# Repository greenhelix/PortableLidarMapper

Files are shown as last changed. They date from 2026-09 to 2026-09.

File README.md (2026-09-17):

# Portable LiDAR Mapper

> RPLIDAR C1 + Orange Pi 4 Pro + IMU를 백팩 어깨끈에 마운트하고 다니며 실내 2D 지도(로봇청소기 수준)와 실외 GPS 경로를 기록하는 개인용 프로젝트. (초기엔 텀블러형 케이스 구상이었으나 2026-09-16 어깨끈 마운트 방식으로 방향 전환 — 하단 폼팩터 히스토리 참고)

**현재 단계: Phase 1 — PC + 고정 공간에서 SLAM 파라미터 품질 검증 중** (보드 미도착, `docker/` 환경으로 PC에서 선개발).
상세 아키텍처/로드맵은 [`README_ARCHITECTURE.md`](./README_ARCHITECTURE.md), 세션별 작업 기록은 [`devlog/`](./devlog)를 참고.

---

## 개발 단계 (Phase)

| | **Phase 1 (현재)** | **Phase 2 (보드 도착 후)** |
|---|---|---|
| 장소 | PC + **고정된 한 공간** | 실내외 휴대 이동 |
| 목적 | SLAM/오도메트리 파라미터 품질 검증 | 실제 지도 생성 |
| 주 시각화 도구 | RViz2 (정밀 디버깅, `docker/run_dev.sh --rviz`) | Foxglove (폰 원격 접속) |
| 보드 | 없음 (PC로 대체) | Orange Pi 4 Pro 4GB |
| 다음 하드웨어 할 일 | — | 구매 → `hardware/orange_pi_4_pro_bringup_risks.md` 절차대로 이식 |
| Flutter 앱 | 우선순위 낮음 (스캐폴딩만) | 본격 개발 시작 |
| IMU(관성 측정 장치) 추가 | 안 함 (모듈 선정만 완료 — 9축, DFRobot SEN0374 추천) | 실제 장착 + `robot_localization`(EKF) 센서퓨전 연동 |

전환 조건: Orange Pi 4 Pro 구매 + 도착. 상세 이식 절차는 [`hardware/orange_pi_4_pro_bringup_risks.md`](./hardware/orange_pi_4_pro_bringup_risks.md).

**Phase 2는 하드웨어 도착 순서에 맞춰 페이지 0~3으로 더 세분화했습니다** (앱 개발은 rosbridge 프로토콜이 PC/보드 동일해서 오렌지파이 도착을 안 기다리고 지금부터 시작): 페이지0(지금, PC로 앱 선개발) → 페이지1(오렌지파이 도착, 라이다 재부착) → 페이지2(IMU 도착, 센서퓨전+휴대성 테스트) → 페이지3(물리버튼+실사용 필드 테스트+백엔드 구현). 상세는 [`README_ARCHITECTURE.md`](./README_ARCHITECTURE.md) 5.5번.

## 소프트웨어 아키텍처

이 프로젝트는 4가지 설계 원칙 위에 서 있습니다.

1. **레이어드 구조** — 하드웨어 → 드라이버 → ROS2 미들웨어(오도메트리/SLAM) → 데이터
   저장 → 시각화, 5개 계층으로 나뉘고 **계층 간 통신은 오직 ROS2 토픽/메시지로만**
   이루어집니다. 직접 함수를 호출하는 계층 간 결합이 없습니다.
2. **노드 단위 분리(교체 가능성)** — 라이다 드라이버, 오도메트리, SLAM, DB 로깅,
   AI 요약이 각각 독립된 ROS2 노드(프로세스)입니다. 그래서 라이다를
   mock ↔ 실기로, AI 모델을 provider 하나만 바꿔서 교체해도 **다른 코드는 무수정**입니다.
3. **환경 독립성(Docker)** — ROS2/SLAM 전부 Docker 컨테이너 안에서 돌기 때문에,
   호스트가 PC(Ubuntu 20.04)든 나중에 Orange Pi 4 Pro든 **같은 이미지가 그대로
   이식**됩니다. 이게 보드를 라즈베리파이→오렌지파이로 바꿔도 코드 리스크가 적었던
   핵심 이유입니다.
4. **어댑터 패턴** — `ai/`의 `AIProvider` 인터페이스처럼, 하드웨어·모델 종류를
   구체 구현이 아니라 인터페이스로 감싸서 나중에 무엇으로 바뀌어도 갈아끼우기만
   하면 되게 설계합니다.

전체 계층 구조, 각 계층의 책임, ROS2 노드 그래프, 데이터 저장 형식까지의 상세
내용은 [`README_ARCHITECTURE.md`](./README_ARCHITECTURE.md)에 있습니다 — 이 README는
요약이고, 그 문서가 정본입니다.

## 데이터 흐름

```mermaid
flowchart TD
    LIDAR["📡 RPLIDAR C1<br/>USB · 460800bps"] --> SLLIDAR["sllidar_node<br/>(실기 드라이버)"]
    MOCK["mock_scan_publisher<br/>(개발용 가짜 데이터)"] -.-> SCAN
    SLLIDAR --> SCAN(("/scan"))

    SCAN --> RF2O["rf2o_laser_odometry<br/>(스캔 기반 오도메트리)"]
    RF2O -- "odom→base_footprint (동적)" --> SLAM["slam_toolbox<br/>(SLAM)"]
    SLAM -- "map→odom" --> SLAM
    SLAM --> MAP(("/map"))

    MAP --> BRIDGE["rosbridge + rosapi<br/>:9090"]
    BRIDGE --> FOX["📱 Foxglove<br/>(브라우저/앱)"]
    BRIDGE -.-> APP["lidar_mapper_app<br/>(Flutter, 미연결)"]

    CLI["ros2 topic pub<br/>(수동 트리거)"] -.-> LOGGER["session_logger_node"]
    LOGGER --> AI["ai/ provider<br/>(NullProvider, 교체 가능)"]
    AI --> DB[("🗄️ SQLite<br/>data/rooms.db")]
```

실선 = 지금 자동으로 동작 확인된 경로. 점선 = 코드는 있지만 수동 트리거이거나(우측 DB 경로) 아직 연결 전(Flutter 앱).

## 확장 설계 — Flutter 앱 + 데이터 동기화 (2026-09-15, 설계 확정·구현 예정)

Phase 2(보드 도착 후 실사용)를 대비해 앱/백엔드 확장 구조를 설계했습니다. **아직 코드는 없고 설계만 확정된 상태**이며, 상세 내용은 [`README_ARCHITECTURE.md`](./README_ARCHITECTURE.md) 3.5번을 참고하세요.

- **온디맨드 연결 모델**: Orange Pi는 폰 연결 여부와 무관하게 자율로 계속 수집하고, 폰은 배터리 절약을 위해 평소엔 연결을 끊어두다가 확인하고 싶을 때만 붙는 구조.
- **Store-and-Forward(저장 후 전송)**: 오프라인(산속/지하 등)에서도 로컬 SQLite에 항상 먼저 저장하고, 연결되면 자동으로 PC DB에 밀린 데이터를 전송. [다이어그램](https://claude.ai/code/artifact/0686cb80-b7e4-421b-a3e3-a1d0db071f2b)
- **관계형 DB 스키마**: `locations`(장소) + `building_details`/`mountain_details`(장소 종류별 세부정보) + `sessions`(방문 기록)로 실내/실외를 하나의 스키마로 관리. [다이어그램](https://claude.ai/code/artifact/187c3b2d-13b7-421d-bd72-93b475922707)
- **진화형 지도 축적**: 같은 장소를 여러 번 방문해도 slam_toolbox의 `serialize_map`/`deserialize_map`으로 이전 지도에 이어서 매핑 — 재방문 데이터를 중복이 아니라 완성도를 높이는 히스토리로 누적.
- **라이다 한계 극복 전략**: 텀블러+가방 옆주머니 장착 특성상 생기는 가림각·회전오차·도보속도 문제를 `laser_filters`(ROS2 표준 필터 체인) + `robot_localization`(EKF 센서퓨전)으로 대응. [EKF 원리 그림](https://claude.ai/code/artifact/56d51d00-6c3a-4580-b798-53d9f7a12807)

### Flutter 앱 개발 진행 중 (2026-09-17~)
`app/lidar_mapper_app`에서 Tier1 기능부터 구현 시작. 연결 화면(rosbridge)은 코드
작성 완료, 나머지는 진행 중.

- **스캔/노이즈필터/누적지도 화면 데모 컨셉**: [인터랙티브 프리뷰](https://claude.ai/code/artifact/596148a7-35da-4410-bd0f-bc0dce5fa559)
  (원본 백업: [`app/lidar_mapper_app/demo/scan_monitor_preview.html`](./app/lidar_mapper_app/demo/scan_monitor_preview.html),
  링크는 비공개 상태 — 공유하려면 아티팩트 페이지에서 직접 "공유" 켤 것) —
  실제 데이터 대신 가짜 데이터로 Flutter `CustomPainter` 구현 시 예상되는 동작을
  미리 시연(Hz 슬라이더로 스캔속도-해상도 트레이드오프 확인, 벽처럼 보이는
  반사 노이즈를 탭으로 제거, 등산로/실내 환경 전환, 기기 이동에 따른 사각지대
  해소까지 재현).
- **앱 네비게이션 구조(하단 탭 4개: 홈/트래킹/목록/설정)**: 상세는
  [`README_ARCHITECTURE.md`](./README_ARCHITECTURE.md) 3.5.9번.

## 빠른 시작 (Docker)

```bash
# 최초 1회: 이미지 빌드
./docker/run_dev.sh --build

# mock 데이터로 파이프라인만 검증 (라이다 없이도 가능)
./docker/run_dev.sh
ros2 launch lidar_mapper_bringup bringup.launch.py use_mock:=true

# 실제 RPLIDAR C1 연결 시
./docker/run_dev.sh --with-lidar
ros2 launch lidar_mapper_bringup bringup.launch.py use_mock:=false lidar_serial_port:=/dev/ttyUSB1

# 고정 공간 정밀 디버깅용 RViz2 (PC 전용, X11 필요)
./docker/run_dev.sh --with-lidar --rviz
```

시각화는 `ws://localhost:9090`으로 [Foxglove](https://studio.foxglove.dev)에 접속하거나, 위 `--rviz` 옵션으로 RViz2를 띄우면 됩니다. 자세한 사용법은 [`docker/README.md`](./docker/README.md).

## 하드웨어

| 부품 | 내용 |
|---|---|
| 센서 | RPLIDAR C1 |
| 보드 | Orange Pi 4 Pro 4GB (Allwinner A733) — **구매 완료(배송 중, 2026-09-11)**, 상세는 [`hardware/board_price_tracking.md`](./hardware/board_price_tracking.md) |
| 폼팩터 | **백팩 어깨끈 마운트**(GoPro 표준 커넥터 방식) — 라이다+IMU 판은 어깨끈에, Orange Pi+배터리는 가방 내부에. 2026-09-16 확정, 상세는 아래 폼팩터 히스토리 참고 |

**완성 예상 컨셉 (렌더링 목업)**:

<table>
<tr>
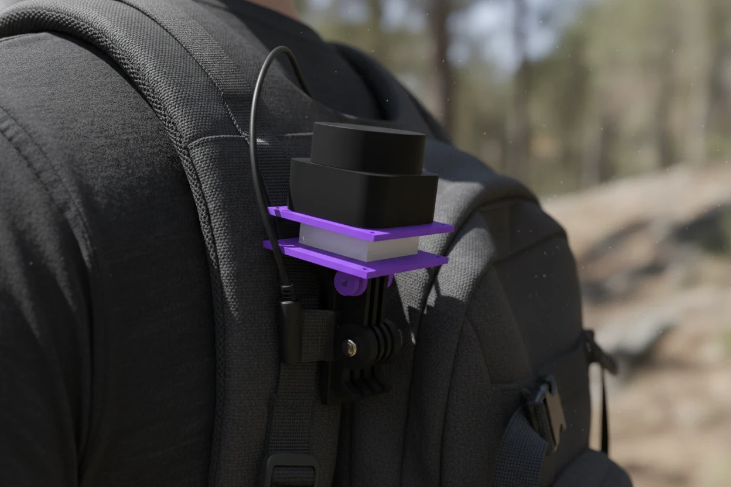
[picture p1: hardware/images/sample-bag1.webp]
어깨끈에 장착된 최종 목업 렌더링 — 근접
<td></td>
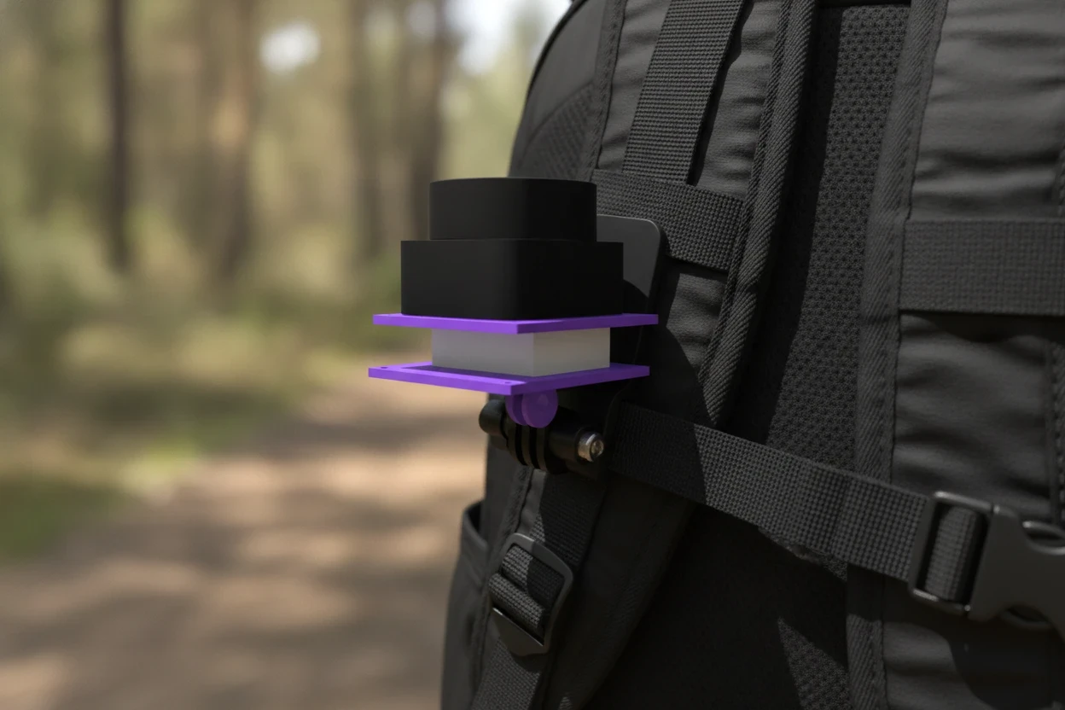
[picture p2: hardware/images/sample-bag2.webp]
어깨끈에 장착된 최종 목업 렌더링 — 전체
<td></td>
</tr>
</table>

### 폼팩터 검토 히스토리 (텀블러 → 어깨끈 마운트)

<details>
<summary><b>펼쳐서 전체 히스토리 보기</b> (스케치, 개념도, 검토 순서)</summary>

처음엔 **텀블러형 케이스**(라이다+보드+배터리를 원통 하나에 전부 내장, 백팩 옆주머니에 삽입)로 시작했으나, 몸/가방에 의한 가림각 문제와 특정 가방 치수 종속 문제 때문에 **어깨끈 마운트 분리형**(가벼운 센서 헤드만 어깨끈에, 무거운 보드+배터리는 가방 내부에)으로 방향을 바꿨습니다. 텀블러 개념 자체는 폐기하지 않고 계속 참고 자료로 남겨뒀습니다.

**1. 텀블러형 (초기 개념)**

텀블러형 케이스 개념도

라이다(위)-Orange Pi-배터리(아래) 순으로 원통 하나에 쌓는 구조. [상세 CAD](./hardware/cad/tumbler_shell_v2.scad)

사용자 스케치:
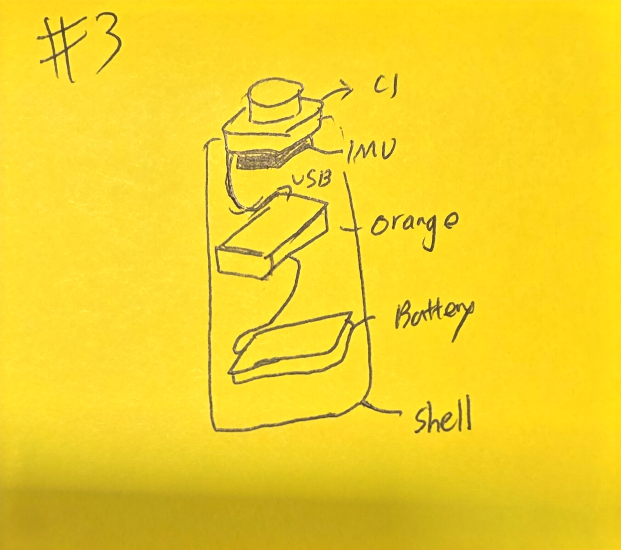
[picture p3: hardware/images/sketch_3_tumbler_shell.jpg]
사용자 스케치 3
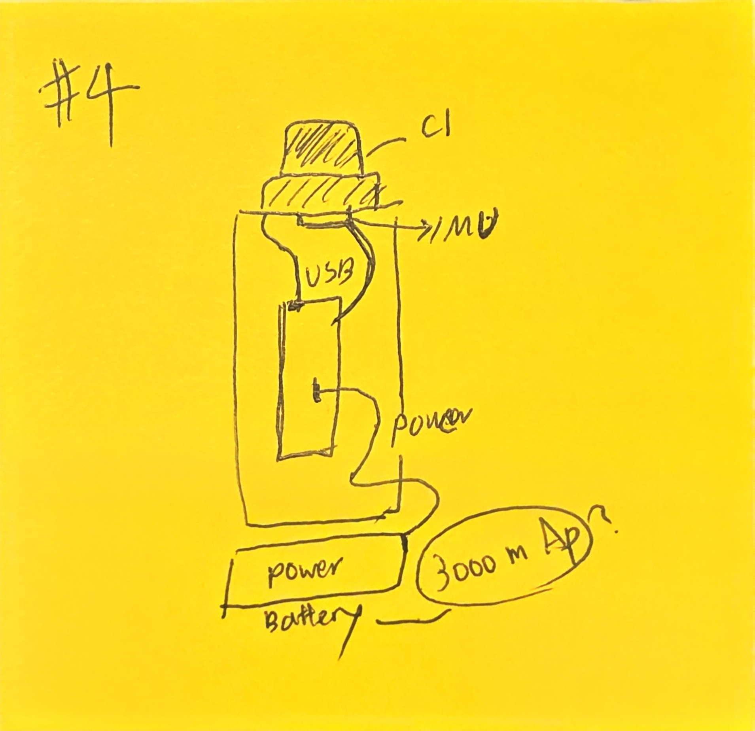
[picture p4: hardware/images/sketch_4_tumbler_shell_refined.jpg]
사용자 스케치 4(정리본)
 

**2. 중간 검토 — 어깨끈 분리형 여러 방식 비교**

어깨끈 마운트 개념도

가방 손잡이 관통형, 벨크로 클램프형, 목뒤 끈 수렴점형 등을 비교 검토. [전체 비교 아티팩트](https://claude.ai/code/artifact/8a0e3fea-5cf3-4b3d-bbbd-aff2ba56d551)

사용자 스케치:
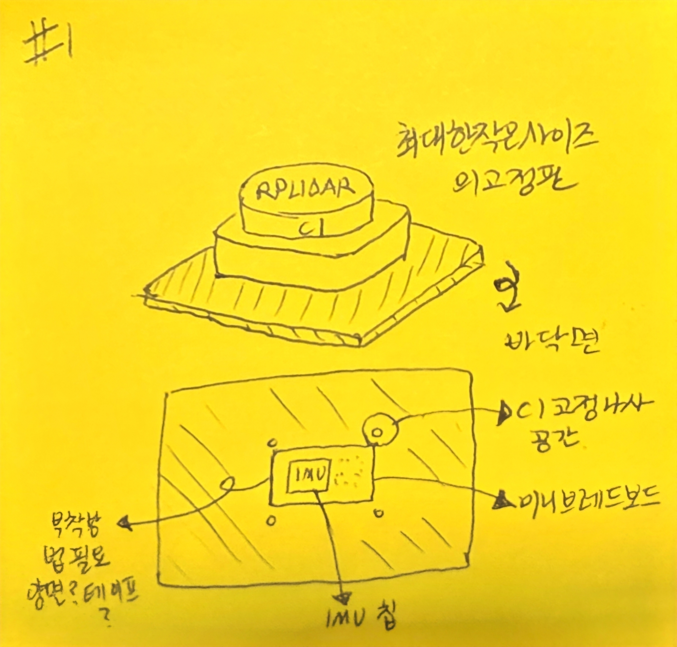
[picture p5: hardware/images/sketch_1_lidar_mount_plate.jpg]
사용자 스케치 1(마운트판)
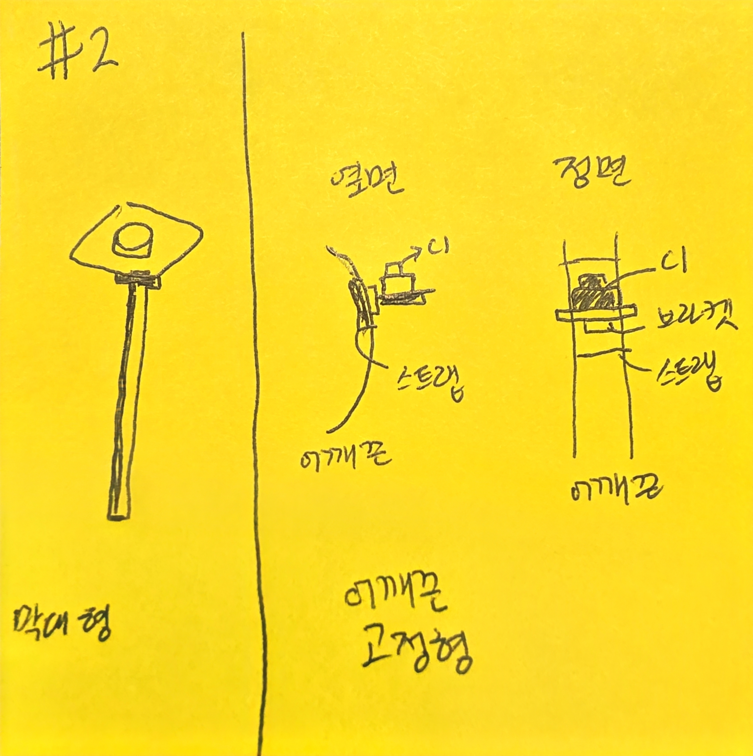
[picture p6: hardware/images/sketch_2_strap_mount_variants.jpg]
사용자 스케치 2(어깨끈 변형들)
 

**3. 최종 — GoPro 표준 커넥터 방식 (2026-09-16 확정)**

시중 GoPro 호환 어깨끈 마운트(볼조인트 없는 평버클+관통볼트 방식)를 구매해서 사용, 우리는 그 규격에 맞는 라이다+IMU 판만 제작. [상세 CAD](./hardware/cad/mount_plate_and_case_v1.scad)

구매한 실제 상용 마운트(360° 호환 표기 제품, 실제로는 평버클+관통볼트 방식):

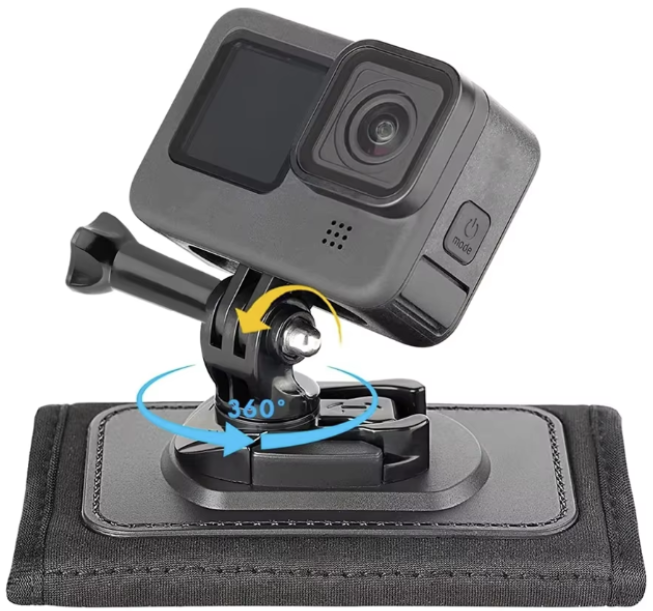
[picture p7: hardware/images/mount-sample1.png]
구매한 GoPro 호환 어깨끈 마운트 제품 사진


Shapr3D로 직접 설계한 라이다+IMU 판 (판 2장 사이 샌드위치 구조 + GoPro 커넥터):

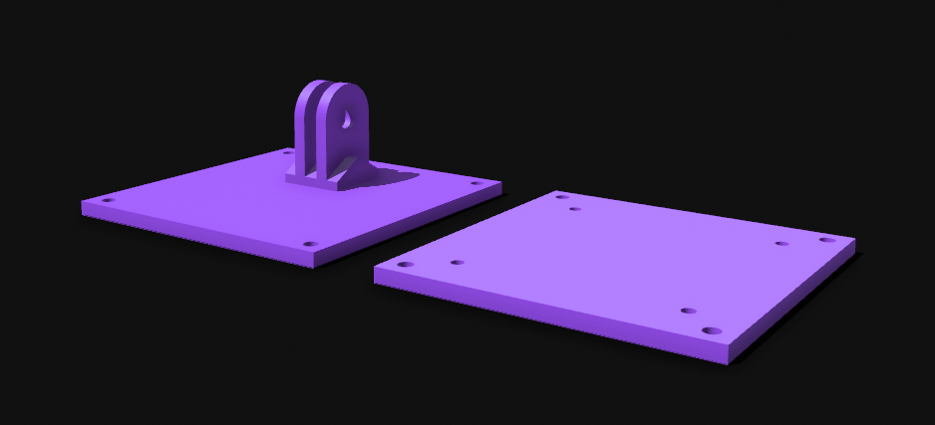
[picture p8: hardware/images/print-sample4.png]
Shapr3D로 설계한 최종 마운트 판 렌더링


가방 장착 목업은 위 "완성 예상 컨셉" 참고.

> 더 많은 각도/중간 검토 단계 사진(`mount-sample2,3`, `print-sample1~5` 등)은 `hardware/images/` 폴더에 전부 보관되어 있습니다.

</details>

## 저장소 구조

| 경로 | 내용 |
|---|---|
| `src/` | ROS2 워크스페이스 — `lidar_mapper_bringup`(launch 통합), `lidar_mapper_mock`(가짜 /scan), `lidar_mapper_db`(세션 로깅) |
| `ai/` | AI provider 어댑터 (`AIProvider` 인터페이스 + `NullProvider`, provider 이름만 바꾸면 모델 교체) |
| `app/lidar_mapper_app/` | Flutter 모바일 뷰어 (스캐폴딩, 아직 rosbridge 미연결) |
| `docker/` | 개발 환경 (Dockerfile, `run_dev.sh`, RViz2/Foxglove 가이드) |
| `config/` | slam_toolbox 파라미터, RViz2 기본 레이아웃 |
| `hardware/` | 텀블러 마운트 설계, 보드 가격/스펙 비교·리스크 조사 |
| `devlog/` | 세션별 개발 로그 (매 세션 시작 시 최신 로그부터 읽을 것) |
| `data/` `maps/` `bags/` | 런타임 산출물 (SQLite, 지도 파일, rosbag) |

## 문서 갱신 원칙

이 README와 `README_ARCHITECTURE.md`는 프로젝트의 첫 화면이자 최신 상태를 보여주는 문서입니다.
**구조가 바뀌거나(새 패키지/폴더), 하드웨어 결정이 바뀌거나, 개발 단계(Phase)가 넘어갈 때마다 반드시 갱신**합니다.
다이어그램은 Mermaid로 관리해서(이미지 파일 대신) 코드처럼 diff로 리뷰하고 계속 최신 상태를 유지합니다.

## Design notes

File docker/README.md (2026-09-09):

# 개발 환경 (Docker) 사용 가이드

PC(Ubuntu 20.04)와 Pi5(예정: Ubuntu 22.04 계열)의 배포판이 달라서,
호스트 OS에 ROS2를 직접 설치하지 않고 **Docker 컨테이너 안에서 ROS2 Humble
(Ubuntu 22.04 기반)로 통일**해서 개발한다. 이렇게 하면:

- 호스트 OS(20.04)를 건드리지 않는다.
- Pi5가 22.04 계열을 쓴다면 이 이미지를 그대로 옮겨서 이식 가능.
- WSL/Mac에서도 같은 이미지로 동일한 개발 경험을 유지할 수 있다.

## 공통 사용법

```bash
# 최초 1회 (또는 Dockerfile 수정 후) 이미지 빌드
./docker/run_dev.sh --build

# 이후에는 mock 전용 실행
./docker/run_dev.sh

# 컨테이너 진입 후 (최초 1회)
cd /lidar_ws
colcon build --symlink-install
source install/setup.bash

# mock 파이프라인 실행 예시
ros2 launch lidar_mapper_bringup bringup.launch.py use_mock:=true
```

Foxglove는 컨테이너의 `9090` 포트(rosbridge websocket)를 호스트에 그대로
publish 하므로, 호스트 브라우저/앱에서 `ws://localhost:9090`으로 접속하면 된다.

## 환경별 차이

### PC (Ubuntu 20.04, 라이다 물리 연결) — 메인 개발 환경
```bash
./docker/run_dev.sh --with-lidar
# 컨테이너 안에서:
ros2 launch lidar_mapper_bringup bringup.launch.py use_mock:=false lidar_serial_port:=/dev/ttyUSB1
```
`/dev/ttyUSB0`, `/dev/ttyUSB1`, `/dev/ttyACM0` 중 존재하는 장치를 자동으로
컨테이너에 패스스루하고, `dialout` 그룹 권한도 같이 넘겨서(`--group-add`) 실제
시리얼 포트를 열 수 있게 한다. 실제 RPLIDAR C1 테스트는 여기서만 진행한다.

**라이다가 응답 없어지면**: `sllidar_node`가 비정상 종료된 직후 장치가 응답
불가 상태로 걸릴 수 있다(실제로 한 번 겪음). 이럴 땐 소프트웨어로 재시도해도
안 풀리고, **USB 케이블을 뽑았다 다시 꽂으면** 정상 복구된다.

### RViz2 — 고정 공간 정밀 디버깅 전용 (Pi5 도착 전 Phase 1)
Pi5가 없어서 지금은 라이다를 한 자리에 고정해두고 SLAM/오도메트리 파라미터
품질을 다듬는 단계다. 이 단계에선 Foxglove보다 **RViz2가 더 정확하다** — 색상이
임의로 커스텀되지 않고 기본이 흑백(점유=검정/빈공간=흰색/미지=회색)이라
"이게 벽인지 빈 공간인지" 헷갈릴 일이 없다. 다만 RViz2는 웹앱이 아니라 로컬 GUI라
휴대 단계(Phase 2)에서 폰으로 보는 용도로는 못 쓴다 — 그건 계속 Foxglove가 담당.

```bash
xhost +local:docker   # 호스트에서 최초 1회 (컨테이너가 화면에 그릴 수 있게 허용)
./docker/run_dev.sh --with-lidar --rviz
# 컨테이너 안에서 (별도 터미널로 docker exec 하거나 & 로 백그라운드 실행):
rviz2 -d /lidar_ws/config/rviz_default.rviz
```
`config/rviz_default.rviz`에 Map/LaserScan/TF/Grid 디스플레이가 미리 설정되어
있어서 매번 수동으로 추가할 필요 없다.

**컨테이너를 오래 켜둔 채로 방치하지 말 것.** 며칠씩 방치하면 그 사이 쌓인
오래된 로그/누적 맵을 "방금 테스트한 결과"로 착각해서 잘못된 진단을 하게 된다
(2026-09-04~07 세션에서 실제로 겪음). 테스트 전엔 항상 컨테이너를 재시작해서
깨끗한 상태로 시작할 것.

### WSL2 — 코드 검증용, 실기 테스트는 선택사항
Docker 자체는 WSL2에서도 동일하게 동작하지만, USB 장치는 기본적으로
Windows가 점유하고 있어서 WSL 컨테이너에 바로 안 보인다.

- **mock 전용으로만 쓸 경우**: 추가 설정 없이 `./docker/run_dev.sh` 그대로 사용.
- **실제 라이다까지 WSL에서 테스트하고 싶을 경우**: Windows에
  [`usbipd-win`](https://github.com/dorssel/usbipd-win)을 설치하고,
  ```powershell
  usbipd list
  usbipd bind --busid <라이다 버스ID>
  usbipd attach --wsl --busid <라이다 버스ID>
  ```
  로 WSL에 장치를 붙인 다음 `./docker/run_dev.sh --with-lidar`를 실행한다.
  다만 안정성이 PC 네이티브보다 떨어지므로 필수 워크플로는 아니다.

### Mac (Apple Silicon/Intel) — mock 개발 + Foxglove 원격 시각화 전용
Docker Desktop for Mac은 컨테이너가 Linux VM 안에서 돌기 때문에 **물리 USB
패스스루를 지원하지 않는다.** 따라서 Mac에서는:

1. `./docker/run_dev.sh` (옵션 없이, mock만)로 파이프라인 로직/코드 작업.
2. 실기 검증은 PC에서 진행 중인 컨테이너에 원격으로 붙어서 확인:
   - PC의 rosbridge(9090)에 같은 네트워크에서 `ws://<PC IP>:9090`으로
     Foxglove 접속 → 실시간 지도 확인.
   - 코드 자체는 Claude Code 원격 세션/SSH로 PC에 붙어서 편집·실행.

## 참고
- `scripts/setup_env.sh`는 호스트에 직접 ROS2를 설치하는 옛 방식(참고/백업용)이며,
  현재 권장 경로는 이 Docker 방식이다.
- 이미지 안 배포판은 `ros:humble-ros-base` (Ubuntu 22.04) 기준.

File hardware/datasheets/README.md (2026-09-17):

# 부품 데이터시트 모음

이 프로젝트에서 실제 사용하는 부품들의 공식 데이터시트/매뉴얼을 모아둔 폴더.
링크가 죽거나 회사가 문서를 내려도 로컬에 원본이 남아있도록 보관.

| 파일 | 부품 | 출처 | 비고 |
|---|---|---|---|
| `rplidar_c1_datasheet.pdf` | RPLIDAR C1 (라이다 센서) | SLAMTEC 공식, 2024-03-12 rev.1.1 | 마운트 나사 규격(M2.5, 43x43mm, 삽입깊이 4mm 이하) 여기서 확인 |
| `bno055_datasheet.pdf` | BNO055 칩 (IMU, CJMCU-055 모듈에 탑재) | Bosch Sensortec 공식 | I2C 주소, 센서 스펙, 레지스터 맵 등 |
| `orange_pi_4_pro_user_manual_v1.4.pdf` | Orange Pi 4 Pro (메인보드) | Shenzhen Xunlong(orangepi.net) 공식 | **40핀 GPIO 핀맵(3.15절)**, ROS2 Humble 설치법(3.26.1절), Docker 설치법(3.22절), 발열 모니터링 명령(3.14절) 등 실전 절차 다수 포함 |

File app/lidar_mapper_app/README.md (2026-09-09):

# lidar_mapper_app

A new Flutter project.

## Getting Started

This project is a starting point for a Flutter application.

A few resources to get you started if this is your first Flutter project:

- [Learn Flutter](https://docs.flutter.dev/get-started/learn-flutter)
- [Write your first Flutter app](https://docs.flutter.dev/get-started/codelab)
- [Flutter learning resources](https://docs.flutter.dev/reference/learning-resources)

For help getting started with Flutter development, view the
[online documentation](https://docs.flutter.dev/), which offers tutorials,
samples, guidance on mobile development, and a full API reference.

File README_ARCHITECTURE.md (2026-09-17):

# 휴대용 라이다 지도 생성기 — 아키텍처 문서

> 텀블러형 케이스에 RPLIDAR C1 + Orange Pi 4 Pro를 장착하고 들고 다니며
> 실내 2D 지도(로봇청소기 수준) + 실외 GPS 경로를 기록하는 개인용 프로젝트

이 문서는 지금까지 확정된 내용을 기반으로 **하드웨어 → 소프트웨어 → 데이터 → 개발 프로세스** 전체를 구조화한다.
장비(보드)가 아직 없는 상태이므로, PC Ubuntu에서 먼저 100% 동일한 구조로 개발하고
보드가 도착하면 코드 변경 없이 이식하는 것을 목표로 설계한다.

---

## 0. 확정 사항 요약

| 항목 | 내용 |
|---|---|
| 센서 | RPLIDAR C1 (구매 완료) |
| 보드 | **Orange Pi 4 Pro 4GB** (Allwinner A733, 2x A76+6x A55) — 2026-09-08 결정, **2026-09-11 구매 완료(배송 중)**. Raspberry Pi 5에서 변경 (아래 사유 참고) |
| 폼팩터 | 텀블러형 케이스, 백팩 측면 포켓 휴대 |
| 목적 | 실내 2D SLAM 지도 + 실외 GPS 경로 기록 |
| SW 스택 | ROS2 Humble + slam_toolbox + rosbridge + Foxglove |
| 개발 순서 | PC Ubuntu 선개발 → 보드 도착 시 이식 |
| 개발 환경 | Docker (`docker/`) — PC 호스트 OS(20.04)와 무관하게 컨테이너 안에서 Ubuntu22.04+Humble로 통일. 상세: `docker/README.md` |

---

## 1. 레이어드 시스템 아키텍처

시스템은 5개 계층으로 나눈다. 각 계층은 독립적으로 테스트 가능해야 하며,
상위 계층은 하위 계층의 인터페이스(ROS2 토픽)에만 의존한다. 이렇게 하면
라이다가 없어도 3~5계층을 mock 데이터로 그대로 개발할 수 있다.

```
5. 시각화/앱     Foxglove(스마트폰) / RViz2(PC)
                        ▲  WebSocket
4. 저장/데이터    SQLite(방/가구) / 맵 파일(pgm,yaml) / devlog
                        ▲
3. ROS2 미들웨어  /scan → slam_toolbox → map_saver
                        ▲  LaserScan msg
2. 드라이버/통신  sllidar_ros2 (USB) / GPS 브릿지(MQTT)
                        ▲
1. 하드웨어       RPLIDAR C1 / Orange Pi 4 Pro / 전원부·GPS모듈
```

**핵심 설계 원칙**
- 계층 간 통신은 오직 **ROS2 토픽/메시지**로만 이루어진다 (직접 함수 호출 금지) → 나중에 라이다를 mock에서 실제 센서로 바꿔도 상위 계층 코드는 무수정.
- 3계층(SLAM)까지는 순수 소프트웨어이므로 **하드웨어 없이 100% 개발 가능**.
- 1~2계층만 하드웨어 의존적이며, 도착 즉시 교체(mock → real)한다.

---

## 2. 하드웨어 설계도

### 2.1 텀블러 마운트 단면 구조 (개념도)

```
        ┌────────────────┐  ← 상단 캡 (평탄화 디스크, 3D프린팅)
        │  ⊙ RPLIDAR C1   │     라이다 스캔 평면이 지면과 평행 유지
        │   (지름 ~75mm)  │     360도 스캔, 케이블 하단으로 관통
        ├────────────────┤
        │                │
        │   텀블러 몸체    │  ← 기존 텀블러/보온병 재활용 or 원통 케이스
        │  (단열재 제거)   │
        │                │
        ├────────────────┤
        │ Orange Pi 4 Pro │  ← 무게 중심을 낮추기 위해 하단 배치
        │  + 보조배터리    │
        └────────────────┘
              │
        백팩 측면 포켓에 수직으로 삽입
```

### 2.2 부품 리스트 & 배치 원칙

| 부품 | 배치 위치 | 이유 |
|---|---|---|
| RPLIDAR C1 | 최상단 | 360도 스캔 시야 확보, 몸/배낭에 가려지지 않게 |
| 평탄화 디스크 | 라이다 바로 아래 | 원통 뚜껑 곡면 위에서도 스캔 평면 수평 유지 |
| Orange Pi 4 Pro | 중~하단 | 발열 방출 공간 확보, 무게중심 하향 (발열이 큰 편이라 액티브 쿨링 필수 — `hardware/orange_pi_4_pro_bringup_risks.md` 참고) |
| 보조배터리 | 최하단 | 가장 무거운 부품 → 무게중심 안정화 |
| USB 케이블(라이다-보드) | 내부 관통홀 | 외부 노출 시 걸림/단선 위험 |
| GPS | 별도 (스마트폰 앱) | 자체 GPS 모듈 대신 스마트폰 GPS를 Wi-Fi/MQTT로 수신 (실내 GPS 무의미) |

### 2.3 검증해야 할 물리 제약
- **수평 유지가 핵심**: 라이다 스캔 평면이 기울면 SLAM 정확도 급락 → 텀블러가 기울어져도 라이다 마운트 자체는 수평 고정되는 짐벌/평탄화 구조 필요
- **진동은 허용, 기울기는 비허용**: 걷는 진동(좌우 흔들림)은 SLAM이 누적 보정 가능하지만 지속적 틸트는 누적 오차 유발
- **발열**: 보드(Orange Pi 4 Pro) + SLAM 연산 시 발열 있음(실제 리뷰로 확인된 리스크,
  `hardware/orange_pi_4_pro_bringup_risks.md` 참고) → 방열판/액티브 쿨러 필수, 밀폐 케이스 지양

> 상세 치수(C1 지름 75mm 기준 마운트 설계)는 실측 후 `hardware/tumbler_mount_design.md`에 업데이트 예정.

---

## 3. 소프트웨어 아키텍처 (ROS2 노드 그래프)

```
┌─────────────────┐    /scan (sensor_msgs/LaserScan)
│  sllidar_node    │ ────────────────────────────┐
│ (실제 C1 or Mock) │                              ▼
└─────────────────┘                    ┌────────────────────┐    /map (nav_msgs/OccupancyGrid)
                                        │  slam_toolbox        │ ──────────────┐
┌─────────────────┐   /gps/fix          │  (online_async)      │               ▼
│  gps_bridge_node │ ──────────────────▶│                       │    ┌─────────────────┐
│ (MQTT 구독)       │                    └────────────────────┘    │  map_saver_cli   │
└─────────────────┘                                                │  → .pgm / .yaml  │
                                                                    └─────────────────┘
                        rosbridge_server (WebSocket :9090)
                                        ▲
                                        │
                          Foxglove (스마트폰 브라우저 접속)
```

**패키지 분리 전략 (ROS2 워크스페이스)**
```
src/
├── lidar_mapper_bringup/   # launch 파일 모음 (실제 하드웨어 + SLAM + rosbridge 통합 실행)
├── lidar_mapper_mock/      # 하드웨어 없이 개발용 가짜 /scan 퍼블리셔
├── lidar_mapper_db/        # /session_event, /session_end 구독 → AI 요약 → SQLite 저장 (2026-09-01 구현)
├── (외부) sllidar_ros2      # RPLIDAR 공식 드라이버 (git clone)
└── (외부) slam_toolbox      # apt 설치
```

이렇게 나누는 이유: `bringup`은 "무엇을 실행할지"만 담당하고,
`mock`은 라이다 없이도 `/scan`을 흉내내는 **개발 전용 패키지**로 완전히 분리한다.
보드+실제 센서가 오면 launch 인자 하나(`use_mock:=false`)로 전환한다.

**저장소 최상위 구성 (2026-09-01 확정)**
```
app/    # Flutter 모바일 뷰어 앱 (app/lidar_mapper_app) — 언어: Dart
ai/     # AI 에이전트 provider 어댑터 자리. AIProvider 인터페이스 + NullProvider 기본값.
        # provider 이름만 바꾸면 Anthropic/OpenAI/중국계(Qwen 등) 어떤 모델로도 교체 가능.
docker/ # 개발 환경 (README_ARCHITECTURE 0번 항목 및 docker/README.md 참고)
```
언어 선택: 엣지·백엔드는 Python(ROS2 기존 스택과 통일), 모바일 앱은 Flutter(Dart, 크로스플랫폼).
마켓플레이스/랭킹/게임화(다중 사용자 데이터 공유)는 사용자가 여러 명이 되는 시점에나 의미가
생기는 확장 아이디어로, 지금 구조에는 반영하지 않고 기록만 해둔다.

---

## 3.5 확장 아키텍처: 온디맨드 연결 · Store-and-Forward · 라이다 한계 극복 · 진화형 지도 (2026-09-15 설계 확정)

Phase 2(보드 도착 후 실사용)를 대비해 Flutter 앱 + 백엔드 확장 구조를 설계했다.
**이 절은 전부 설계만 확정된 상태이고 아직 코드 구현 전**이다 — 5.4번 로드맵에서
진행 상황을 추적한다.

### 3.5.1 용어 정리
- **ROS2 노드**: 독립적으로 실행되는 하나의 프로세스(예: 라이다 드라이버, SLAM).
  노드끼리는 직접 호출하지 않고 **토픽(주제)** 을 통해 메시지를 주고받는다.
- **rosbridge**: ROS2 토픽/서비스를 WebSocket + JSON으로 바꿔서 브라우저/폰
  앱처럼 ROS2를 모르는 외부 클라이언트도 통신할 수 있게 해주는 게이트웨이
  (`:9090` 포트, 로컬망에서만 동작, 인터넷 불필요).
- **SLAM(동시적 위치추정 및 지도작성)**: "내가 어디 있는지"와 "주변 지도가
  어떻게 생겼는지"를 동시에 풀어내는 문제. 이 프로젝트에선 `slam_toolbox`가 담당.
- **오도메트리**: 절대 위치가 아니라 "직전 대비 얼마나 움직였는지"를 추정하는
  것. 바퀴 인코더가 없는 휴대 기기라 `rf2o_laser_odometry`(연속된 라이다 스캔
  비교)로 추정한다.

### 3.5.2 온디맨드 연결 모델 (배터리 절약)
- **Orange Pi = 자율 데이터 수집 엔진**. 폰(또는 물리 버튼)이 명시적으로 "수집
  시작"을 눌러야만 시작하고(부팅만으로 자동 시작 안 함 — 수평/장착 확인 전
  쓰레기 데이터 방지), 시작된 뒤로는 폰 연결 여부와 무관하게 계속 수집한다.
- **폰 = 온디맨드 모니터 + 중개자**. 평소엔 연결을 끊어(핫스팟 OFF) 배터리를
  아끼고, 확인하고 싶을 때만 핫스팟을 켜서 **mDNS(Avahi)** 로 `lidarmapper.local`
  같은 호스트이름을 찾아 접속한다(IP가 매번 바뀌어도 문제없음). 이미 아는
  SSID는 리눅스 NetworkManager가 알아서 재접속하므로 커스텀 코드가 필요 없다.

### 3.5.3 Store-and-Forward (저장 후 전송)
Orange Pi는 네트워크 유무와 무관하게 항상 로컬 SQLite에 먼저 저장(**STORE**)하고,
연결이 생기면 PC의 DB로 미전송분만 밀어올린다(**FORWARD**). 오프라인(산속/지하
등)에서도 100% 수집되고, 연결되면 자동으로 밀린 데이터가 업로드된다.

[다이어그램: data_sync_diagram](https://claude.ai/code/artifact/0686cb80-b7e4-421b-a3e3-a1d0db071f2b)

| 경로 | 용도 | 프로토콜 |
|---|---|---|
| 폰 ↔ Orange Pi | 실시간 확인/제어 | 기존 rosbridge WebSocket(:9090) 재사용 |
| Orange Pi → PC | 세션 종료 후 배치 전송(백업) | HTTP REST(POST), PC에 작은 FastAPI 엔드포인트 1개 |

MQTT 브로커/실시간 스트리밍 전용/클라우드 우선 업로드도 검토했으나, 오프라인
내구성이나 "최소구조" 원칙과 안 맞아 기각했다(대안 비교는 실제 구현 계획서 참고).

### 3.5.4 자동 데이터 최적화 (저장공간 관리)
지도(.pgm/.yaml)와 DB 메타데이터만 저장하는 지금 설계는 세션 1,000회 누적해도
~100MB 수준으로 사실상 안전하다. 위험한 건 원본 스캔 로그(rosbag, 세션당
~30~40MB)인데 **기본으로 꺼져 있음**. PC로 동기화 완료(`synced_at` 채워짐)된
세션은 일정 기간(예: 7일) 뒤 로컬 원본을 자동 삭제하는 정책을 예정하며,
동기화 안 된 데이터는 절대 자동 삭제하지 않는다.

### 3.5.5 관계형 DB 스키마 (실내/실외/산길 공통)
장소(`locations`)를 독립 개체로 두고, 장소 종류별 세부정보를 1:1 확장
테이블(`building_details`, `mountain_details`)로, 방문 기록을 `sessions`로
분리한 관계형 구조. 같은 장소를 여러 번 방문해도 장소는 한 번만 등록되고
세션만 늘어난다.

```sql
CREATE TABLE locations (
    id INTEGER PRIMARY KEY AUTOINCREMENT,
    location_type TEXT NOT NULL,          -- 'building' | 'mountain' | ...
    name TEXT NOT NULL,
    gps_lat REAL,
    gps_lon REAL,
    current_map_serialized_path TEXT,     -- 진화형 지도용, 3.5.6 참고
    map_version INTEGER DEFAULT 0
);

CREATE TABLE building_details (
    location_id INTEGER PRIMARY KEY REFERENCES locations(id),
    floor INTEGER, building_type TEXT
);

CREATE TABLE mountain_details (
    location_id INTEGER PRIMARY KEY REFERENCES locations(id),
    trail_name TEXT, trail_difficulty TEXT
);

CREATE TABLE sessions (
    id INTEGER PRIMARY KEY AUTOINCREMENT,
    location_id INTEGER REFERENCES locations(id),
    started_at TEXT NOT NULL, ended_at TEXT NOT NULL,
    map_pgm_path TEXT, map_yaml_path TEXT,
    summary TEXT, metadata_json TEXT,     -- 전용 테이블 없는 새 장소 종류용 escape hatch
    synced_at TEXT                        -- NULL = 미동기화
);
```

[다이어그램: db_schema_diagram](https://claude.ai/code/artifact/187c3b2d-13b7-421d-bd72-93b475922707)

### 3.5.6 진화형 지도 축적 (같은 장소 반복 방문 시 히스토리로 보완)
처음 방문에서 만드는 지도는 완성도가 낮을 수밖에 없다(30~50% 예상). slam_toolbox의
`serialize_map`/`deserialize_map` 서비스를 이용해 재방문 시 이전 지도를 불러와
**이어서** 매핑하면, 겹치는 구간은 스캔 매칭(loop closure)이 자동으로 정렬하고
빈 구석만 새로 채워진다 — 재방문 데이터가 중복이 아니라 보완으로 흡수된다.
`map_versions` 테이블(location_id, session_id, version, serialized_path 등)로
버전 히스토리를 덮어쓰지 않고 계속 쌓는다.

### 3.5.7 라이다 한계 극복 전략
텀블러+가방 옆주머니 장착 특성상 ①몸/가방에 시야 일부가 항상 가려짐,
②방향 전환/회전이 잦음, ③도보 속도로 스캔 간 겹침 부족, ④사람 등 동적
장애물, ⑤나무 많은 숲길처럼 2D 라이다가 놓치기 쉬운 환경 — 이 5가지를 새
알고리즘 없이 ROS2 표준 패키지로 대응한다.

- **가림각 대응**: `laser_filters` 패키지(ROS2 표준) — `LaserScanAngularBoundsFilter`
  (고정 각도 구간 무시), `LaserScanFootprintFilter`(자기 몸체 반사 제거),
  `LaserScanRangeFilter`/`LaserScanIntensityFilter`(근접/약한 반사 제거),
  `LaserScanSpeckleFilter`(고립 노이즈 제거), `ScanShadowsFilter`(물체 가장자리
  유령점 제거 — 나뭇가지 많은 환경에 유용).
- **회전 오차 보정**: `robot_localization`(EKF, 확장 칼만 필터)로 IMU와 rf2o
  라이다 오도메트리를 융합 — 회전 중엔 IMU를, 직선 이동 중엔 라이다를 더
  신뢰하도록 자동 가중. slam_toolbox에는 이 융합된 오도메트리를 입력한다.
  [다이어그램: ekf_diagram](https://claude.ai/code/artifact/56d51d00-6c3a-4580-b798-53d9f7a12807)
- **환경 프리셋**: SLAM 파라미터 + 라이다 필터 체인을 "실내"/"산길" 프리셋으로
  묶어서 세션 시작 전 선택 — Flutter 앱에서 프리셋 선택, 수동 파라미터 조절,
  필터 전/후 실시간 미리보기(테스트 모드)를 제공할 예정(Tier1-7).
- **3D 라이다는 채택 안 함**: 스피닝형(Livox Mid-360 ~$734, Unitree L1 단종)과
  solid-state ToF형(CygLiDAR D2, $181.95이나 시야각 120°/65°로 360° 회전
  스캔 전제와 안 맞음, 3D 사거리 2m로 짧음) 모두 검토했으나 비용 또는 구조
  전제 문제로 기각 — 알려진 한계로 문서화하고 위 대응으로 최대한 보완한다.

### 3.5.8 Flutter 앱 기능 확장 (Tier 1~3)
`app/lidar_mapper_app`에 MVVM(View→ViewModel(Riverpod)→Repository→
`ros_bridge_client`) 구조로 다음을 순차 구현 예정:

- **Tier 1(지금)**: DB 통신(get_sessions/log_event), 연결 설정, 수집 시작/정지
  버튼, 기기 점검(라이다/IMU/Orange Pi 상태/배터리 추정/네트워크), 기기 제어
  명령(리셋/DB 즉시전송), 실시간 지도/스캔 뷰어, 환경 프리셋+필터 조절 패널.
- **Tier 2(보드 도착 후)**: 세션 관리, 세션 상태/리셋 패널, 지도 히스토리 뷰
  (`flutter_map`/OpenStreetMap 기반, 실외 세션 GPS 핀 표시).
- **Tier 3(나중)**: 수동 지도 보정(터치 삭제), AI 기반 자동 하드웨어 제어,
  카메라/사물 인식 연동.

### 3.5.9 앱 네비게이션 구조 — 하단 탭 4개 (2026-09-17 확정)
IoT 동반 앱의 일반적인 패턴(iRobot Home: Home/Clean/History/Settings 등)을
참고해 확정. 연결 화면(rosbridge 주소 입력)은 탭이 아니라 **연결 전 게이트
화면**이고, 연결 성공 시 아래 4탭 메인 화면으로 전환된다(`go_router` 사용).

| 탭 | 내용 | 대응 Tier 항목 |
|---|---|---|
| **홈(진단)** | 라이다/IMU/Orange Pi/배터리 상태 체크 | Tier1-4 |
| **트래킹** | 실시간 스캔 레이더+누적지도(데모: [artifact](https://claude.ai/code/artifact/596148a7-35da-4410-bd0f-bc0dce5fa559)) + 시작/정지 버튼 + 저장 | Tier1-6 + Tier1-3 |
| **목록** | 저장된 세션 목록 — 세션명, 완성도%(2.6번 `completeness_note`), 좌표 입력란, 상단에 저장공간 여유 표시 | Tier2-7,8 + 2.5/2.6번 스키마 |
| **설정** | 연결 주소 변경, 환경 프리셋+필터 세부조절, **가이드(용어/옵션 설명집)** | Tier1-2,7 + 신규 |

**좌표 입력 — GPS 자동 획득으로 확정**: 사용자가 직접 좌표를 타이핑하지 않고,
"목록" 화면에서 📍 버튼을 누르면 `geolocator` 패키지로 위치 권한 요청 후
현재 위치를 자동으로 채운다. 좌표만으론 사람이 알아보기 어려우니 **OSM
Nominatim(무료 역지오코딩)**으로 대략적인 지명을 자동 제안하고 사용자가
수정 가능하게 한다(`flutter_map`과 같은 OSM 생태계라 궁합 좋음). 실내라 GPS
신호가 없으면 좌표 없이 이름만 입력하는 것으로 자연 폴백.

**설정 > 가이드 메뉴(신규)**: 라이다/센서 옵션값의 의미와 조정 방법을 앱 안에
용어집처럼 담아둔다 — 예: Hz(스캔 주파수) 높이면 회전은 빨라지지만 샘플레이트를
같이 안 올리면 각분해능이 떨어짐, 노이즈 필터 임계값의 의미, IMU/EKF 센서퓨전
개념 등. 매번 문서를 찾아보지 않고 앱 안에서 바로 확인 가능하게.

---

## 4. 데이터 아키텍처

| 데이터 | 형식 | 용량(추정) | 저장 위치 |
|---|---|---|---|
| 최종 2D 지도 | .pgm + .yaml | ~100KB (30평 기준) | `maps/` |
| 원본 스캔 로그 | rosbag2 (.db3) | ~30~40MB | `bags/` (필요시만 기록) |
| 방/가구 메타데이터 | SQLite | 수십 KB | `data/rooms.db` |
| GPS 경로(실외) | GeoJSON or SQLite | 경로 길이 비례 | `data/routes.db` |
| 개발 로그 | Markdown | - | `devlog/` |

**저장 원칙**: SLAM 실시간 처리에는 rosbag이 필요 없음(메모리 상에서 map으로 수렴).
디버깅/재현이 필요할 때만 선택적으로 rosbag 기록 → 저장공간 절약.

---

## 5. 개발 프로세스 & 개발 로그 규칙

### 5.1 개발 로그 원칙
- 위치: `devlog/YYYY-MM-DD_주제.md`
- 매 개발 세션 시작 시 **직전 로그를 먼저 읽고** 시작 (컨텍스트 복원)
- 로그 템플릿은 `devlog/TEMPLATE.md` 참고 — 목표/진행/막힌점/다음단계 4블록 고정
- 막힌 문제와 해결 방법은 반드시 기록 (동일 삽질 반복 방지)

### 5.2 장비 도착 전 진행 가능한 개발 순서 (PC Ubuntu 기준)

1. **환경 세팅**: `docker/run_dev.sh --build` (Docker 컨테이너 안에 ROS2 Humble +
   slam_toolbox + rosbridge 설치됨. 호스트가 20.04라 Humble 네이티브 설치가
   불가능해서 컨테이너로 통일 — 2026-08-31 결정, `devlog/2026-08-31_docker_kickoff.md`
   참고. 호스트 직접 설치용 `scripts/setup_env.sh`는 참고/백업 용도로 유지.)
2. **Mock 노드로 파이프라인 검증**: `lidar_mapper_mock` → `/scan` 가짜 데이터 → slam_toolbox가 뭔가 그리는지 확인 (지도 품질은 무의미, **파이프라인 연결 자체**를 검증하는 목적)
3. **DB 스키마 설계 & 저장 로직 작성**: 방/가구 좌표 저장 (`lidar_mapper_db`, 아직 미착수)
4. **Foxglove 연동 검증**: mock 데이터로 스마트폰에서 실시간으로 보이는지 확인
5. (C1 USB 연결 시) **1~4를 실제 센서로 교체**하고 그대로 동작하는지만 확인
6. (보드 도착 시) 워크스페이스 통째로 이식, 보드 전용 설정 도구(Orange Pi는
   `orangepi-config`/Armbian 설정)와 GPIO 관련 항목만 추가 설정

### 5.3 개발 단계 (Phase) — 2026-09-08 정의
보드(Orange Pi 4 Pro)가 없는 지금과, 보드로 실제 휴대 이동하는 이후는 목적 자체가 달라서 단계를 나눈다.

| | **Phase 1 (현재)** | **Phase 2 (보드 도착 후)** |
|---|---|---|
| 장소 | PC + **고정된 한 공간** | 실내외 휴대 이동 |
| 목적 | SLAM/오도메트리 파라미터 품질 검증 | 실제 지도 생성 |
| 주 시각화 도구 | **RViz2** (정밀 디버깅, 색상 왜곡 없음) | **Foxglove** (폰 원격 접속) |
| Foxglove 역할 | 원격 접속 연습/유지만 (병행) | 메인 |
| Flutter 앱(`app/lidar_mapper_app`) | 우선순위 낮음 | 의미 생김 — 본격 개발 |

RViz2는 로컬 GUI라 폰 원격 접속이 안 되기 때문에 Phase 2에서 Foxglove를 대체하지
않는다 — 지금 단계의 디버깅 전용 도구. 사용법은 `docker/README.md` 참고.

### 5.4 다음 단계 로드맵
- [x] Docker 개발 환경 구축 (`docker/run_dev.sh`) → ROS2 Humble 컨테이너 빌드 완료 (2026-08-31)
- [x] RPLIDAR C1 USB 연결 확인 (프로토콜 GET_INFO 응답 확인, 컨테이너 패스스루도 확인) (2026-08-31)
- [x] `lidar_mapper_db` 패키지 구현 + 세션 이벤트→AI 요약→SQLite 저장 흐름 검증 (2026-09-01)
- [x] Flutter 앱(`app/lidar_mapper_app`) 스캐폴딩 (2026-09-01)
- [x] `lidar_mapper_mock` 노드 + slam_toolbox + Foxglove로 mock 지도 시각화 확인 (2026-09-01)
- [x] 실제 RPLIDAR C1로 sllidar_ros2 붙여서 `/scan`·`/map` 실데이터 확인 (2026-09-01)
- [x] 오도메트리 부재로 지도가 안 넓혀지던 문제 해결: rf2o_laser_odometry(스캔 기반
      2D 레이저 오도메트리) 도입, `map→odom`은 slam_toolbox가 발행하도록 정리 (2026-09-01)
- [x] RViz2 디버깅 환경 추가 (`config/rviz_default.rviz`, Phase 1 정밀 진단용,
      X11 필요 — `docker/run_dev.sh --rviz`) (2026-09-08)
- [ ] **Phase 1 진행 중**: 고정 공간에서 SLAM/오도메트리 파라미터 품질 검증 (RViz2로 판단)
- [ ] (Phase 2로 넘어간 뒤) 실제로 걸어다니며 지도가 안 깨지는지 현장 검증
- [ ] (Phase 2) Flutter 앱에서 rosbridge(9090) 연결 최소 화면
- [ ] (Phase 2, 설계 확정 2026-09-08) **앱 기능: 수동 지도 보정(터치 삭제)**.
      배경: slam_toolbox는 사람 몸이 라이다를 잠깐 가려도 그 지점을 "벽"으로 영구
      기록하는 경향이 있고(자기 그림자 문제), 재매핑으로 시간이 지나면 자동
      갱신되긴 하지만(로보락과 동일 원리) 즉시 고치고 싶을 때를 위한 수동 삭제
      기능이 필요. 설계: 스캔 진행 중 폰 앱에서 지도 확대 → 검은 점 터치 →
      이어진 영역 flood-fill로 자동 선택 → 팝업(삭제/취소) → 삭제 시 해당 좌표를
      "강제 빈 공간" 보정 레이어에 기록(SQLite, `lidar_mapper_db` 확장) → 최종
      지도 = slam_toolbox 원본 위에 보정 레이어를 항상 마지막에 덮어써서 생성.
      slam_toolbox가 지도를 매번 처음부터 재계산하기 때문에 원본을 직접 수정하는
      대신 이 보정 레이어 방식이 필요.
- [ ] (Phase 2, 2026-09-10 기록) **앱 기능: 세션 상태 확인/리셋 패널**. 지도는
      디스크가 아니라 RAM에만 있어서 저장공간 문제는 없지만, 현재 지도 크기
      (`/map_metadata`의 width/height)와 리셋 버튼(내부적으로 파이프라인 재시작
      트리거)을 보여주면 사용자가 안심하고 확인/정리할 수 있음.
      `/slam_toolbox/clear_changes` 서비스 존재는 확인했으나 정확한 동작(전체
      초기화 vs 수동 보정 취소만)은 미검증 — 도착 후 실측 필요.
- [ ] 텀블러 실측 후 `hardware/tumbler_mount_design.md` 치수 확정 + 3D프린팅 도면
- [x] 보드 결정: Raspberry Pi 5 → **Orange Pi 4 Pro 4GB**로 변경 (2026-09-08,
      사유는 리스크 섹션 참고)
- [x] Orange Pi 4 Pro 구매 (2026-09-11, 배송 중)
- [ ] 도착 후 `hardware/orange_pi_4_pro_bringup_risks.md` 절차대로 이식 (Phase 2 시작 조건)

### 5.5 Phase 2 세부 페이지 (2026-09-15 확정)
Orange Pi/IMU 도착 시점이 서로 달라서, Phase 2를 하드웨어 도착 순서에 맞춰
3단계로 더 쪼갠다. **앱 개발은 rosbridge 프로토콜이 PC/보드 동일하다는 환경
독립성 원칙(1번) 덕분에, 오렌지파이 도착을 기다리지 않고 지금 PC 컨테이너
기준으로 먼저 시작한다** (Tier1 대부분이 하드웨어 무관 — 3.5.8번 참고).

| 페이지 | 트리거 | 하드웨어 작업 | 앱/백엔드 작업 |
|---|---|---|---|
| **0 (지금, 대기 중 병행)** | 없음 | 액티브 쿨링/microSD 등 부품 준비 (아래 체크리스트) | Tier1 대부분을 PC rosbridge로 개발/검증 (연결화면, 수집 시작/정지, 지도뷰어, 필터 프리셋 등) |
| **1. Orange Pi 도착** | 보드 수령 | 라이다 재부착 + `orange_pi_4_pro_bringup_risks.md` 절차대로 실기 기능 테스트 | 페이지0 앱 기능을 오렌지파이 주소로 재검증 |
| **2. IMU 도착** (미구매) | IMU 모듈 수령 | IMU 부착 + 기능 테스트 + `robot_localization`(EKF) 연동 + 휴대성(장착) 테스트 | 앱 개발 계속 — 기기 점검 화면에 IMU 상태 반영 |
| **3. 실사용 필드 테스트 단계** | 위 2단계 완료 후 | GPIO 물리 버튼 부착(0.7번) + 실내/산길 실제 도보 테스트로 라이다 필터·EKF 튜닝값 확정(0.8번) + 진화형 지도 재방문 실측(2.6번) | 백엔드 구현(DB 스키마 확장, `sync_node`) → Tier1 나머지(기기제어) + Tier2(세션관리, 지도 히스토리) 착수 |

**오렌지파이 도착 전 부품 체크리스트** (`orange_pi_4_pro_bringup_risks.md` 0번에 이미
있는 보조배터리 항목 외 추가):
- [ ] **액티브 쿨링(팬+방열판)** — 90°C 스로틀링이 실측 확인된 리스크라 가장
      급함, 보드 도착 직후 부하 테스트(체크리스트 6번)에 바로 필요
- [ ] microSD 카드(32GB+, 또는 eMMC) + 카드 리더기 — OS 이미지 굽는 용도
- [ ] (선택) 랜선 — Wi-Fi 미검증 리스크(2번)의 1순위 폴백
- [ ] (선택) HDMI 케이블+모니터 — 헤드리스(SSH) 설정 실패 시 폴백
- [ ] IMU 모듈(DFRobot SEN0374 추천, 페이지2용) — 아직 미구매
- [ ] GPIO 물리 버튼 + 점퍼케이블(페이지3용) — 수천원대, 저렴

---

## 6. 리스크 & 열린 질문
- **보드를 Raspberry Pi 5 → Orange Pi 4 Pro 4GB로 변경 (2026-09-08)**: Pi5가
  LPDDR4 메모리 품귀로 실구매가가 정가 대비 크게 뛴 상태라 대안을 비교함
  (Orange Pi Zero 3 - CPU 너무 약함, Orange Pi 5/5 Max(RK3588S/RK3588) - 정상
  스펙이지만 매물 가격이 애매하거나 상위 모델과 혼동됨). 최종적으로 Orange Pi 4 Pro
  (Allwinner A733, 2x Cortex-A76 + 6x Cortex-A55, 4GB LPDDR5, ₩74,800, 판매
  600+/평점 4.6 검증)로 결정. RK3588S(Orange Pi 5)보다 빅코어가 2개 적어 이론상
  약간 아래지만, Pi4B보다는 확실히 강하고 GPIO에 I2C/SPI가 있어 향후 IMU 확장에도
  유리. Docker 기반 아키텍처라 보드가 바뀌어도 이미지는 그대로 이식 가능(핵심 전제
  유지됨). 아직 실물 구매/테스트 전이라 실제 ROS2/Docker 구동 시 예상 못 한 이슈
  가능성은 남아있음. 스펙 비교표/가격 추이 기록은 `hardware/board_price_tracking.md` 참고.
- 텀블러 기울임 시 라이다 수평 유지 메커니즘은 아직 물리 설계 미검증 (프로토타입 필요)
- GPS-실내지도 좌표계 통합(실외↔실내 전환 시점 판단 로직)은 미설계 — 추후 별도 아키텍처 논의 필요
- **2D 라이다 단독으로는 빠른 손 회전/기울기에 근본적으로 취약** (2026-09-04 확인,
  방사형 노이즈 패턴). slam_toolbox 파라미터 튜닝으로 어느 정도 완화했지만, 완전히
  강건하게 하려면 IMU 추가 + `robot_localization`(EKF) 융합이 표준 해법 — 아직 미구매/미착수
- **테스트용 컨테이너를 장시간(며칠) 방치하면 안 됨**: 2026-09-04~07 세션에서
  실제로 컨테이너를 끄지 않고 3일 넘게 방치했다가, 그 사이 쌓인 오래된 로그/누적된
  지도를 "방금 튜닝한 결과"로 착각해서 엉뚱한 원인 분석을 한 적이 있음. 테스트
  시작 전엔 항상 `docker rm -f lidar_mapper_dev`로 재시작해서 깨끗한 상태로 시작할 것

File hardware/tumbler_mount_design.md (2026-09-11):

# 텀블러 마운트 설계도 (초안)

> RPLIDAR C1 실측 후 치수를 채워넣는 작업 문서. 지금은 뼈대만 잡아둔다.

## 0. 장비 장착 현황 (2026-09-10 기준)

| 부품 | 상태 |
|---|---|
| RPLIDAR C1 | ✅ 보유 (PC로 실측/실사용 검증 완료) |
| Orange Pi 4 Pro 4GB | ✅ 구매 완료(배송 중, 2026-09-11) (`hardware/board_price_tracking.md` 참고) |
| 텀블러/보온병 케이스 | ❌ 미확정 (후보 실측 전) |
| 보조배터리 | ❌ 미확정 (5V/3A 이상 출력 필요, 아래 1번 참고) |
| 평탄화 디스크/브라켓(3D프린팅) | ❌ 설계 전 |
| IMU(관성 측정 장치) | ❌ 미구매, Phase 2 향후 항목 (1.5번 참고) |

즉 지금은 **소프트웨어(Docker 이미지)만 준비된 상태**이고, 물리적 조립은 전부
착수 전이다. 아래 내용은 구매/제작 전에 미리 정리해두는 사양·리스크 문서다.

## 1. 전원/파워 규격

- **Orange Pi 4 Pro**: USB-C, **5V/3A(15W)** 입력. 일반 고속충전 보조배터리로
  충분할 가능성이 높음 (Raspberry Pi 5의 5V/5A 요구보다 낮음). 상세 비교는
  `hardware/board_price_tracking.md` 참고.
- **RPLIDAR C1**: 별도 전원 없이 **USB 버스 파워**로 동작 (모터+레이저 포함).
  보드의 USB 포트에서 직접 공급됨 — 즉 보드에 안정적으로 전원이 들어오면
  라이다는 자동으로 같이 해결됨. 다만 보드의 USB 포트 자체가 라이다 기동
  순간(모터 스핀업) 전류 스파이크를 감당할 수 있는지는 **실측 전 미지수**
  (`hardware/orange_pi_4_pro_bringup_risks.md` 3번 항목).
- **배선 우선순위**: 보조배터리 → (USB-C) → Orange Pi 4 Pro → (USB-A, 내부 케이블) → RPLIDAR C1.
  즉 배터리는 보드 하나에만 연결하고, 라이다는 보드를 거쳐 전원을 받는 구조 —
  배터리를 라이다에 직접 연결할 필요 없음(라이다는 표준 USB 전원 규격 5V를 씀).
- **필요한 배터리 용량(추정)**: Orange Pi 4 Pro(15W) + RPLIDAR C1(공식 스펙상 약 2~3W)을
  합쳐도 20W 미만. 10,000mAh(약 37Wh)급 보조배터리면 이론상 1.5~2시간 이상
  구동 가능할 것으로 추정(발열로 인한 스로틀링/변환 손실 감안 시 실측 필요).
- **확인할 것(구매 전 체크리스트)**:
  - [ ] 보조배터리 출력이 5V/3A(15W) 이상 명시돼 있는가
  - [ ] USB-C 케이블이 3A 이상 대응인가 (저가 케이블은 못 버티는 경우 있음)
  - [ ] 보조배터리의 "자동 절전(저전류 자동 꺼짐)" 기능이 있는지 — 있다면 SBC의
    안정적인 지속 전류 소모와 충돌해서 꺼질 위험은 낮지만, 혹시 모르니 구매
    후 장시간(30분+) 구동 테스트 필요

## 1.5 IMU(관성 측정 장치) 확장 계획 (2026-09-10, 향후 Phase 2)
IMU(Inertial Measurement Unit, 관성 측정 장치 — 자이로스코프+가속도계가 들어있는
저가 센서 모듈, 회사 이름 아님)를 나중에 추가하면 회전/기울기 추정 정확도가
올라간다 (devlog 참고). 아직 구매 전이지만 마운트 설계에 미리 자리를 반영해둔다.

- **원칙: IMU는 라이다와 같은 강체(rigid)에, 최대한 가까이 고정한다.** IMU가
  측정하는 건 "IMU 자신의" 기울기라서, 구조물이 조금이라도 휘면 라이다의 실제
  기울기와 오차가 생긴다.
- **위치**: 상단 평탄화 디스크(라이다 바로 아래)에 같이 부착 — 별도 브라켓 불필요,
  디스크 설계에 IMU 고정 홈만 추가.
- **배선**: I2C 통신(선 4개: 전원/접지/데이터 2선)이라 부피가 작음. 기존 라이다
  USB 케이블이 내려가는 관통홀을 같이 씀 — 별도 홀 안 뚫어도 됨.
- **가격/부착 가능 여부**: 저가형(MPU6050급) 기준 3,000~7,000원, Orange Pi 4 Pro의
  GPIO I2C로 연결 가능 (정확한 핀 번호는 보드 실물 핀아웃 문서로 확정 예정).
- **소프트웨어**: `base_footprint→imu_link` 고정 좌표(TF) 등록 + `robot_localization`
  (EKF)으로 rf2o와 융합. 지금 당장은 안 함 — Phase 2, 몸통 가림 등 더 급한
  물리적 문제 해결 이후로 순서를 미뤄둠.

## 1.7 부품 치수 기반 부착 가능성 검토 (2026-09-10)

라이다(⌀75mm×H40mm)/Orange Pi 4 Pro(89×56mm, 웹 검색으로 실치수 확인)/IMU(21×16mm)
크기를 실제로 겹쳐서 스케일 다이어그램으로 검토함.

- **결론: 완전 커스텀 하드케이스는 불필요.** 지름 제약의 진짜 병목은 라이다
  (⌀75mm)지 보드나 IMU가 아님 — 보드를 세로로 세우면(89mm를 높이 방향, 56mm를
  지름 방향으로) ⌀70~90mm대 텀블러에 여유 있게 들어감.
- **다만 "그냥 부착"도 아님** — 사각형 보드가 원통 안에서 저절로 안 서 있으니,
  세로로 고정해줄 작은 내부 브라켓("슬레드")은 필요. 이미 4번 파츠 목록에 있던
  "보드 고정 브라켓"과 동일 항목 — 새 작업 추가가 아니라 필요성이 치수로 재확인됨.
- **남은 진짜 불확실성**: 텀블러 후보 3종을 아직 실측 안 함. 실제 안지름(내경)이
  56mm보다 좁은 극단적 모델이면 이 결론이 바뀔 수 있음 — 그래서 7번 TODO의
  "텀블러 실측"이 지금 제일 중요한 다음 행동.

## 2. 기준 치수 (RPLIDAR C1 공식 스펙 기준, 실측 전)
- 라이다 본체 지름: 약 75mm
- 라이다 높이: 약 40mm (하단 케이블 커넥터 제외)
- 스캔 평면: 라이다 상단면 기준 수평, 360도

## 3. 조립 순서 (개념)
1. 텀블러/보온병 뚜껑을 제거하고 평탄화 디스크로 대체
2. 평탄화 디스크 중앙에 C1 장착 구멍(지름 75mm) 가공 또는 3D프린팅
3. 디스크 하단에서 USB 케이블을 텀블러 내부로 관통
4. 텀블러 내부 중~하단에 보드(Orange Pi 4 Pro) 고정 브라켓 배치
5. 최하단에 보조배터리 배치 (무게중심 하향)

## 4. 3D프린팅 파츠 목록 (예정)
| 파츠명 | 역할 | 상태 |
|---|---|---|
| 상단 평탄화 디스크 | 라이다 수평 고정 + IMU 동반 고정(1.5번 참고) | 설계 전 |
| 보드(Orange Pi 4 Pro) 고정 브라켓 | 보드 진동 방지 고정 + 통풍 확보 | 설계 전 |
| 케이블 정리 클립 | USB 케이블 단선 방지 | 설계 전 |
| (검토) 액티브 쿨링팬 마운트 | 발열 대응 (아래 5번 참고) | 설계 전 |

## 5. 검증 체크리스트 (프로토타입 완성 후)
- [ ] 텀블러를 기울여도 라이다 스캔 평면이 수평을 유지하는가
- [ ] 걷는 진동에서 SLAM 지도가 심하게 왜곡되지 않는가
- [ ] 보드 발열이 케이스 내부에 갇히지 않는가 — Orange Pi 4 Pro는 부하 시 90°C까지
  금방 올라간다는 실제 리뷰가 있어(`hardware/orange_pi_4_pro_bringup_risks.md`),
  패시브 방열판만으론 부족할 가능성 높음. **통풍 구멍 + 액티브 쿨링팬을 기본
  전제로 설계**
- [ ] 배낭 측면 포켓에 들어가는 전체 높이/지름인가

## 6. 백팩 측면 포켓 장착 시 예상 문제 & 데이터 수집 전략 (2026-09-10)

실제 착용 형태(백팩 옆 물병 주머니에 텀블러를 꽂고 다니는 방식)를 미리 따져보면,
지금까지 PC 테스트에서는 없던 문제가 새로 생긴다.

### 문제 1: 몸통에 의한 만성적 반쪽 가림 (자기 그림자)
라이다가 몸 옆(측면 포켓)에 있으면, **몸통을 향한 방향은 항상 몸/가방 본체에
가려진다.** PC에서 손에 들고 테스트할 때 겪었던 "몸이 순간적으로 가리는" 문제
(devlog 2026-09 기록)와 달리, 이건 **일시적이 아니라 상시 발생하는 가림**이라
훨씬 심각하다. 360도 중 실질적으로 유효한 시야는 몸 바깥쪽 절반 정도로 예상.

- **대응 방향 (구현은 나중, 지금은 설계 메모)**:
  - 몸쪽으로 향하는 특정 각도 범위는 처음부터 "믿을 수 없는 데이터"로 간주하고
    필터링(각도 마스킹)하는 게, 그 잘못된 근접 반사를 지도에 벽으로 잘못 새기는
    것보다 낫다 — sllidar 드라이버 또는 그 이후 전처리 노드에서 특정
    `angle_min`~`angle_max` 구간을 무시하는 옵션 검토.
  - 한쪽이 항상 안 보이는 게 원천적 한계이므로, **제자리에서 도는 게 아니라
    실제로 몸 방향을 바꿔가며(또는 건물을 한 바퀴 도는 경로로) 이동해야
    사각지대가 채워진다** — 이전에 "회전만으론 안 되고 이동해야 한다"고
    정리했던 결론이 여기서는 "이동뿐 아니라 몸의 방향 자체도 바꿔야 한다"로
    한 단계 더 강해짐.

### 문제 2: 걸음걸이로 인한 주기적 다리 가림
측면 포켓 높이는 대략 골반~허벅지 높이. 이 높이는 **걸을 때 자기 다리가 스캔
평면을 주기적으로 스쳐 지나가는 높이**다. 문제 1(상시 가림)과 별개로, 걸음
주기마다 반복적으로 짧은 거리(다리)가 잡혔다 빠졌다 하면서 노이즈를 만들 수 있다.

- **대응 방향**: 최소 감지 거리(`range_min`) 조정이나, 아주 가까운(수십cm 이내)
  반사는 신뢰도를 낮게 주는 후처리를 고려. 근본적으로는 마운트 높이를 허벅지보다
  높게(허리~가슴 높이) 가져가는 게 이상적이지만, 그러면 무게중심이 올라가서
  안정성과 트레이드오프 — 실측 프로토타입에서 직접 비교 필요.

### 문제 3: 흔들림/기울기 안정성
포켓은 물병 정도 굵기를 헐겁게 잡아주는 구조라, 걸을 때 완전히 고정되지 않고
흔들리거나 살짝 기운다. 2D 라이다는 기울기에 취약하다는 게 이미 확인된 근본
한계(devlog 2026-09-04) — 여기에 포켓의 헐거운 고정력까지 더해지면 실제로는
PC 손잡이 테스트보다 더 불안정할 수 있다.
- **대응 방향**: 텀블러 하단부를 포켓 폭에 맞춰 약간 타이트하게(또는 포켓 안에
  고정 스트랩 추가) 만드는 물리적 보완이 소프트웨어 튜닝보다 우선.

### 문제 4: 상단 돌출부 충돌/노출
라이다가 케이스 상단에 있어야(가려지지 않게) 하니, 가방 위로 튀어나오는 구조가
된다 — 문틀, 나뭇가지, 사람 어깨 등에 부딪힐 위험. 실사용 전 라이다 상단에
간단한 충격 보호 캡(스캔은 방해 안 하는 낮은 테두리 정도) 검토.

### 데이터 수집 전략 요약
1. 몸쪽 사각지대는 소프트웨어로 마스킹하거나 무시 (완전히 없앨 수 없는 한계로 인정)
2. 같은 자리에서 뱅뱅 돌기보다 **실제로 공간을 걸어서 순회**하는 방식으로 수집
   (여러 지점에서 "바깥쪽 절반"이 겹치면서 전체 커버리지 확보)
3. 마운트 높이는 허리~가슴 사이에서 실측 프로토타입으로 절충점 탐색
4. 정지 테스트(Phase 1, PC)에서 이미 튜닝한 노이즈 필터링(occupancy 확정 기준)이
   이런 실사용 노이즈에도 여전히 도움이 되지만, 완전한 해법은 아님 — 최종적으로는
   실제 착용 후 현장 검증(Phase 2)에서 재조정 필요

## 7. 확장 아이디어: 소형 카메라 (Phase 1·2 완료 후 검토, 2026-09-10)
저화질 소형 카메라를 추가해서 사물 인식(방/가구 라벨링)에 쓰는 아이디어를 검토함.

- **정확도/속도 향상용으로는 부적합**: 몸통 가림 문제를 못 풀어주고(카메라도 같은
  방향에서 같이 가려짐), 빠른 회전 시 저가 카메라는 모션 블러로 오히려 라이다보다
  약함. 이 두 문제의 정답은 카메라가 아니라 IMU(1.5번).
- **가치가 있는 지점은 "의미 부여"**: "이 방은 침대가 있으니 침실" 같은 라벨링은
  `ai/` provider + `lidar_mapper_db`(방/가구 메타데이터) 구조와 맞음 — 지도의
  정확도가 아니라 풍부함을 더하는 별도 기능.
- **주의**: Orange Pi 4 Pro가 이미 발열로 스로틀링되는 걸로 확인된 상태(위험 문서
  참고)라, 카메라+인식 모델 연산을 더 얹으면 오히려 전체 성능이 나빠질 수 있음.
- **순서**: Phase 1(지도 품질)과 Phase 2 초반(몸통 가림 등 물리적 문제) 해결
  이후에나 검토할 항목. 지금 할 일 아님 — 아이디어만 기록.

## 8. TODO
- [ ] 실제 C1 실측 (지름/높이/무게)
- [ ] 후보 텀블러 3종 이상 실측 비교 (**1.7번 결론에 따라 지금 가장 중요한 항목**)
- [ ] 평탄화 디스크 CAD 초안 (Fusion360 또는 Tinkercad)
- [ ] 위 6번 문제들을 검증할 프로토타입 착용 테스트 계획 수립 (Phase 2 초입)

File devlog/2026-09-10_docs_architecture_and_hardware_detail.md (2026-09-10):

# 2026-09-10 개발 로그 — README 잔재 정리, 아키텍처 설명 보강, 하드웨어 상세화

## 오늘의 목표
- 어제 커밋에서 놓친 "Raspberry Pi 5" 잔재 정리
- 최상위 README에 소프트웨어 아키텍처 설명 추가 (지금까지 다이어그램만 있었음)
- 하드웨어 문서를 실제 작업 착수 수준으로 상세화 (전원, 장착 현황, Orange Pi 설정)
- 백팩 측면 포켓 장착 시 예상되는 문제와 데이터 수집 전략 정리

## 진행 내용
- **README 잔재 정리**: `README_ARCHITECTURE.md` 안의 ASCII 다이어그램, 부품
  리스트, 로드맵, Phase 정의 섹션에 남아있던 "Raspberry Pi 5"/"Pi5" 표현을
  전부 "Orange Pi 4 Pro"/"보드"로 정정. 사용자가 지적("REAME Architechture
  업데이트가 안된거 같은데?")해서 발견함 — 어제 요약 표만 고치고 본문은
  놓쳤던 실수.
- **README.md에 아키텍처 설명 추가**: 다이어그램만 있고 말로 된 설명이 없다는
  지적에 따라, "소프트웨어 아키텍처" 섹션 신설 — 레이어드 구조/노드 단위
  분리/Docker 환경 독립성/어댑터 패턴 4가지 설계 원칙을 프로즈로 정리.
- **`hardware/tumbler_mount_design.md` 대폭 확장**:
  - 0번: 장비 장착 현황 표 (뭘 갖고 있고 뭘 안 갖고 있는지 한눈에)
  - 1번: 전원/파워 규격 — Orange Pi(5V/3A) + RPLIDAR C1(USB 버스파워)
    배선 우선순위, 배터리 용량 추정(10,000mAh급으로 1.5~2시간 추정), 구매 전
    체크리스트
  - 6번(신설): **백팩 측면 포켓 장착 예상 문제 4가지** — (1) 몸통에 의한 상시
    반쪽 가림(자기 그림자가 일시적이 아니라 영구적이 됨), (2) 걸음걸이로 인한
    주기적 다리 가림(마운트 높이가 하필 다리 스쳐가는 높이), (3) 포켓의 헐거운
    고정력으로 인한 흔들림/기울기, (4) 상단 돌출부의 물리적 충돌 위험. 각각에
    대한 대응 방향(각도 마스킹, 이동+몸 방향 전환으로 커버리지 확보, 마운트
    높이 절충, 충격 보호 캡)까지 기록.
- **`hardware/orange_pi_4_pro_bringup_risks.md`에 상세 설정 절차(5번) 신설**:
  OS 이미지 설치 → 네트워크/SSH → Docker 설치 → 프로젝트 이식(git clone +
  run_dev.sh) → GPIO/I2C 활성화(향후 IMU용, 정확한 핀은 실물 문서 필요) → 발열
  모니터링 명령어까지 Armbian 관례 기준으로 예상 절차 작성. 도착 후 실측
  명령어로 덮어쓸 것이라고 명시.

## 막힌 문제 & 해결
| 증상 | 원인 | 해결 방법 |
|---|---|---|
| 어제 보드 결정 반영이 불완전했음 | 요약 표만 고치고 문서 전체를 grep하지 않음 | 파일 전체 재검색 후 일괄 수정, 메모리에도 "전체 grep 필수" 교훈 추가 |

## 다음 단계
- Orange Pi 4 Pro 실제 구매
- 텀블러 케이스 후보 실측 (`hardware/tumbler_mount_design.md` TODO)
- 도착 후 `hardware/orange_pi_4_pro_bringup_risks.md`의 예상 절차를 실측으로 교체
- 몸통 가림 각도 마스킹은 실측 프로토타입 확보 후 구현 착수

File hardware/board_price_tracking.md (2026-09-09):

# 보드 가격/스펙 추적 (Raspberry Pi vs Orange Pi)

> 이 문서는 시간이 지나며 가격이 바뀔 때마다 아래 "가격 관찰 기록" 표에
> 새 행을 추가하는 방식으로 계속 갱신한다. 최종 구매 결정 사유는
> `devlog/2026-09-08_board_decision_orange_pi_4_pro.md` 참고.

## 1. 스펙 비교표

| 모델 | SoC | CPU 구성 | RAM | GPIO/확장 | 비고 |
|---|---|---|---|---|---|
| Raspberry Pi 5 4GB | Broadcom BCM2712 | **4x Cortex-A76 @ 2.4GHz** (전부 빅코어) | 4GB LPDDR4X | 40핀, PCIe | 원래 후보. 정가는 저렴하나 실구매가 폭등 |
| Raspberry Pi 4B | Broadcom BCM2711 | 4x Cortex-A72 @ 1.5GHz (구세대) | 2/4/8GB | 40핀 | CPU가 확실히 약함 |
| Raspberry Pi Zero 2 W | Broadcom BCM2710A1 | 4x Cortex-A53 @ 1.0GHz | 512MB | 제한적 | RAM 부족, SLAM 불가·송신 전용 |
| Orange Pi Zero 3 (4GB) | Allwinner H618 | 4x Cortex-A53 (빅코어 없음) | 4GB LPDDR4 | 제한적 | CPU 너무 약함, 가격도 안 저렴 |
| **Orange Pi 4 Pro 4GB (선택)** | Allwinner A733 | **2x Cortex-A76 @ 2.0GHz + 6x Cortex-A55** | 4GB LPDDR5 | 40핀(I2C/SPI/UART), M.2 NVMe, USB-C 5V/3A | 가격 대비 밸런스 최선 |
| Orange Pi 5 4GB | Rockchip RK3588S | 4x Cortex-A76 @ 2.4GHz + 4x A55 @ 1.8GHz | 4GB | 40핀, M.2 | 스펙은 가장 강하나 신뢰할 매물을 못 찾음 |
| Orange Pi 5 Max 8GB | Rockchip RK3588 (풀칩) | 8-core @ 2.4GHz | 8GB LPDDR5 (4GB 옵션 없음) | 2.5G LAN, PCIe | 상위 등급, 8GB부터 시작이라 더 비쌈 |

**핵심 요약**: Orange Pi 4 Pro는 Raspberry Pi 4B보다는 확실히 강하고(A76 코어 2개 보유),
Orange Pi 5(RK3588S)보다는 빅코어가 2개 적어(2 vs 4) 이론상 한 단계 아래다.

## 2. 가격 관찰 기록

| 날짜 | 모델 | 가격 | 출처 | 비고 |
|---|---|---|---|---|
| 2026-09-08(이전, 사용자 시장 조사) | Orange Pi Zero 3 (1~2GB) | 약 2.5만~3.5만원 | 사용자 리서치 | 저용량 모델 기준 |
| 2026-09-08(이전, 사용자 시장 조사) | Orange Pi 5 4GB | 약 7만~8만원대 | 사용자 리서치 | 정상 시세로 추정했던 값 |
| 2026-09-08(이전, 사용자 시장 조사) | Raspberry Pi Zero 2 W | 약 2.5만~3만원 | 사용자 리서치 | - |
| 2026-09-08(이전, 사용자 시장 조사) | Raspberry Pi 4B 2GB (중고) | 약 4만~5만원 | 사용자 리서치 | 중고 시세 |
| 2026-09-08 | Orange Pi Zero 3 4GB | ₩91,800 (30% 할인, 원가 131,143) | AliExpress (Orange pi 공식 스토어) | 판매 이력 확인 안 됨 |
| 2026-09-08 | Orange Pi 4 Pro 4GB | ₩74,800 | AliExpress, 65개 판매 | 첫 리스팅 |
| 2026-09-08 | Orange Pi 4 Pro 4GB | ₩74,800 | AliExpress, **600+개 판매 / 4.6점** | 같은 보드, 신뢰도 더 높은 리스팅 → **최종 선택** |
| 2026-09-08 | Orange Pi 5 4GB (RK3588S) | ₩204,600 (60% 할인, 원가 511,500 표기) | AliExpress "AvaCore Store", 1개 판매 | 가짜 할인 패턴 의심, 비공식 리셀러 → 기각 |
| 2026-09-08 | Orange Pi 5 Max 8GB (RK3588 풀칩) | ₩261,000 | AliExpress (Orange pi 공식 스토어), 42개 판매/5.0점 | 상위 모델(4GB 옵션 없음), 정상 가격이나 등급이 다름 |
| 2026-09-08 | Raspberry Pi 5 4GB | **₩198,000** (국내) | 웹 검색(다나와 등 국내 쇼핑몰) | 이 프로젝트가 Orange Pi를 검토하게 된 원인. 사용자가 "20~30만원대 아니냐"고
지적해서 재검색 후 확인함 (이전에 "확인 안 함"으로 적어둔 게 부정확했음) |
| (해외 참고) 2025-11 → 2026-04 | Raspberry Pi 5 16GB | $120 → $205 (약 2배) | Tom's Hardware, Raspberry Pi 공식 블로그 | 5개월간 3차례 가격 인상. 고용량일수록 타격 큼 |
| (해외 참고) 2025년 초 → 2026-02 | Orange Pi 5B 16GB | $160 → $312 (약 2배) | 웹 검색 | **오렌지파이도 동일한 위기에 노출됨** — "기성 칩이라 안전하다"는 이전 설명은 틀림 (아래 5번 정정 참고) |
| 2026-09-08 | Raspberry Pi 5 2GB | ₩109,000 | icbanq (국내, 라즈베리파이 브랜드존) | - |
| 2026-09-08 | Raspberry Pi 5 4GB | **가격 미표시** | icbanq | 품절/재입고 불확실 가능성 — 용량별 중 유일하게 가격 표시 안 됨 |
| 2026-09-08 | Raspberry Pi 5 8GB | ₩293,000 | icbanq | - |
| 2026-09-08 | Raspberry Pi 5 16GB | ₩513,000 | icbanq | 2GB 대비 약 4.7배 — 용량 올라갈수록 폭등 폭이 커지는 게 국내에서도 확인됨 |

*다음에 가격을 다시 확인하면 이 표에 새 행을 추가할 것 (기존 행은 지우지 말고 이력으로 남길 것).*

## 3. 오렌지파이(Orange Pi)란? 왜 이렇게 싼가

Orange Pi는 중국 Shenzhen Xunlong Software가 만드는 싱글보드컴퓨터(SBC) 라인업으로,
Raspberry Pi의 저가 대항마로 나온 제품군이다. 같은 "SBC"지만 회사 구조와 비즈니스
모델이 근본적으로 다르다:

| | Raspberry Pi | Orange Pi |
|---|---|---|
| 칩 | 재단이 브로드컴과 **전용으로 설계**한 SoC | Rockchip/Allwinner 등이 **이미 대량 양산 중인 기성 칩**을 가져다 씀 |
| 소프트웨어 지원 | 공식 OS(Raspberry Pi OS), 장기 커널 지원을 재단이 직접 투자 | 커뮤니티(Armbian 등) 위주, 공식 지원은 상대적으로 얇음 |
| 브랜드/유통 | 재단 + 공인 리셀러, 품질 보증 체계 확립 | 주로 알리익스프레스 등 오픈마켓, 판매자별 신뢰도 편차 큼 (이번에 직접 겪음: 가짜 할인, 판매 1개짜리 리스팅 등) |
| 가격 결정 요인 (⚠️ 아래 정정 참고) | 원래 저렴하게 유지하는 게 재단 미션이었으나, 이번처럼 특정 부품(LPDDR4) 품귀가 터지면 실구매가가 크게 왜곡됨 | ~~여러 제조사가 경쟁하고, 기성 칩이라 공급량이 많아 특정 부품 품귀에 상대적으로 덜 흔들림~~ (2026-09-08: 틀린 설명, 아래 참고) |

**⚠️ 2026-09-08 정정**: 위 "오렌지파이는 품귀에 덜 흔들린다"는 설명은 **틀렸다.**
웹 검색해보니 Orange Pi 5B 16GB도 2025년 초 $160 → 2026년 2월 $312로 라즈베리파이
못지않게(오히려 더 심하게) 폭등했다. 이건 라즈베리파이만의 문제가 아니라 **AI 붐으로
인한 전 세계 D램 공급난**(TrendForce 전망: 2026년 1분기 메모리 계약가 최대 95%
인상) 때문이며, 오렌지파이 제조사도 같은 D램 물량을 AI 기업들과 경쟁해서 사와야
하는 처지라 똑같이 노출되어 있다. 지금 Orange Pi 4 Pro가 저렴한 진짜 이유는
"오렌지파이라서"가 아니라 **RAM이 4GB로 적어서 D램 원가 비중이 작기 때문** —
고용량(16GB 등) 모델일수록 이번 위기의 타격이 크고, 저용량 모델은 상대적으로
덜 흔들린다. 브랜드와 무관한 현상이다. (사용자가 "가격 최근 추세를 전혀 모르는 것
같다, 검색 못 하냐"고 지적해서 실제 웹 검색 후 이 정정을 반영함.)

출처: [Tom's Hardware](https://www.tomshardware.com/raspberry-pi/raspberry-pi-5-price-increases-drastically-as-ai-shortage-bites-16gb-version-now-usd205-second-price-increase-in-three-mont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),
[Raspberry Pi 공식 블로그](https://www.raspberrypi.com/news/more-memory-driven-price-rises/),
[The Register](https://www.theregister.com/2025/11/19/commodity_memory_price_rise/)

즉 오렌지파이가 싼 건 "싸구려라서"가 아니라, **전용 칩 개발비·공식 지원 비용을
안 쓰고 이미 다른 곳(태블릿, TV박스 등)에서 대량 생산되는 칩을 재사용하기
때문**이다. 대신 그 대가로 공식 문서/장기 지원·커뮤니티 크기에서는 라즈베리파이에
못 미친다 — 이번에 우리가 직접 겪은 것처럼 같은 보드도 리스팅마다 신뢰도가
들쭉날쭉하고, 모델 등급(Zero/4/5/5 Max)이 헷갈리기 쉬운 것도 이런 구조 때문이다.

## 4. "그냥 오렌지파이가 완전 위(TOP)인가?" — 판단

**지금 이 프로젝트 한정으로는 그렇다.** 이유:
- Docker 기반 아키텍처라 보드 종류에 종속되지 않음(핵심 설계 원칙) — 어차피
  Ubuntu/Debian + Docker만 되면 어떤 보드든 옮겨갈 수 있어서, 브랜드 종속 리스크가 적다.
- 지금 Pi5는 **일시적 공급 이슈**로 가격이 왜곡된 상태라 정상 비교가 아니다.
- Orange Pi 4 Pro는 이미 검증(판매량/평점, 상세 스펙 확인)됐고 확장성도 충분하다.

**하지만 "앞으로 무조건 오렌지파이"라고 일반화하진 말 것**:
- Pi5 메모리 품귀가 풀려서 가격이 정상화되면, 라즈베리파이의 압도적인
  문서/커뮤니티/장기지원 이점이 다시 가격 차이를 상쇄할 수 있다.
- 카메라 모듈, 공식 HAT 같은 라즈베리파이 전용 액세서리 생태계가 필요해지면
  오렌지파이는 선택지가 좁아진다.
- 오렌지파이는 모델 등급(Zero/4 Pro/5/5 Plus/5 Max)이 헷갈리기 쉬워서, 매번
  스펙표를 직접 대조하는 수고가 필요하다 (이번 세션에서 실제로 여러 번 헷갈렸음).

**결론**: 지금 시점, 이 프로젝트에는 Orange Pi 4 Pro가 맞는 선택. 다만 "오렌지파이가
항상 우월하다"가 아니라 "지금은 가격 왜곡 때문에 오렌지파이가 유리하다"로
이해하고, Pi5 가격이 정상화되면 다시 비교해볼 가치가 있다.

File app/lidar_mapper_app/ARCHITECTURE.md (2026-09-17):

# Flutter 앱 구조 문서

> 코딩은 Claude가 진행하고, 이 문서는 매 단계마다 갱신됩니다. 코드를 직접
> 안 치셔도 이 문서만 보면 전체 구조/흐름을 파악할 수 있게 유지합니다.
>
> 시각화 버전(Artifact): https://claude.ai/code/artifact/432e945f-9964-4c5c-a6dd-c3f4a149b147

## 전체 흐름 (게이트 → 4탭 메인 셸)

```mermaid
flowchart TD
    START([앱 시작]) --> GATE[연결 화면\nConnectionScreen]
    GATE -- rosbridge 연결 성공 --> SHELL[메인 셸\nBottomNavigationBar]
    SHELL --> HOME[홈(진단)\n라이다/IMU/OP/배터리 상태]
    SHELL --> TRACK[트래킹\n스캔 레이더+지도, 시작/정지]
    SHELL --> LIST[목록\n저장된 세션, 완성도%, 좌표]
    SHELL --> SETTINGS[설정\n연결변경, 필터프리셋, 가이드]
```

## 레이어 구조 (기능마다 반복되는 4단 패턴)

```mermaid
flowchart LR
    V[View\n위젯] --> VM[ViewModel\nRiverpod StateNotifier]
    VM --> R[Repository\n도메인 API]
    R --> S["core/ros_bridge_client\n(rosbridge 통신 창구, 공용)"]
```

- **View**: 화면(위젯), 상태를 표시하고 사용자 입력을 ViewModel에 전달만 함
- **ViewModel**: 상태 보관 + 비즈니스 로직, View는 이걸 통해서만 화면을 그림
- **Repository**: "세션 목록 가져오기" 같은 도메인 용어로 서비스 호출을 감쌈
- **core/ros_bridge_client**: 실제 WebSocket 통신 — 앱 전체에서 이거 하나만 씀

## 파일 트리 (진행 상황 표시: ✅완료 / 🚧진행중 / ⬜예정)

```
lib/
├── main.dart                              ✅ 앱 진입점, ProviderScope+GoRouter 연결
├── core/
│   ├── ros_bridge_client.dart             ✅ rosbridge WebSocket 통신 (connect/send/disconnect)
│   ├── router.dart                        ✅ 게이트→4탭 셸 라우팅 정의(go_router)
│   └── app_shell.dart                     ✅ 하단 탭 4개 네비게이션 셸(NavigationBar)
├── features/
│   ├── connection/                        ✅ 게이트 화면(Tier1-2), 연결 성공 시 /home 이동
│   │   ├── connection_screen.dart
│   │   └── connection_viewmodel.dart
│   ├── diagnostics/                       🚧 홈(진단) 탭 — Tier1-4 (지금은 빈 뼈대)
│   │   └── diagnostics_screen.dart
│   ├── tracking/                          🚧 트래킹 탭 — Tier1-3,6 (지금은 빈 뼈대)
│   │   └── tracking_screen.dart           (다음: 레이더+지도 CustomPainter)
│   ├── sessions/                          🚧 목록 탭 — Tier2-7,8 (지금은 빈 뼈대)
│   │   └── session_list_screen.dart
│   └── settings/                          🚧 설정 탭 — Tier1-2,7 + 가이드 (지금은 빈 뼈대)
│       └── settings_screen.dart
└── demo/                                   (참고용 HTML 데모, 코드 아님)
```

## 변경 로그
- 2026-09-17: 문서 최초 작성, 연결 화면까지 완료 상태 반영
- 2026-09-17: 게이트→4탭 셸 네비게이션 뼈대 완성(`router.dart`, `app_shell.dart`,
  4개 탭 placeholder 화면). `flutter analyze`/`flutter test` 통과 확인.
  다음 단계: 각 탭 placeholder를 실제 기능으로 하나씩 교체(홈/진단부터).
- 2026-09-17: 구조 문서를 Claude Artifact로도 게시(위 링크). 이후 이 문서를
  수정할 때마다 Artifact도 같이 갱신.

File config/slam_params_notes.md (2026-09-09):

# slam_toolbox 파라미터 튜닝 메모 (예정)

기본 설정 파일은 `/opt/ros/humble/share/slam_toolbox/config/mapper_params_online_async.yaml` 사용.
휴대용(사람이 들고 걷는) 환경에서 조정이 필요할 것으로 예상되는 항목:

| 파라미터 | 기본값 | 조정 방향(가설) | 이유 |
|---|---|---|---|
| `minimum_travel_distance` | 0.5 | 낮출 가능성 | 도보 이동 속도가 로봇보다 빠름 |
| `minimum_travel_heading` | 0.5 | 낮출 가능성 | 사람 움직임은 회전이 더 급격함 |
| `scan_buffer_size` | 10 | 실측 후 조정 | 진동 노이즈 영향 확인 필요 |

> 실제 하드웨어로 실내 걷기 테스트를 해봐야 의미 있는 값을 확정할 수 있음.
> 지금은 mock 데이터 기준으로 기본값 그대로 사용하고, 실측 후 이 파일 업데이트.

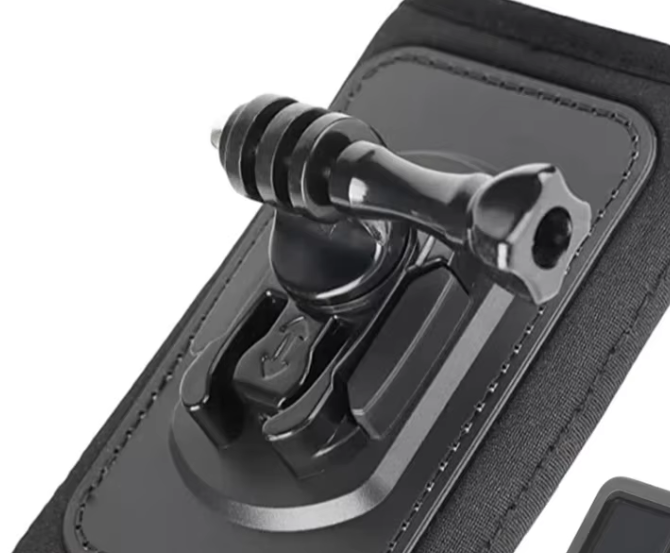
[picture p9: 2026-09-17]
hardware/images/mount-sample3.png

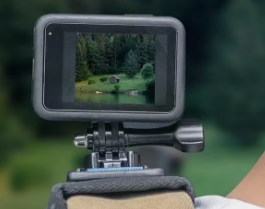
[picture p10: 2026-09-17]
hardware/images/mount-sample2.png

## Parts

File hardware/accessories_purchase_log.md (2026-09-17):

# 부속품/소모품 구매 기록

> 이 문서는 시간이 지나며 구매가 확정될 때마다 아래 표에 새 행을 추가하는
> 방식으로 계속 갱신한다(기존 행 삭제 안 함). 보드 자체 가격 추적은
> `hardware/board_price_tracking.md` 참고, IMU 모듈 선정 근거는
> `/home/kani/.claude/plans/purring-honking-twilight.md` 0번 섹션 참고.

## 구매 확정 목록 (2026-09-15~16)

| 항목 | 모델/스펙 | 가격 | 출처 | 용도/비고 |
|---|---|---|---|---|
| 전기 납땜 인두 세트 | USB Type-C 무선, 디지털 디스플레이 | ₩13,900 | 쿠팡, HZOMFEQBF Store | IMU 핀헤더/GPIO 버튼 배선용 — **세트에 땜납(솔더 와이어) 포함 여부 확인 필요** |
| 브레드보드 | SYB-170, 170포인트 무납땜 | ₩2,820 | 쿠팡, Quality supplier Store | IMU(I2C 4선)+버튼(2선) 프로토타이핑용, 소형이면 충분 |
| Orange Pi 4 Pro 메탈 케이스 | 쿨링팬+방열판+안테나 **전부 포함 확인됨** (Option 3) | ₩14,280 | 쿠팡, Elec-Zone Store | 품절임박이라 선구매. 보드 전용 나사구멍 매칭 확인됨(2026-09-15 검토), 안테나 포함으로 Wi-Fi 감쇠 우려 해소(2026-09-16 확인) |
| 점퍼케이블 세트 | 40/120pcs, M-M/F-F/M-F, 20cm | ₩3,100 | 쿠팡, Quality supplier Store | GPIO/IMU 배선용 |
| microSD 카드 | **SanDisk Ultra 32GB** (정품) | ₩16,940 | 쿠팡 | Orange Pi OS 부팅용. 레노버 초저가 가짜 용량 카드 회피 확인됨(2026-09-15) |
| PETG 필라멘트 | CaiLab PETG 1.75mm 1kg, 퍼플, 뱀부랩 호환 | ₩15,700 | 쿠팡 | 3D 프린팅 인클로저용 — PLA 대비 내열/내UV 개선 (2026-09-15 결정) |
| IMU 모듈 | **CJMCU-055** (Bosch BNO055 칩, 저가 클론) | ₩13,040 | 쿠팡, Advanced Tech | DFRobot SEN0374(₩34,570) 대비 저비용 대안으로 선택 — 칩은 동일, 문서화도 준수한 편이라 EM-SAG-031(정체불명)과는 다른 케이스 |
| 백팩 어깨끈 GoPro 스트랩 마운트 | 360° 호환, Strap With Mount | ₩4,580 | EXSKOF Store | 어깨끈형 브라켓 최종 채택 — female 버클 규격 확인 후 우리 male 탭 치수 맞출 것 |
| 노트북 나사 교체 키트 | 360개, M2/M2.5/M3, 접시머리(플랫헤드) | ₩3,940 | AGE Good Tool Store | 라이다 마운트(M2.5, 카운터싱크) 및 판 조립용 |

**현재까지 합계**: 13,900 + 2,820 + 14,280 + 3,100 + 16,940 + 15,700 + 13,040 + 4,580 + 3,940 = **₩88,300**

## 아직 미구매/확인 필요 항목
- ~~멀티미터~~ — **이미 보유 중 (2026-09-16 확인)**
- ~~Orange Pi 케이스 안테나 포함 여부~~ — **쿨러+방열판+안테나 전부 포함 확인됨 (2026-09-16)**
- 납땜 인두 세트의 **솔더 와이어 포함 여부**
- GPIO 물리 버튼 모듈(0.7번, 페이지3 단계 — 지금 급하지 않음)
- 배낭 어깨끈/캐리핸들 실측(브라켓 설계용, `hardware/cad/mount_plate_and_case_v1.scad`의 추정치 갱신 필요)

## 전체 하드웨어 구매 내역 요약 (프로젝트 시작부터 지금까지)

> 이 프로젝트 전체에 걸친 실제 지출 총정리. 각 항목의 출처 문서를 함께 표시.

| 항목 | 가격 | 날짜 | 기록 출처 |
|---|---|---|---|
| RPLIDAR C1 (라이다 센서) | ₩100,800 (배송지연 보상 쿠폰 ₩1,300 별도 적용) | 2026-09-16 확인 (실제 구매 시점은 그 이전) | Fidu Robot Store — 2026-09-16 사용자 제공 주문내역으로 확정 |
| Orange Pi 4 Pro 4GB (보드 본체) | ₩74,800 | 2026-09-11 구매 | `hardware/board_price_tracking.md`, `devlog/2026-09-11_orange_pi_purchased.md` |
| Orange Pi 4 Pro 메탈 케이스(쿨러+방열판+안테나 포함) | ₩14,280 | 2026-09-16 | 위 표 |
| 전기 납땜 인두 세트 | ₩13,900 | 2026-09-16 | 위 표 |
| 브레드보드(SYB-170) | ₩2,820 | 2026-09-16 | 위 표 |
| 점퍼케이블 세트 | ₩3,100 | 2026-09-16 | 위 표 |
| microSD 카드(SanDisk 32GB) | ₩16,940 | 2026-09-16 | 위 표 |
| PETG 필라멘트(퍼플) | ₩15,700 | 2026-09-16 | 위 표 |
| IMU 모듈(CJMCU-055) | ₩13,040 | 2026-09-16 | 위 표 |
| 백팩 GoPro 스트랩 마운트 | ₩4,580 | 2026-09-16 | 위 표 |
| 나사 교체 키트(M2/M2.5/M3) | ₩3,940 | 2026-09-16 | 위 표 |
| **총 합계 (라이다 포함)** | **₩263,900** | | |

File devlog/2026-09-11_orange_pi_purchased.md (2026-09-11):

# 2026-09-11 개발 로그 — Orange Pi 4 Pro 구매 완료

## 오늘의 목표
- Orange Pi 4 Pro 구매 완료 반영
- 텀블러 후보 실측 대기 (사용자가 곧 후보 사진 공유 예정)

## 진행 내용
- **Orange Pi 4 Pro 4GB 구매 완료**, 배송 중. 가격은 사전 조사 때 확인한 대로
  약 74,800원대(`hardware/board_price_tracking.md` 2026-09-08 기록과 일치).
- 관련 문서 상태 갱신: `README.md`, `README_ARCHITECTURE.md`(0번 표, 5.4 로드맵),
  `hardware/tumbler_mount_design.md`(0번 장착 현황)에서 "미구매" → "구매
  완료(배송 중)"로 반영.
- 텀블러 후보는 사용자가 사진을 곧 공유할 예정 — 도착하면 1.7번(부품 치수 기반
  적합성 검토) 결론과 대조해서 실제로 맞는지 확인할 것.

## 다음 단계
- Orange Pi 4 Pro 도착 시: `hardware/orange_pi_4_pro_bringup_risks.md` 절차대로
  이식 시작 (Phase 2 진입)
- 텀블러 후보 사진 수신 시: 실측 치수를 1.7번 스케일 검토와 대조

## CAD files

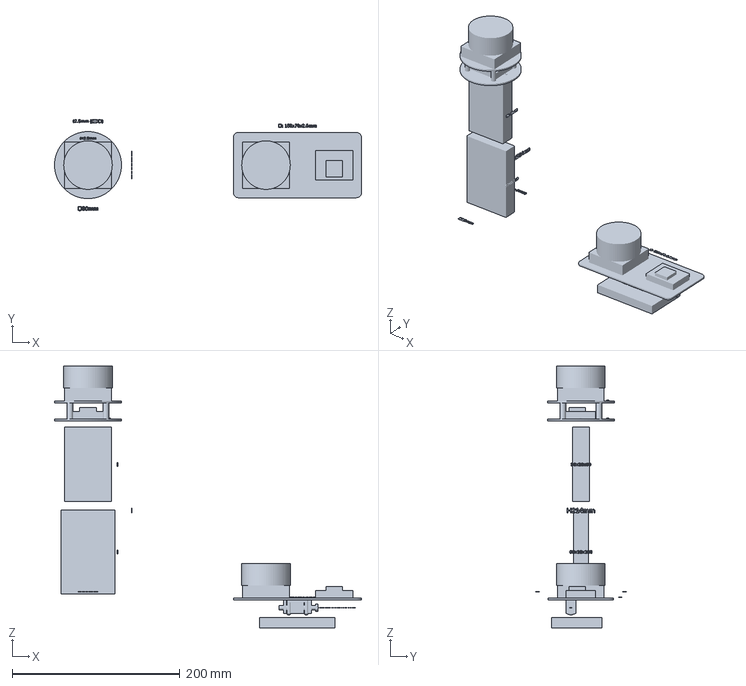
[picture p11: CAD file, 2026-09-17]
hardware/cad/tumbler_shell_v2.3mf
366.5 x 109.0 x 312.3 mm

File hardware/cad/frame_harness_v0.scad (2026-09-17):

// ============================================================
// ⚠️ 이 파일은 폐기됨 (2026-09-15) — 가방을 감싸는 프레임 구조는
// 방향이 잘못됨(특정 가방 형태를 전제로 함). 대체 파일:
// mount_plate_and_case_v1.scad (상단 평판 + 별도 케이스 분리형)
// ============================================================
// Portable LiDAR Mapper — 프레임 하네스(스쿠버탱크형) v0.1 [DEPRECATED]
// 사용법: OpenSCAD(무료, openscad.org)에서 이 파일을 열고
//   F5 = 미리보기, F6 = 렌더링, File > Export > Export as STL
//   로 STL을 뽑아서 슬라이서(Bambu Studio 등)에 넣으면 됩니다.
// 아래 변수만 실측값으로 바꾸면 전체 형상이 자동으로 재계산됩니다.
// ============================================================

// ---------- 실측 확정값 ----------
lidar_diameter   = 75;   // RPLIDAR C1 지름 (hardware/tumbler_mount_design.md 실측값)
lidar_height     = 40;   // 추정치 — 실물 도착 후 캘리퍼스로 재측정 후 수정할 것

// ---------- 추정치 (반드시 실측 후 갱신) ----------
body_diameter    = 80;   // 본체(오렌지파이+배터리) 원통 지름
body_height      = 220;  // 본체 높이
rail_width       = 14;   // 프레임 레일 폭
rail_thickness   = 5;    // 프레임 레일 두께
rail_gap         = 5;    // 본체-레일 사이 간격(스트랩 통과 공간)
strap_width      = 12;   // 스트랩 루프 폭
strap_thickness  = 4;    // 스트랩 루프 두께
plate_size       = 90;   // 상단 마운트 플레이트 한 변
plate_thickness  = 4;    // 상단 마운트 플레이트 두께
mount_hole_dia   = 3.2;  // M3 나사용 구멍 지름
mount_hole_spacing = 40; // 마운트 나사 구멍 간격

// 레일이 본체를 감싸는 반경(간격 포함)
rail_radius = body_diameter/2 + rail_gap + rail_width/2;

$fn = 64; // 원형 부드럽게

// ---------- 본체(참고용, 실제 인쇄 대상 아님 — 피팅 확인용) ----------
module body_reference() {
    color("lightgray", 0.25)
    translate([0, 0, body_height/2])
        cylinder(h=body_height, d=body_diameter, center=true);
}

// ---------- 프레임 레일 (좌/우 세로 기둥, 곡선은 단순화된 초안) ----------
module frame_rail(x_offset) {
    color("dimgray")
    translate([x_offset, 0, 0])
    hull() {
        translate([0, 0, rail_width/2])
            rotate([90,0,0]) cylinder(h=1, d=rail_width, center=true);
        translate([0, 0, body_height - rail_width/2])
            rotate([90,0,0]) cylinder(h=1, d=rail_width, center=true);
    }
}

module frame_rails() {
    frame_rail(rail_radius);
    frame_rail(-rail_radius);
}

// ---------- 상단 육각 손잡이 루프 (경량화 + 손잡이 겸용) ----------
module top_handle_loop() {
    color("dimgray")
    translate([0, 0, body_height + 30])
    rotate([90, 0, 0])
    difference() {
        hull() {
            for (a = [0:60:300])
                rotate([0,0,a]) translate([body_diameter/2, 0, 0]) cylinder(h=rail_thickness, d=rail_width, center=true);
        }
        hull() {
            for (a = [0:60:300])
                rotate([0,0,a]) translate([body_diameter/2 - rail_width - 6, 0, 0]) cylinder(h=rail_thickness+2, d=rail_width, center=true);
        }
    }
}

// ---------- 스트랩 루프 (본체를 프레임에 고정) ----------
module strap_loop(z_pos) {
    color("black")
    translate([0, 0, z_pos])
    rotate_extrude(angle=200, $fn=64)
        translate([rail_radius - rail_width/2, 0, 0])
            square([strap_width, strap_thickness], center=true);
}

module strap_loops() {
    strap_loop(body_height * 0.25);
    strap_loop(body_height * 0.75);
}

// ---------- 상단 마운트 플레이트 (라이다 장착부) ----------
module mount_plate() {
    color("purple")
    translate([0, 0, body_height + 5])
    difference() {
        // 플레이트 본체
        translate([-plate_size/2, -plate_size/2, 0])
            cube([plate_size, plate_size, plate_thickness]);
        // 마운트 나사 구멍 4개
        for (x = [-1, 1], y = [-1, 1])
            translate([x*mount_hole_spacing/2, y*mount_hole_spacing/2, -1])
                cylinder(h=plate_thickness+2, d=mount_hole_dia);
    }
    // 라이다 풋프린트(참고용 반투명 실린더, 실제 인쇄 대상 아님)
    color("orange", 0.3)
    translate([0, 0, body_height + 5 + plate_thickness])
        cylinder(h=lidar_height, d=lidar_diameter);
}

// ---------- 조립 전체 ----------
module assembly() {
    body_reference();
    frame_rails();
    top_handle_loop();
    strap_loops();
    mount_plate();
}

assembly();

// ============================================================
// 인쇄용으로 개별 부품만 뽑고 싶으면 위 assembly() 호출을 주석 처리하고
// 아래 중 필요한 모듈만 개별 호출하세요. body_reference()는 실제 부품이
// 아니라 피팅 확인용 참고 형상이라 인쇄 대상에서 제외할 것.
//
// frame_rails();
// top_handle_loop();
// strap_loops();
// mount_plate();
// ============================================================

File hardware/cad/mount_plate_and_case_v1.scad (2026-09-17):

// ============================================================
// Portable LiDAR Mapper — 상단 평판 + 오렌지파이/배터리 케이스 v1
// 가방을 뚫거나 개조하지 않음. 백팩 한정, 특정 가방 형태에 안 묶임.
//
// 구성:
//   1) mount_plate()  — 가방 상단 바깥면에 벨크로로 고정, 라이다+IMU 탑재
//   2) device_case()  — 오렌지파이+배터리, 가방 상단부 근처 주머니에 넣음
//      (별도 부품, 케이블로 mount_plate와 연결)
//
// 사용법: OpenSCAD(openscad.org)에서 열기 → F5 미리보기 → F6 렌더링 →
//   File > Export > Export as STL. 아래 변수만 실측값으로 바꾸면 됨.
//   두 부품은 따로 인쇄해야 하므로, 맨 아래 호출부에서 필요한 것만 주석 해제.
// ============================================================

$fn = 64;

// ================= 상단 평판 (mount_plate) =================

// ---------- 실측 확정값 (SLAMTEC 공식 datasheet, 2026-09-16 확인) ----------
lidar_diameter     = 75;   // RPLIDAR C1 지름
lidar_hole_spacing = 43;   // 라이다 마운트 나사 간격 43x43mm 정사각형 배치 (공식 datasheet)
lidar_screw_spec   = "M2.5"; // 나사 규격 — M3 아님, 주의
lidar_max_screw_depth = 4;   // ⚠️ 라이다 바닥으로 나사가 4mm 넘게 들어가면 내부 파손(공식 경고)
lidar_hole_dia     = 2.9;    // M2.5 나사용 여유구멍(클리어런스 홀)

// ---------- 추정치 (실측 필요) ----------
imu_length         = 25; // IMU 모듈 크기 — 아직 미구매, 임시값
imu_width          = 20;
imu_hole_spacing_x = 18;
imu_hole_spacing_y = 13;

mount_hole_dia    = lidar_hole_dia; // 하위 호환용 별칭 — 실제로는 M2.5 클리어런스
imu_hole_dia      = 2.2; // M2

// 2026-09-15 수정: IMU를 라이다와 나란히 두지 않고 라이다 풋프린트
// 중심(회전축) 바로 아래에 겹쳐서 배치 — EKF 센서퓨전 시 IMU-라이다 간
// 거리(모멘트암)가 짧을수록 오차가 줄어듦. 단, 라이다 실물 밑면에 이
// 크기의 IMU가 실제로 들어갈 공간이 있는지는 미확인 — 실물 도착 후
// 안 맞으면 imu_offset_x를 0이 아닌 값으로 바꿔서 옆으로 빼면 됨.
imu_offset_x      = 0;   // 0 = 라이다 중심과 동축, 안 맞으면 옆으로 이동

plate_length      = max(lidar_diameter, imu_length) + 40; // 평판 전체 길이
plate_width       = max(lidar_diameter, imu_width) + 30;  // 평판 전체 폭
plate_thickness   = 4;

velcro_strap_width = 20; // 사용할 벨크로 스트랩 폭 — 실측 필요
velcro_slot_w     = velcro_strap_width + 2;
velcro_slot_h     = 6;
velcro_slot_inset = 12;  // 평판 가장자리에서 슬롯까지 거리

module mount_plate() {
    color("purple")
    difference() {
        // 평판 본체 (모서리 둥글게)
        linear_extrude(height=plate_thickness)
            offset(r=6) offset(delta=-6)
                square([plate_length, plate_width], center=true);

        // 벨크로 스트랩 관통 슬롯 4개 (앞쪽 2개, 뒤쪽 2개 — 가방을 뚫지 않고
        // 스트랩을 평판 아래로 통과시켜 가방 상단을 감싸 고정하는 방식)
        for (x = [-1, 1])
            translate([x*(plate_length/2 - velcro_slot_inset), plate_width/2 - velcro_slot_h*1.5, -1])
                cube([velcro_slot_w, velcro_slot_h, plate_thickness+2], center=true);
        for (x = [-1, 1])
            translate([x*(plate_length/2 - velcro_slot_inset), -(plate_width/2 - velcro_slot_h*1.5), -1])
                cube([velcro_slot_w, velcro_slot_h, plate_thickness+2], center=true);

        // 라이다 마운트 나사구멍 4개 (평판 중심)
        for (x = [-1, 1], y = [-1, 1])
            translate([x*lidar_hole_spacing/2, y*lidar_hole_spacing/2, -1])
                cylinder(h=plate_thickness+2, d=mount_hole_dia);

        // IMU 마운트 나사구멍 4개 — 라이다와 동축(중심 겹침, imu_offset_x=0일 때)
        translate([imu_offset_x, 0, 0])
            for (x = [-1, 1], y = [-1, 1])
                translate([x*imu_hole_spacing_x/2, y*imu_hole_spacing_y/2, -1])
                    cylinder(h=plate_thickness+2, d=imu_hole_dia);

        // 케이블 인출 구멍 (평판 가장자리, 케이스로 내려가는 케이블용)
        translate([plate_length/2 - 8, 0, -1])
            cylinder(h=plate_thickness+2, d=8);
    }

    // 참고용 표시(인쇄 대상 아님): 라이다/IMU 풋프린트 — 겹쳐서 동축 배치 확인용
    color("orange", 0.25)
    translate([0, 0, plate_thickness])
        cylinder(h=1, d=lidar_diameter);
    color("cyan", 0.4)
    translate([imu_offset_x - imu_length/2, -imu_width/2, plate_thickness])
        cube([imu_length, imu_width, 1]);
}

// ================= 오렌지파이+배터리 케이스 (device_case) =================

// ---------- 실측 확정값 ----------
board_length = 89;  // Orange Pi 4 Pro (실측, hardware 문서 기준)
board_width  = 56;

// ---------- 추정치 (배터리 실물 치수 필요) ----------
board_thickness   = 20; // 보드+커넥터 돌출부 포함 추정
battery_length    = 95; // 보조배터리 추정치 — 반드시 실측 후 수정
battery_width     = 55;
battery_thickness = 25;

wall = 2.5;       // 케이스 벽 두께
clearance = 3;    // 부품-내벽 사이 여유 공간
lid_lip = 1.5;     // 뚜껑 결합부 높이

case_int_l = max(board_length, battery_length) + clearance*2;
case_int_w = max(board_width, battery_width) + clearance*2;
case_int_h = board_thickness + battery_thickness + clearance*3; // 보드 위에 배터리 스택

module device_case_body() {
    color("lightgray")
    difference() {
        // 외곽
        cube([case_int_l + wall*2, case_int_w + wall*2, case_int_h + wall], center=false);
        // 내부 공동
        translate([wall, wall, wall])
            cube([case_int_l, case_int_w, case_int_h + 1]);
        // 케이블 인출 구멍 (윗면, mount_plate로 올라가는 케이블용)
        translate([wall + case_int_l/2, wall + case_int_w/2, case_int_h + wall - 5])
            cylinder(h=10, d=8);
    }
}

module device_case_lid() {
    color("darkgray")
    translate([0, case_int_w + wall*2 + 10, 0])
    difference() {
        cube([case_int_l + wall*2, case_int_w + wall*2, wall*2], center=false);
        translate([wall + lid_lip, wall + lid_lip, -1])
            cube([case_int_l - lid_lip*2, case_int_w - lid_lip*2, wall+1]);
    }
}

// ================= 더미 가방 (참고용, 인쇄 대상 아님) =================
// 사용자 제공 사진(플랩탑 백팩, 상단 손잡이+양쪽 버클스트랩) 기준 대략적
// 형상. 실측 아님 — 사진 비례로 눈대중 추정. 실제 가방 스케치 받으면 갱신.

bag_width  = 300; // 가방 전체 폭
bag_depth  = 140; // 가방 두께
bag_height = 400; // 가방 높이(플랩 포함)
flap_height = 90; // 상단 플랩 높이
handle_gap = 30;  // 손잡이 폭

module dummy_backpack() {
    color("SaddleBrown", 0.35) {
        // 본체
        translate([-bag_width/2, -bag_depth/2, 0])
            cube([bag_width, bag_depth, bag_height - flap_height]);
        // 상단 플랩(앞쪽으로 살짝 기울어진 덮개)
        translate([-bag_width/2, -bag_depth/2, bag_height - flap_height])
            cube([bag_width, bag_depth, flap_height]);
        // 상단 손잡이(관통형 브라켓/벨크로가 걸리는 대상)
        translate([-handle_gap/2, 0, bag_height])
            rotate([90,0,0])
                cylinder(h=handle_gap, d=14);
    }
}

// ================= 집게형(스프링클립) 브라켓 =================
// 벨크로 대신/같이 쓸 수 있는 방식. 플랩 상단처럼 "판 모양 모서리"를
// 위아래로 물어서 고정 — PETG 자체 탄성으로 벌어졌다 오므라들어
// 별도 스프링 부품 없이 클립처럼 작동(3D 프린팅 스프링 클립의 표준 기법).

clamp_edge_thickness = 12; // 물릴 모서리(플랩 상단) 두께 — 실측 필요
clamp_jaw_depth      = 35; // 클립이 모서리를 물고 들어가는 깊이
clamp_width          = 60; // 클립 폭(평판 부착면 폭)
clamp_wall           = 3;  // 클립 벽 두께(탄성 확보 위해 얇게)
clamp_gap_margin     = -1.5; // 음수: 살짝 좁게 만들어서 끼울 때 압착되며 고정(억지끼움)

module flex_clamp_bracket() {
    color("purple")
    difference() {
        union() {
            // 위쪽 조(jaw)
            translate([-clamp_width/2, 0, clamp_edge_thickness + clamp_gap_margin])
                cube([clamp_width, clamp_jaw_depth, clamp_wall]);
            // 아래쪽 조(jaw)
            translate([-clamp_width/2, 0, -clamp_wall])
                cube([clamp_width, clamp_jaw_depth, clamp_wall]);
            // 안쪽(플랩 쪽) 연결부 — 여기 얇은 부분이 탄성 힌지 역할
            translate([-clamp_width/2, 0, -clamp_wall])
                cube([clamp_width, clamp_wall, clamp_edge_thickness + clamp_wall*2 + clamp_gap_margin]);
            // 바깥쪽 상단 마운트면(mount_plate를 이 위에 나사로 고정)
            translate([-clamp_width/2, clamp_jaw_depth - 4, clamp_edge_thickness + clamp_gap_margin])
                cube([clamp_width, 20, clamp_wall + 3]);
        }
        // 마운트 나사구멍 2개(위쪽 마운트면에)
        for (x = [-1, 1])
            translate([x*clamp_width/3, clamp_jaw_depth + 8, -1])
                cylinder(h=clamp_edge_thickness + 20, d=mount_hole_dia);
    }
}

// ================= 어깨끈형 브라켓 (GoPro 표준 마운트 규격 기반) =================
// 근거(웹 검색, 2026-09-15): GoPro 3프롱(남) 마운트 표준 —
//   탭 폭 ~25.4mm, 높이 ~18mm, 나사구멍 지름 ~5.5mm(GoPro 전용 썸스크류용),
//   양옆 프롱 두께 ~4.5mm, 가운데 슬롯(암 버클 삽입부) ~7mm.
// Sources: storytellertech.com/gopro-screw-size, printables.com GoPro mount 모델들
//
// ⚠️ 실전 팁: 이 프롱 형상은 정밀 끼워맞춤이 필요해서 직접 프린트하면
// 헐거움/뻑뻑함 조정에 시행착오가 필요합니다. **더 확실한 방법은 시중
// GoPro 호환 마운트 어댑터(개당 1천~2천원, 쿠팡/알리 등)를 사서 아래
// gopro_flat_boss() 평면에 나사/글루로 고정하는 것** — 그게 훨씬 안정적.
// 그래도 직접 프린트하고 싶으면 gopro_male_tab() 사용.

gopro_tab_width     = 25.4;
gopro_tab_height    = 18;
gopro_prong_thick   = 4.5;
gopro_slot_width    = 7;
gopro_hole_dia      = 5.5;

module gopro_male_tab() {
    color("purple")
    difference() {
        union() {
            // 좌우 프롱 2개
            translate([-gopro_tab_width/2, 0, 0])
                cube([gopro_prong_thick, 12, gopro_tab_height]);
            translate([gopro_tab_width/2 - gopro_prong_thick, 0, 0])
                cube([gopro_prong_thick, 12, gopro_tab_height]);
            // 베이스(끈 클램프에 붙는 바닥판)
            translate([-gopro_tab_width/2, 0, 0])
                cube([gopro_tab_width, 12, 3]);
        }
        // 썸스크류 관통구멍 (중앙, 높이 중간)
        translate([0, 6, gopro_tab_height/2])
            rotate([90,0,0])
                cylinder(h=14, d=gopro_hole_dia, center=true);
    }
}

// 대안: GoPro 어댑터를 사서 붙일 평평한 면 (프롱 프린트 리스크 회피용)
module gopro_flat_boss() {
    color("purple")
    difference() {
        cylinder(h=4, d=30);
        translate([0,0,-1]) cylinder(h=6, d=mount_hole_dia); // 어댑터 고정 나사구멍
    }
}
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

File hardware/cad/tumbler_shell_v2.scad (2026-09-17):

// ============================================================
// Portable LiDAR Mapper — 텀블러형 쉘 v2 + 어깨끈 마운트 비교 (2026-09-16)
// 색상 규칙: 검정 = 실제 기기(라이다/IMU/브레드보드), 보라 = 3D프린팅부(PETG),
//           초록 = Orange Pi/배터리
// 변경점(v1 대비):
//   - 라이다 마운트 구멍을 카운터싱크(접시머리 나사 대응)로 변경
//   - RPLIDAR C1 실측 형상(사각 베이스+원형 상부) 추가, 검정
//   - 미니브레드보드(45x35x9, SYB-170 실측)+IMU(20x20, CJMCU-055 실측) 스택 추가
//   - 상단을 "평탄화 판 2장 사이에 기기 샌드위치" 구조로 변경
//   - 배터리를 표준 파워뱅크(3000~10000mAh) 크기로 파라미터화, 초록색
//   - 어깨끈형(GoPro 스트랩 마운트) 버전을 옆에 나란히 배치
// ============================================================

$fn = 64;

// ================= 치수 라벨 헬퍼 (설계도처럼 표시용, 인쇄 대상 아님) =================
module dim_label(txt, size=4) {
    color("red")
    linear_extrude(height = 0.5)
        text(txt, size = size, halign = "center", valign = "center", font = "Liberation Sans:style=Bold");
}

// ---------- 실측 확정값 / 정정 (2026-09-16) ----------
// ⚠️ 기존 75mm는 공식 datasheet 근거가 아니었음(도면엔 사각 베이스+높이만
// 명시, 원형부 지름은 숫자로 없음) — 사각 베이스(55.6mm)와 비례가 맞는
// 58mm로 임시 수정. 실물 도착 후 캘리퍼스로 재측정 필수.
lidar_diameter     = 58;
lidar_base_square  = 55.6;   // RPLIDAR C1 사각 베이스 한 변 (공식 datasheet)
lidar_total_height = 41.3;   // 공식 datasheet 총 높이
lidar_base_height  = 15;     // 사각 베이스부 높이(도면 비례 추정, 실측 재확인 권장)
lidar_hole_spacing = 43;
lidar_hole_dia     = 2.9;    // M2.5 클리어런스
lidar_countersink_dia = 5.5; // 접시머리 나사 헤드 지름(M2.5 플랫헤드 일반 규격 추정)
lidar_max_screw_depth = 4;

imu_size           = 20;     // CJMCU-055 실측 20x20mm
imu_pcb_thickness  = 1.6;
imu_component_h    = 3;      // 칩/부품 높이 여유

breadboard_length  = 45;     // SYB-170 실측
breadboard_width   = 35;
breadboard_height  = 9;

pin_header_gap     = 8;      // IMU가 브레드보드에 핀헤더로 꽂힐 때 뜨는 높이

board_length = 89;   // Orange Pi 4 Pro
board_width  = 56;
board_thickness = 20;

// ---------- 배터리: 표준 파워뱅크 범위(3000~10000mAh) 대표값 ----------
// 3000mAh 슬림형 ~ 10000mAh 일반형까지 폭이 넓어, 중간~10000mAh 기준 실사용
// 제품에 흔한 크기로 대표값 설정(추정 — 실물 구매 후 갱신)
battery_length     = 100;
battery_width      = 65;
battery_thickness  = 18;

wall = 2.5;

// ================= 카운터싱크 나사구멍 모듈 (재사용) =================
module countersunk_hole(depth) {
    cylinder(h = depth+2, d = lidar_hole_dia);
    translate([0, 0, depth - 1.5])
        cylinder(h = 2, d1 = lidar_hole_dia, d2 = lidar_countersink_dia);
}

// ================= RPLIDAR C1 실제 형상 (검정, 참고용 — 인쇄 대상 아님) =================
module rplidar_c1() {
    color("black") {
        // 사각 베이스
        translate([-lidar_base_square/2, -lidar_base_square/2, 0])
            cube([lidar_base_square, lidar_base_square, lidar_base_height]);
        // 원형 상부(광학부)
        translate([0, 0, lidar_base_height])
            cylinder(h = lidar_total_height - lidar_base_height, d = lidar_diameter);
    }
}

// ================= 브레드보드 + IMU 스택 (검정) =================
module breadboard_imu_stack() {
    color("black") {
        // 미니 브레드보드
        translate([-breadboard_length/2, -breadboard_width/2, 0])
            cube([breadboard_length, breadboard_width, breadboard_height]);
        // IMU — 브레드보드 위에 바로 밀착(2026-09-16: 붙어있게 수정, 핀헤더 뜬 간격 제거)
        translate([-imu_size/2, -breadboard_width/2 + 3, breadboard_height])
            cube([imu_size, imu_size, imu_pcb_thickness + imu_component_h]);
    }
}

// ================= 평탄화 판 2장 (보라, PETG) — 기기를 사이에 샌드위치 =================
plate_gap = lidar_base_height + 4; // 두 판 사이 간격(라이다 베이스+여유)

module flatten_plate(d) {
    color("purple")
    difference() {
        cylinder(h = wall, d = d);
        for (x = [-1, 1], y = [-1, 1])
            translate([x*lidar_hole_spacing/2, y*lidar_hole_spacing/2, -1])
                countersunk_hole(wall);
    }
    // 치수 라벨: 판 두께, 나사구멍 간격
    translate([0, d/2 - 8, wall + 0.5]) dim_label(str("t=", wall, "mm"), 3.5);
    translate([lidar_hole_spacing/2, 0, wall + 0.5]) dim_label(str(lidar_hole_spacing, "x", lidar_hole_spacing), 3);
}

module top_assembly(shell_d) {
    // 하단 평탄화 판(브레드보드+IMU가 이 위에 얹힘)
    flatten_plate(shell_d);
    translate([0, 0, wall]) breadboard_imu_stack();

    // 스탠드오프 4개 (보라)
    color("purple")
    for (x = [-1, 1], y = [-1, 1])
        translate([x*lidar_hole_spacing/2, y*lidar_hole_spacing/2, wall])
            cylinder(h = plate_gap, d = lidar_hole_dia + 4);

    // 상단 평탄화 판(라이다가 이 위에 얹힘)
    translate([0, 0, wall + plate_gap]) {
        flatten_plate(shell_d);
        translate([0, 0, wall]) rplidar_c1();
    }
}

// ================= 옵션 1: 텀블러 쉘 =================
shell_diameter = 80;
// 배터리(100)+간격(10)+Orange Pi(89)+여유(15) 세로 스택 기준 재계산
shell_body_height = battery_length + 10 + board_length + 15;

module tumbler_variant() {
    // 쉘 본체 — 2026-09-16 재수정: color() 알파값이 뷰어에 따라 무시되는
    // 문제가 있어, OpenSCAD 표준 "배경(참고용) 투명" 표기인 % modifier로 변경.
    // 이러면 뷰어/렌더 방식과 무관하게 항상 회색 반투명으로 표시됨.
    %difference() {
        cylinder(h = shell_body_height, d = shell_diameter);
        translate([0, 0, wall])
            cylinder(h = shell_body_height, d = shell_diameter - wall*2);
    }
    // 치수 라벨: 쉘 지름/높이/벽두께
    translate([shell_diameter/2 + 12, 0, shell_body_height/2])
        rotate([90,0,90]) dim_label(str("H", shell_body_height, "mm"), 6);
    translate([0, shell_diameter/2 + 12, 10])
        dim_label(str("t", wall, "mm (벽두께)"), 4);
    translate([0, -(shell_diameter/2 + 12), 10])
        dim_label(str("⌀", shell_diameter, "mm"), 5);

    // 배터리 (초록, 최하단, 완전 불투명 — 쉘 투명화로 내부 부품이 잘 보이게)
    // 2026-09-16 버그 수정: 눕혀서 배치하면 대각선 116mm로 쉘 내경(~75mm)을
    // 뚫고 나옴 → Orange Pi처럼 세로로 세워서 배치(65x18 대각선 ~67mm로 내경
    // 안에 들어감). 단, 세로로 세우면 배터리 길이(100mm)만큼 전체 높이가
    // 늘어남 — 큰 배터리(10000mAh)를 쓰려면 쉘 지름을 키워야 함.
    color("green", 0.6)
    translate([-battery_width/2, -battery_thickness/2, wall + 5])
        cube([battery_width, battery_thickness, battery_length]);
    translate([shell_diameter/2 - 5, 0, wall + 5 + battery_length/2])
        rotate([90,0,90]) dim_label(str(battery_width,"x",battery_thickness,"x",battery_length), 4);

    // Orange Pi (초록, 배터리 위 세로 배치 — 색상/투명도 원복, 쉘만 투명화)
    color("green", 0.6)
    translate([-board_width/2, -board_thickness/2, wall + 5 + battery_length + 10])
        cube([board_width, board_thickness, board_length]);
    translate([shell_diameter/2 - 5, 0, wall + 5 + battery_length + 10 + board_length/2])
        rotate([90,0,90]) dim_label(str(board_width,"x",board_thickness,"x",board_length), 4);

    // 상단 평탄화 판 2장 + 라이다/IMU/브레드보드
    translate([0, 0, shell_body_height]) top_assembly(shell_diameter);
}

// ================= 옵션 2: 어깨끈형(GoPro 스트랩 마운트) =================
gopro_tab_width   = 25.4;
gopro_tab_height  = 18;
gopro_prong_thick = 4.5;
gopro_hole_dia    = 5.5;

// 2026-09-16 재수정: (1) 구멍이 프롱 사이 빈 공간을 뚫던 버그 → 두 프롱을
// 실제로 가로지르는 X방향으로 수정. (2) 프롱 위쪽에 사진처럼 둥근 돔 형태
// 추가. (3) female(암컷) 쪽도 "홈 2곳"으로 다시 모델링 — 이전에 넣었던
// 볼조인트/엉뚱한 위치의 나사는 전부 제거하고, 우리 프롱이 정확히 끼워지는
// 슬롯 2개 + 그 자리를 그대로 관통하는 나사 1개로 재구성.
module gopro_prong_rounded(w, d, h) {
    // 몸통(각기둥) + 위쪽 돔(구형 캡)을 hull로 이어붙여 둥근 형태로
    hull() {
        linear_extrude(height = h - w/2)
            translate([0, d/2])
                offset(r = w/3) offset(delta = -w/3)
                    square([w, d], center = true);
        translate([0, d/2, h - w/2])
            sphere(d = w, $fn = 24);
    }
}

module gopro_male_tab() {
    color("purple")
    difference() {
        union() {
            translate([-gopro_tab_width/2 + gopro_prong_thick/2, 0, 0])
                gopro_prong_rounded(gopro_prong_thick, 12, gopro_tab_height);
            translate([gopro_tab_width/2 - gopro_prong_thick/2, 0, 0])
                gopro_prong_rounded(gopro_prong_thick, 12, gopro_tab_height);
            // 베이스(발판) — 둥근 모서리
            translate([0, 6, 1.5])
                linear_extrude(height = 3, center = true)
                    offset(r=3) offset(delta=-3)
                        square([gopro_tab_width, 12], center = true);
        }
        // 관통 구멍 — 양쪽 프롱을 실제로 가로지름 (X축 방향), 나사 위치는
        // 여기 한 곳뿐 — female 슬롯에 끼운 뒤 이 구멍을 그대로 관통시킴
        translate([0, 6, gopro_tab_height/2])
            rotate([0, 90, 0])
                cylinder(h = gopro_tab_width + 4, d = gopro_hole_dia, center = true);
    }
}

// female(암컷) 리시버 — 우리 프롱 2개가 정확히 들어갈 홈 2곳을 판 것.
// 프롱과 같은 로컬 좌표계(y:0~12, z:0~tab_height)에 그대로 겹쳐서
// "완전히 끼워진 상태"를 표현 — 상용 구매품이라 인쇄 대상 아님, 참고용.
module female_receiver() {
    color("gray", 0.55)
    difference() {
        translate([-(gopro_tab_width/2 + 4), 0, -2])
            cube([gopro_tab_width + 8, 12, gopro_tab_height]);
        // 홈(슬롯) 2곳 — 우리 프롱이 끼워지는 자리, 여유 0.4mm
        translate([-gopro_tab_width/2 + gopro_prong_thick/2, 0, -3])
            gopro_prong_rounded(gopro_prong_thick + 0.4, 13, gopro_tab_height + 4);
        translate([gopro_tab_width/2 - gopro_prong_thick/2, 0, -3])
            gopro_prong_rounded(gopro_prong_thick + 0.4, 13, gopro_tab_height + 4);
        // 관통 구멍 — 남자 탭 구멍과 정확히 같은 축(x방향, y=6, z=tab_height/2)
        translate([0, 6, gopro_tab_height/2])
            rotate([0, 90, 0])
                cylinder(h = gopro_tab_width + 20, d = gopro_hole_dia + 0.3, center = true);
    }
}
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

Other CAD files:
hardware/cad/tumbler_shell_v1.scad

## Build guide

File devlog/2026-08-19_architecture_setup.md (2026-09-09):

# 2026-08-19 개발 로그 — 아키텍처 구조화

## 오늘의 목표
- 프로젝트 전체 아키텍처를 5개 레이어로 구조화
- 장비(Pi5) 도착 전에도 진행 가능한 개발 순서 확정
- ROS2 워크스페이스 스켈레톤 생성

## 진행 내용
- 레이어드 아키텍처 확정: 하드웨어 → 드라이버 → ROS2 미들웨어 → 저장 → 시각화
- 텀블러 마운트 하드웨어 설계도 초안 작성 (`hardware/tumbler_mount_design.md`)
- ROS2 워크스페이스 구조 확정: `lidar_mapper_bringup`(실행), `lidar_mapper_mock`(하드웨어 없이 개발용)
- 환경 세팅 스크립트(`scripts/setup_env.sh`) 초안 작성

## 막힌 문제 & 해결
| 증상 | 원인 | 해결 방법 |
|---|---|---|
| Pi5 아직 없음 | 가격 급등으로 구매 보류 중 | mock 노드로 3~5계층 먼저 PC에서 개발 |

## 다음 단계
- `setup_env.sh` 실제 PC에서 실행해서 ROS2 Humble 설치 검증
- `lidar_mapper_mock` 노드로 `/scan` 퍼블리시 → RViz2에서 점 구름 확인
- slam_toolbox 연결 테스트 (mock 데이터 기준)

## 참고 (에러 로그/명령어 등)
```
(아직 없음 — 다음 세션에서 실제 실행 로그 기록 예정)
```

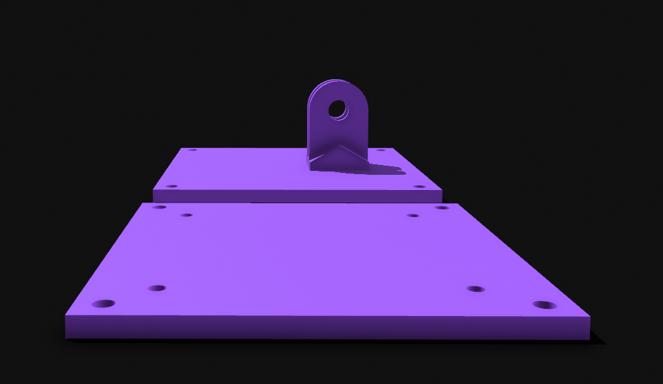
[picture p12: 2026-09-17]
hardware/images/print-sample3.png

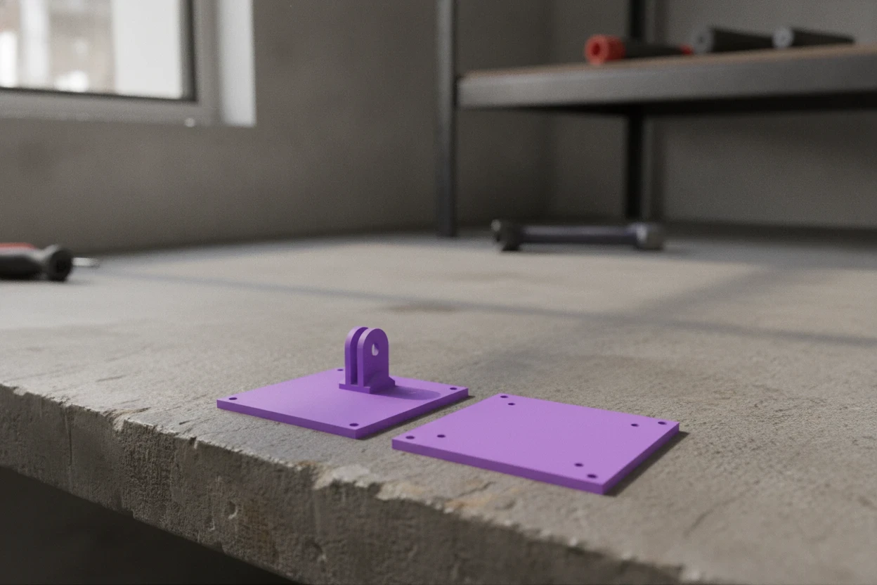
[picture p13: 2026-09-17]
hardware/images/print-sample5.webp

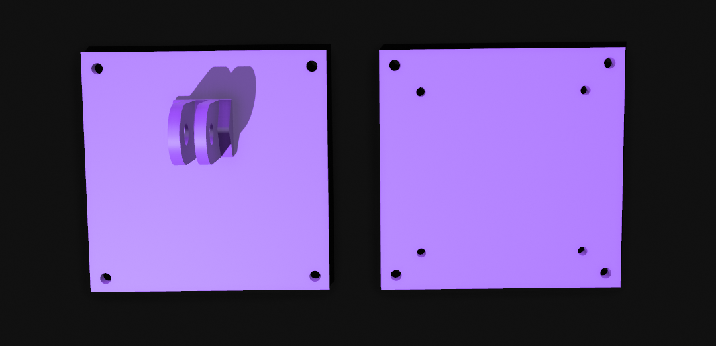
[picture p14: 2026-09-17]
hardware/images/print-sample1.png

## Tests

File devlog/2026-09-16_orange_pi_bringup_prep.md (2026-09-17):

# 2026-09-16 개발 로그 — Orange Pi 4 Pro 브링업 준비 완료 (공식 매뉴얼 확인)

## 오늘의 목표
- 하드웨어 부속품 구매 확정 (IMU, microSD, PETG, 인두기 등)
- RPLIDAR C1 마운트 나사 규격 확인
- Orange Pi 4 Pro 공식 데이터시트/매뉴얼 확보 및 브링업 관련 미확인 사항 해소

## 진행 내용

### 부속품 구매 확정
`hardware/accessories_purchase_log.md`에 전체 기록. 총 지출 ₩255,380
(RPLIDAR C1 ₩100,800 + Orange Pi 4 Pro ₩74,800 + 케이스/공구/부속 ₩79,780).
IMU는 DFRobot 정품 대신 **CJMCU-055**(Bosch BNO055 칩, 저가 클론, ₩13,040)로
최종 결정 — 칩은 동일하고 문서화도 잘 되어있어 최소비용 원칙에 부합.

### RPLIDAR C1 마운트 규격 확인 (공식 datasheet)
바닥면 마운트 나사: **M2.5 × 4개, 43×43mm 정사각 배치**. ⚠️ 나사가 바닥으로
4mm 이상 들어가면 내부 파손(공식 경고). `hardware/cad/mount_plate_and_case_v1.scad`에
반영 완료(기존 추정치 40mm → 확정값 43mm로 수정, 나사구멍도 M3→M2.5 클리어런스로 수정).

### 데이터시트 3종 확보 (`hardware/datasheets/`)
- `rplidar_c1_datasheet.pdf` (SLAMTEC 공식)
- `bno055_datasheet.pdf` (Bosch Sensortec 공식)
- `orange_pi_4_pro_user_manual_v1.4.pdf` (Shenzhen Xunlong 공식) — **가장 큰 수확**

### Orange Pi 4 Pro 브링업 관련 미확인 사항 전부 해소
공식 User Manual v1.4를 읽고 그동안 `hardware/orange_pi_4_pro_bringup_risks.md`에
"미확인"으로 남아있던 항목들을 확정값으로 갱신:

| 항목 | 이전 상태 | 확정된 내용 |
|---|---|---|
| 40핀 GPIO 핀맵 | 미확인 | 28개 GPIO, 전부 **3.3V 로직**. I2C0(SDA=3번핀, SCL=5번핀) 확인 |
| IMU 연결 가능 여부 | - | I2C0 4선(3.3V/GND/SDA/SCL)으로 바로 연결 가능 확인 |
| 물리 버튼용 여유 GPIO | - | PD0(29)/PD1(31)/PD2(33)/PD3(35)/PD4(37) 등 다수 확보 |
| OS 이미지 | Armbian 커뮤니티 이미지에 의존할 것으로 예상 | **벤더 공식 Ubuntu/Debian/Android13 이미지 존재 확인**, ROS2 Humble용 Ubuntu 22.04(Jammy) 공식 지원 확인 |
| 부팅 매체 | 미확인 | **microSD/eMMC/NVMe SSD만 지원, USB 부팅 불가** — microSD 필수 |
| 발열 모니터링 명령 | Armbian 전용 명령 가정(`armbianmonitor`) | 공식 경로 확인: `/sys/class/thermal/thermal_zone{0,1,4,5,6}/temp` (각각 CPU리틀/빅/GPU/NPU/DDR) |
| wiringOP 설치 필요 여부 | - | **이미지에 사전 설치되어 있음**, 별도 컴파일 불필요 |
| 디버그 시리얼 포트 배선 | - | 전용 3핀(GND/TX/RX, TX·RX 교차 연결), 40핀 헤더의 UART7/8과는 별개 |
| 보드 상 eMMC/HDMI 등 위치 | - | Top/Bottom View 사진으로 전체 확인(위 해당 절 참고) |
| 네트워크 | - | 기가비트 이더넷(PoE 지원) + Wi-Fi6/BT5.4 둘 다 기본 내장 |

## 막힌 문제 & 해결
| 증상 | 원인 | 해결 방법 |
|---|---|---|
| 없음 | - | - |

## 다음 단계
- microSD 도착 → orangepi.net에서 **Ubuntu 22.04(Jammy)** 이미지 다운로드 → balenaEtcher로 굽기
- 첫 부팅 시 체크리스트(`hardware/orange_pi_4_pro_bringup_risks.md` 6번) 순서대로 진행:
  RPLIDAR C1 USB 연결 확인 → 이 프로젝트 Docker 이미지 arm64 빌드 확인 → Wi-Fi 테스트 →
  slam_toolbox 부하 중 발열 모니터링(`/sys/class/thermal/thermal_zone0,1/temp`)
- IMU(CJMCU-055) 도착 시 I2C0(3번/5번핀)로 브레드보드 배선 테스트
- `hardware/orange_pi_4_pro_bringup_risks.md`의 GPIO 배선 항목(0.7번 물리 버튼용
  핀 최종 선택)을 이번에 확인된 여유 GPIO 목록 기준으로 확정

## 참고 (에러 로그/명령어 등)
```
(없음)
```

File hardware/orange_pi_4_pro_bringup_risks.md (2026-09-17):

# Orange Pi 4 Pro 이식 예상 리스크 (구매 전 사전 조사, 2026-09-08)

> 실제 보드가 아직 없는 상태에서 웹 검색으로 확인한 내용 기반 예측. 도착 후
> 실제로 겪는 문제와 다를 수 있음 — 도착하면 이 문서의 각 항목을 실측으로 검증할 것.

## 1. 확인된 진짜 리스크

### 🔴 발열 (가장 우려되는 항목)
실제 리뷰([boilingsteam.com](https://boilingsteam.com/orange-pi-4-pro-review/))에서
**"부하를 좀 걸면 온도가 금방 90°C까지 치솟아 스로틀링이 걸린다"**고 확인됨.
slam_toolbox의 Ceres 솔버 연산이 정확히 그런 지속적 CPU 부하다.

- **이 프로젝트에 미치는 영향**: 텀블러 케이스는 원래부터 "밀폐 지양, 방열판/액티브
  쿨러 필수"로 설계 문서(`README_ARCHITECTURE.md` 2.3)에 못 박아뒀는데, 이번 리뷰로
  그 필요성이 실측 근거로 확인된 셈. **패시브 방열판만으론 부족할 가능성이 높고,
  액티브 쿨링팬이 사실상 필수**로 봐야 함.
- **대응**: 구매 시 팬 포함 케이스/쿨러 키트를 같이 구매할 것. 텀블러 마운트
  설계(`hardware/tumbler_mount_design.md`)에 통풍/팬 공간을 반드시 반영.

### 🟡 OS/커뮤니티 지원이 아직 성숙하지 않음
- 공식 Armbian 프로젝트에 커뮤니티 지원이 **막 추가되는 단계**
  ([PR #9967](https://github.com/armbian/build/pull/9967), 2026년 기준 진행 중).
- 대신 서드파티 커뮤니티 이미지가 있음: [jonas5/orangepi-4pro-armbian](https://github.com/jonas5/orangepi-4pro-armbian)
  (Allwinner A733/sun60iw2용 Armbian 이미지, mainline 커널 기반).
- **✅ 확정 (2026-09-16, 공식 User Manual v1.4 확인)**: Orange Pi 벤더 자체 공식
  이미지가 실제로 존재하며 **Ubuntu, Debian, Android13을 공식 지원**한다
  (`hardware/datasheets/orange_pi_4_pro_user_manual_v1.4.pdf` 1.4절). ROS2
  Humble이 요구하는 **Ubuntu 22.04(Jammy)** 이미지도 공식 지원 목록에 있음
  (매뉴얼 3.30.2절 "Ubuntu Jammy system" 테스트 섹션 존재로 확인) — **라즈베리파이
  전용 OS 이미지는 이 보드에서 아예 부팅 안 됨(부트로더/커널 불일치), 반드시
  orangepi.net에서 이 보드 전용으로 빌드된 이미지를 받을 것.**
- **의미**: 라즈베리파이처럼 "공식 이미지 굽고 바로 씀" 수준의 매끄러움은 기대하기
  어려울 수 있으나, 벤더 공식 Ubuntu Jammy 이미지가 있다는 게 확인됐으니 커뮤니티
  Armbian 이미지에 의존할 필요는 없어짐(1순위: 벤더 공식, 2순위: Armbian).
- **다행인 점**: 우리 아키텍처는 애초에 Docker 기반이라, 호스트가 정확히 Ubuntu든
  Debian이든 상관없다 — **호스트 커널이 Docker/overlayfs/cgroup을
  지원하기만 하면 ROS2/slam_toolbox는 전부 컨테이너 안에서 그대로 동작**한다.
  이게 애초에 이 프로젝트를 Docker로 설계한 이유이고, 보드 교체 리스크를 크게 줄여준다.

### 🟢 부팅 매체 — microSD 필수 (USB 부팅 불가, 2026-09-16 확인)
공식 매뉴얼 기준 지원 부팅 매체는 **microSD / eMMC(별도 모듈) / M.2 NVMe SSD**
3가지뿐 — 일반 USB 부팅(라이브 스틱 등)은 지원 안 함. USB 포트는 OS 설치와
무관하고 PC↔보드 간 eMMC 굽기/adb 디버깅 용도로만 쓰인다. eMMC/NVMe 모듈을
따로 사지 않은 지금 상태에선 **microSD가 사실상 필수** — SanDisk 32GB 구매
완료(`hardware/accessories_purchase_log.md`).

## 1.5 전원 — 오히려 유리한 점 (2026-09-08 확인)
스펙상 **USB-C, 5V/3A(15W)** 입력. 사용자가 "보조배터리로 되냐"고 물어봐서 확인함:

- **일반 고속충전 보조배터리로 충분할 가능성이 높음** — 요즘 스마트폰 고속충전용
  보조배터리는 5V/2~3A 정도는 기본 지원하는 경우가 많음.
- **비교 참고**: Raspberry Pi 5는 공식적으로 **5V/5A(25W)**를 요구해서 전용 충전기가
  아니면 저전력 경고가 뜨거나 성능이 제한되는 걸로 유명함. Orange Pi 4 Pro는
  요구치가 더 낮아서(15W) **휴대용 보조배터리 호환성 면에서 오히려 유리**.
- **확인할 것**: 보조배터리 스펙에 "5V⎓3A" 또는 "15W" 이상 출력이 명시돼 있는지,
  케이블도 3A를 버티는지(저가 케이블은 못 버티는 경우 있음) — 구매 전 반드시 확인.
- 다만 이건 "오렌지파이라서 좋은 것"이 아니라 **이 특정 모델의 전력 요구치가
  낮은 것**뿐이다. USB-C 전원 방식 자체는 Pi5도 동일.

## 2. "통신 문제"(Wi-Fi) — 우려보다는 괜찮아 보임
보드의 Wi-Fi 6 + BT 5.4 모듈은 **AIC8800 칩셋**으로 확인되고, 커뮤니티 Armbian
이미지에 이 칩셋용 펌웨어 파일이 이미 포함되어 있는 것으로 확인됨. 즉 완전히
생소한 미지원 칩이 아니라, 이미 리눅스 드라이버/펌웨어 경로가 마련된 칩셋이다.

- **의미**: Wi-Fi 자체가 아예 안 잡히는 최악의 상황일 가능성은 낮아 보임.
- **단, 조건이 있음**: 반드시 이 보드 전용으로 빌드된 이미지(벤더 공식 또는
  jonas5의 Armbian)를 써야 한다 — 일반 범용 Ubuntu ARM 이미지를 그냥 구워서 쓰면
  Wi-Fi가 안 잡힐 가능성이 높다.
- 최악의 경우 대안: 보드에 **기가비트 이더넷**도 있으니, Wi-Fi가 문제되면 유선으로
  개발/디버깅하고 Wi-Fi 이슈는 나중에 별도로 해결하는 것도 가능.

## 3. USB(RPLIDAR 연결) 안정성 — 확인 안 됨, 도착 즉시 최우선 테스트
검색으로 이 보드 특유의 USB 전원/컨트롤러 문제 보고는 찾지 못했다. 즉 **알려진
문제가 없다는 것이지, 검증됐다는 뜻은 아니다.** 저가 SBC 일반적으로 USB 5V 레일
전류 공급이 빡빡한 경우가 종종 있어서, 실측 전까지는 미지수로 남겨둔다.

- **도착 즉시 첫 번째로 할 일**: PC에서 했던 것과 동일하게, RPLIDAR C1을 USB로
  연결하고 `rplidar_probe` 방식(GET_INFO 프로토콜 응답 확인)으로 정상 통신되는지
  가장 먼저 검증. 이 프로젝트 PC 개발 초기에 했던 것과 완전히 동일한 절차라
  재사용 가능.

## 4. Docker 구동 자체
벤더 BSP 커널이 6.6 기반으로 확인되어(비교적 최신), Docker/containerd 구동에
필요한 커널 기능(overlayfs, cgroups)은 문제없을 것으로 예상. 이 부분은 리스크가
낮다고 판단.

## 5. 상세 설정 절차 (예상 — 도착 후 실측 명령어로 갱신할 것)

아래는 Armbian/일반 SBC 관례 기준으로 미리 적어두는 예상 절차다. **정확한 명령은
실제 이미지를 받아봐야 확정되며, 도착 후 이 문서를 실측 내용으로 덮어쓸 것.**

### 5.1 OS 이미지 설치
1. 이미지 다운로드: 벤더 공식 이미지(구매 페이지/orangepi.org 다운로드 섹션) 또는
   커뮤니티 [jonas5/orangepi-4pro-armbian](https://github.com/jonas5/orangepi-4pro-armbian) 릴리즈 중 선택.
   - 헤드리스(디스플레이 없이 서버 용도)로만 쓸 거라 GUI 없는 "server/minimal" 이미지가 적합.
2. eMMC가 있으면 eMMC로 굽는 게 SD카드보다 안정적(전원 순간 끊김에 덜 취약).
   없으면 SD카드에 `balenaEtcher` 또는 `dd`로 굽기.
3. 최초 부팅 후 기본 계정/비밀번호 변경, `raspi-config` 격인 `armbian-config`
   (또는 벤더 자체 설정 툴)로 로케일/타임존 설정.

### 5.2 네트워크 & SSH
1. 유선(기가비트 이더넷)으로 먼저 붙여서 원격 SSH 접속 확보 — Wi-Fi가 바로 안
   잡힐 가능성(1.5번/2번 리스크)에 대비해 유선을 1순위로.
2. Wi-Fi는 `nmcli` 또는 `armbian-config` → Network 메뉴로 SSID/비번 등록.
3. `ssh-copy-id`로 이 PC(또는 노트북)에서 키 기반 접속 등록 — 매번 비번 입력 안 해도 되게.

### 5.3 Docker 설치
```bash
curl -fsSL https://get.docker.com | sh
sudo usermod -aG docker $USER   # dialout 그룹도 같이: sudo usermod -aG dialout $USER
# 재로그인 후 확인
docker run hello-world
```

### 5.4 프로젝트 이식
```bash
git clone git@github.com:greenhelix/PortableLidarMapper.git
cd PortableLidarMapper
./docker/run_dev.sh --build --with-lidar
```
`ros:humble-ros-base` 등 우리가 쓰는 베이스 이미지들은 공식적으로 arm64 빌드를
제공하므로, **`docker build` 명령 자체는 코드 수정 없이 그대로 실행되는 게
정상**이다. 여기서 에러가 나면 그게 이 이식 과정의 핵심 검증 실패 지점.

### 5.5 GPIO/I2C 핀맵 — 확정됨 (2026-09-16, 공식 User Manual v1.4 확인)
`hardware/datasheets/orange_pi_4_pro_user_manual_v1.4.pdf` 3.15절("40 Pin
Interface Pin Description")에서 확인:

- 40핀 중 **GPIO 28개 사용 가능, 전부 3.3V 로직**(5V 아님 — IMU/버튼 배선 시
  반드시 3.3V 핀에서 전원을 따야 함, 5V 핀에 물리면 레벨 미스매치 위험)
- **I2C0**: SDA = 물리핀 3번, SCL = 물리핀 5번 — IMU(BNO055/CJMCU-055) 연결에
  바로 사용
- **여유 GPIO(버튼용 후보)**: PD0(29번), PD1(31번), PD2(33번), PD3(35번),
  PD4(37번) 등 다수 — 0.7번(물리 시작/정지 버튼) 배선 시 이 중 하나 사용
- **wiringOP가 이미지에 사전 설치되어 있음** — 별도 컴파일 없이 `gpio readall`
  명령으로 바로 핀 상태 확인 가능
- I2C/SPI 커널 오버레이 활성화 여부는 `gpio readall` 결과로 판단(이미 활성화된
  상태로 보임, wiringOP 프리인스톨 자체가 그 근거) — 실기 도착 후 실제 명령
  실행으로 최종 확인

### 5.6 발열 모니터링 — 공식 명령 확인됨 (2026-09-16, User Manual 3.14절)
A733에 온도 센서 5개 내장, 공식 확인된 명령:
```bash
# CPU 리틀코어(A55)
cat /sys/class/thermal/thermal_zone0/temp   # cpul, 단위: milli-°C, 1000으로 나눠서 °C
# CPU 빅코어(A76)
cat /sys/class/thermal/thermal_zone1/temp   # cpub
# GPU
cat /sys/class/thermal/thermal_zone4/temp
# NPU
cat /sys/class/thermal/thermal_zone5/temp
# DDR(메모리)
cat /sys/class/thermal/thermal_zone6/temp
```
slam_toolbox 부하 테스트 중 이 값들(특히 cpul/cpub)을 `watch -n1`으로 계속
관찰해서 90°C 근처까지 가는지 확인. 쓰로틀링 여부는 `dmesg | grep -i throttl`로
확인(Armbian 전용 `armbianmonitor`는 벤더 공식 이미지에선 없을 수 있음 — 위
공식 경로가 더 확실함).

## 6. 요약 — 예상 체크리스트 (도착 후 순서대로 검증)

### 6.0 실행 순서 확정 (2026-09-17, microSD 도착 즉시 진행)
1. [ ] **microSD 도착 → Orange Pi 세팅 시작**: Ubuntu(Jammy 22.04, ROS2 Humble
   호환) 공식 이미지 설치, 기본 기능(부팅/SSH/네트워크) 파악, **전원 확인**
   (5V/3A 보조배터리 출력 확인 — 1.5번 참고)
2. [ ] **RPLIDAR C1을 Orange Pi에 연결 확인** (USB, PC 때와 동일 절차로 프로토콜
   응답 확인)
3. [ ] **IMU(CJMCU-055)를 Orange Pi에 연결 확인** (I2C, 물리핀 1/3/5/6 —
   `devlog`의 IMU 배선도 참고)
4. [ ] **보조배터리 전원으로 Orange Pi 정상 작동 확인** (벽전원 대신 배터리로
   구동했을 때 이상 없는지)

이후 아래 6.1번(상세 체크리스트)으로 진행.

### 6.1 상세 체크리스트
0. [ ] **(구매 전)** 보유 중이거나 살 보조배터리가 5V/3A(15W) 이상 출력, 케이블도
   3A 대응인지 확인 — 위 1.5번 참고
1. [ ] 벤더 공식 이미지 vs jonas5 커뮤니티 Armbian 이미지 중 선택, 설치
   (2026-09-16 확인: 벤더 공식 Ubuntu Jammy 이미지 존재 — 이걸 1순위로)
2. [ ] Docker 설치 및 `docker run hello-world` 확인
3. [ ] RPLIDAR C1 USB 연결 → 프로토콜 응답 확인 (PC 때와 동일 절차)
4. [ ] 이 프로젝트의 `docker/Dockerfile`을 arm64로 빌드 (별도 코드 수정 없이 되는지가 핵심 검증 포인트)
5. [ ] Wi-Fi 연결 테스트 (안 되면 이더넷으로 우회)
6. [ ] 부하 테스트(slam_toolbox 실행) 중 온도 모니터링 (`cat /sys/class/thermal/thermal_zone{0,1}/temp`) → 쓰로틀링 여부 확인, 필요시 쿨링 보강

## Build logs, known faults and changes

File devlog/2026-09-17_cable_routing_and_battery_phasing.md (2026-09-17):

# 2026-09-17 개발 로그 — 배터리 단계별 전략 확정 + 케이블/파우치 설계

## 오늘의 목표
- 배터리 용량 단계별 전략 확정
- 어깨끈 마운트(라이다+IMU) ↔ Orange Pi+배터리(가방 내부) 간 케이블 연결/보호 방법 설계
- Orange Pi+배터리를 담을 파우치 선정

## 진행 내용

### 배터리 단계별 전략 확정
- **지금(안정화 단계)**: 10000mAh급 소형 배터리 사용 — 사용시간 약 1.75~2.1시간이지만,
  아직 초기 테스트 단계라 장시간 구동 불필요
- **나중(안정화 후)**: 30000mAh급(N6 등, 111Wh, 약 5~6시간)으로 교체 예정
- **부가 효과**: 10000mAh급은 사이즈가 대략 100×65×18mm 근처라, 지난번 문제였던
  "30000mAh 배터리(151×73×20mm)가 ⌀80mm 쉘에 안 들어가는 문제"가 지금 단계에선
  발생하지 않음 — 쉘 지름을 당장 85mm로 키울 필요 없음. 나중에 큰 배터리로
  교체할 때 쉘 재설계 필요.

### 케이블 연결/보호 설계
어깨끈 마운트(라이다+IMU) ↔ 가방 내부(Orange Pi+배터리) 사이 배선 방법 검토:
- **라이다**: RPLIDAR C1은 이미 USB 케이블이라, 일반 **USB 연장 케이블(USB-A
  M-F, 0.5~1m)**로 간단히 길이 연장 가능 — 점퍼선 필요 없음
- **IMU(I2C, 4선)**: 점퍼선이 너무 짧은 문제 확인 — 더 긴 듀폰선 세트 구매 또는
  DIY로 4핀 케이블 제작 필요. 스파이럴 랩/케이블 슬리브로 묶어서 한 가닥처럼
  깔끔하게 정리하고 보호하는 방향으로 결정
- **케이블 경로**: 어깨끈 시접선(seam)을 따라 배선 후 소형 케이블타이/벨크로로
  중간중간 고정, 가방 지퍼 틈으로 내부 진입

### 파우치 선정
Orange Pi(89×56×20mm 추정)+배터리(10000mAh, 약 100×65×18mm)를 같이 담을
소형 전자기기 정리 파우치 검토 — 상세는 대화 기록 참고.

## 막힌 문제 & 해결
| 증상 | 원인 | 해결 방법 |
|---|---|---|
| IMU 배선용 점퍼선이 너무 짧음 | 시중 기본 세트가 대부분 20cm 이하 | 긴 길이 세트 구매 또는 커스텀 제작(스파이럴 랩으로 정리) |

## 다음 단계
- 긴 듀폰선 세트 또는 4핀 JST 케이블 재료 구매
- USB 연장 케이블 구매
- 케이블 슬리브/스파이럴 랩 구매
- 소형 전자기기 파우치 구매

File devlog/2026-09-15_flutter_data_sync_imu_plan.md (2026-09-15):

# 2026-09-15 개발 로그 — Flutter 앱 + 데이터 동기화 + IMU + 라이다 한계 극복 설계 확정

## 오늘의 목표
- Flutter 앱/데이터 동기화/IMU 선정 등 8가지 요구사항을 종합 설계로 정리하고 승인받기
- 문서(README/README_ARCHITECTURE) 반영 + devlog 기록 + git 커밋

## 진행 내용
- **설계 계획 승인 완료** (`/home/kani/.claude/plans/purring-honking-twilight.md`, 코드
  구현은 아직 없음, 설계 문서만 확정):
  - IMU 9축(나침반 포함)으로 추천 방향 수정 — 산길(실외) 사용 확정에 따라
    지자기 나침반 신뢰도 재평가
  - 온디맨드 연결 모델(0.5) + 명시적 시작/정지 트리거(0.7, 부팅 자동시작 금지)
  - **라이다 한계 극복 전략(0.8, 신규)**: 텀블러+가방 옆주머니 장착 특성상
    가림각/회전오차/도보속도/동적장애물/숲길 5가지 문제를 `laser_filters`
    (ROS2 표준 필터체인) + `robot_localization`(EKF 센서퓨전)으로 대응.
    새 알고리즘 개발 없이 표준 패키지 조합+설정 튜닝으로 해결
  - Store-and-Forward 데이터 동기화(1) + 자동 데이터 최적화(2)
  - 관계형 DB 스키마(2.5): `locations`+`building_details`/`mountain_details`+`sessions`
  - **진화형 지도 축적(2.6, 신규)**: slam_toolbox의 `serialize_map`/`deserialize_map`
    으로 재방문 시 이전 지도에 이어서 매핑 — 재방문 데이터를 중복이 아니라
    완성도를 높이는 히스토리로 누적(`map_versions` 테이블)
  - Flutter 앱 Tier1(7개)/Tier2(3개)/Tier3(3개) 기능 목록, MVVM+Riverpod 구조
  - AI 연동 2단계 분리(4.5): 1단계 규칙 기반 환경 프리셋(SLAM+필터 체인 묶음),
    2단계 진짜 AI 자동 조정(나중)
- **3D 라이다/카메라 대안 검토** (전부 웹 검색으로 실가격 확인):
  - Livox Mid-360($734), Unitree L1(€220~275, 단종) — 스피닝형, 비용상 배제
  - 국내 슬램텍 A2M12/YDLIDAR G6·G4 — 확인해보니 전부 **2D**였음(3D 아님)
  - CygLiDAR D2($181.95, solid-state ToF) — 사용자가 발견, 저렴한 진짜 3D지만
    FOV가 120°/65°로 360° 회전 스캔 전제와 안 맞아 채택 안 함
  - 카메라(RGB)로 3D를 흉내내는 건 불가능(카메라 자체는 깊이 정보가 없음) —
    사물인식(Tier3) 목적이라면 저가 웹캠+AI가 깊이센서보다 목적에 맞음
- **Phase 2를 하드웨어 도착 순서 기준 페이지 0~3으로 세분화** (README_ARCHITECTURE
  5.5 신규): 페이지0(지금, PC로 앱 선개발) → 1(오렌지파이 도착) → 2(IMU 도착) →
  3(물리버튼+실사용 필드 테스트+백엔드 구현). Tier1 앱 기능 대부분은 rosbridge
  프로토콜이 PC/보드 동일해서 오렌지파이 도착 전인 지금부터 개발 가능함을 확인
- EKF(확장 칼만 필터) 작동 원리, LaserScan 메시지 구조, RPLIDAR C1 스캔 주파수
  조절 가능 범위(10~20Hz) 등 사용자 질문에 답변, 관련 아티팩트 3개 발행
  (data_sync_diagram, db_schema_diagram, ekf_diagram)
- README.md/README_ARCHITECTURE.md에 위 내용 전체 반영 (3.5번 신규 섹션 등)

## 막힌 문제 & 해결
| 증상 | 원인 | 해결 방법 |
|---|---|---|
| 없음 (설계 단계, 코드 실행 이슈 없었음) | - | - |

## 다음 단계
- 페이지0: PC rosbridge 기준으로 Flutter Tier1 앱 개발 착수 (연결화면, 수집
  시작/정지, 지도뷰어, 필터 프리셋 패널 등 — 하드웨어 무관 항목부터)
- 오렌지파이 도착 전 부품 준비: 액티브 쿨링(가장 급함), microSD+리더기,
  IMU 모듈(DFRobot SEN0374), GPIO 버튼
- `laser_filters`/`robot_localization` 패키지를 PC Docker 이미지에 추가해서
  필터/센서퓨전 기능부터 선검증
- `lidar_mapper_db`에 `get_sessions`/`log_event` 등 ROS2 서비스 추가 (백엔드
  선행 작업, Tier1-1/4/5 앱 기능이 여기 의존)

## 참고 (에러 로그/명령어 등)
```
(없음)
```

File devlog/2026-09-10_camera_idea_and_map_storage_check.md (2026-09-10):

# 2026-09-10 개발 로그 (2) — 카메라 확장 아이디어, 지도 저장공간 오해 해소

## 오늘의 목표
- 텀블러 마운트 치수 검토(부품 실치수 기반) 문서화
- 카메라 확장 아이디어 로드맵 기록
- "지도가 넓어지면 저장공간을 많이 쓰는가" 확인

## 진행 내용
- **부품 치수 검토**: RPLIDAR C1(⌀75mm×H40mm), Orange Pi 4 Pro(89×56mm, 웹
  검색으로 실치수 확인), IMU(21×16mm)를 스케일 다이어그램으로 겹쳐봄. 결론:
  완전 커스텀 하드케이스는 불필요, 보드를 세로로 세우면 대부분의 후보 텀블러에
  들어감 — 다만 세로 고정용 작은 내부 브라켓은 필요(이미 계획에 있던 항목,
  치수로 재확인). `hardware/tumbler_mount_design.md` 1.7번에 반영.
- **카메라 확장 아이디어**: 프로젝트와 별개로 "STB에 라이다를 붙이면 어떨까"
  브레인스토밍을 하다가, 저가 카메라를 이 프로젝트에 붙이는 것도 같이 검토.
  결론: 몸통 가림/빠른 회전 문제는 카메라로 안 풀림(오히려 저가 카메라는 모션
  블러로 더 약함) — 이 두 문제엔 IMU가 정답. 카메라는 "사물 인식으로 지도를
  풍부하게" 라는 별도 가치가 있고, Phase 1·2 완료 후에나 검토할 항목으로 기록.
  `hardware/tumbler_mount_design.md` 7번에 반영.
- **저장공간 오해 해소**: 사용자가 "지도가 넓게 잡히는데 저장공간 많이 쓰는거
  아니냐"고 질문 — 확인 결과 **`/map`은 RAM에만 있고 디스크에 저장 안 됨**,
  저장공간 문제 없음. 다만 확인 과정에서 **이 컨테이너가 또 2일간 방치되어
  있었던 걸 발견**(이번엔 사용자가 아니라 내가 직접 만든 실수 — 수동 테스트
  명령에 로그 순환 옵션을 빠뜨림, 실제 로그 16.6MB 무제한 누적 중이었음).
  컨테이너 중지로 정리함.
- **리셋 기능 조사**: `/slam_toolbox/clear_changes`(타입 `slam_toolbox/srv/Clear`)
  서비스 존재 확인했으나, 실제 호출 시 응답 없이 걸려서 정확한 동작(전체 지도
  초기화인지, 수동 보정 취소용인지)은 검증 못 함 — 지금 확실한 리셋 방법은
  컨테이너 재시작뿐. Flutter 앱의 "세션 상태/리셋 패널" 아이디어로 로드맵에 기록.

## 막힌 문제 & 해결
| 증상 | 원인 | 해결 방법 |
|---|---|---|
| 컨테이너가 또 2일 방치됨 | 이번엔 Claude 본인이 RViz2 수동 테스트 시 `--log-opt` 로그 순환 플래그를 빠뜨림(run_dev.sh 스크립트를 안 쓰고 직접 docker run 명령을 짜서 발생) | 컨테이너 중지. 앞으로 수동 docker run 시에도 항상 로그 순환 플래그 포함하도록 스스로 체크 |
| `clear_changes` 서비스 호출이 응답 없이 걸림 | 정확한 원인 미확인(인터랙티브 모드 전제 조건일 가능성, 또는 exec 세션의 DDS 디스커버리 지연) | 미해결 — 지금은 컨테이너 재시작으로 우회, 필요시 추후 재조사 |

## 다음 단계
- 위 미검증 항목(`clear_changes` 정확한 동작)은 실제 필요해질 때 다시 조사
- 텀블러 후보 실측이 여전히 가장 중요한 다음 물리 작업

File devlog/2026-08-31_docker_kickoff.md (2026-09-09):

# 2026-08-31 개발 로그 — 프로젝트 킥오프 & Docker 개발 환경 전환

## 오늘의 목표
- 프로젝트 전체 방향/문서 백브리핑
- 라이다 USB 연결 상태 실제 확인
- PC-Pi5 이식을 고려한 개발 환경(배포판) 방침 확정

## 진행 내용
- 문서(`README_ARCHITECTURE.md`, devlog, hardware, config) 검토 완료. 프로젝트 방향 재확인.
- **라이다 USB 감지 확인**: `/dev/ttyUSB1`에서 Silicon Labs CP2102N 칩 인식 확인.
  단순 lsusb 수준이 아니라 RPLIDAR 프로토콜(GET_INFO, 0xA5 0x50)로 직접 통신해서
  응답 확인 (`model=65, fw=1.2, hw=18`, 460800bps). 하드웨어 정상 동작 확인됨.
- **문제 발견**: `README_ARCHITECTURE.md`는 Ubuntu 22.04 + ROS2 Humble을 전제하지만
  실제 PC는 Ubuntu 20.04(focal)이고 ROS2 미설치 상태였음 (`scripts/setup_env.sh`가
  이 상태로는 Humble 설치에 실패할 상황).
- 사용자와 상의 후 **Docker 기반 개발 환경으로 전환 결정**:
  - `docker/Dockerfile`: `ros:humble-ros-base` + slam_toolbox + rosbridge_server +
    nav2-map-server + colcon + pyserial 설치.
  - `docker/run_dev.sh`: mock 전용 실행(`./run_dev.sh`) / 실제 라이다 패스스루
    (`./run_dev.sh --with-lidar`, `/dev/ttyUSB*` `/dev/ttyACM*` 자동 감지) 지원.
    빌드 산출물(`build`/`install`/`log`)은 named volume으로 유지해서 매번 재빌드
    안 되게 처리.
  - `docker/README.md`: PC/WSL2/Mac 환경별 사용법 정리.
    - PC(여기): 라이다 실기 테스트 가능한 유일한 환경.
    - WSL2: mock 위주, 실기 테스트하려면 `usbipd-win` 별도 설정 필요.
    - Mac: Docker Desktop이 USB 패스스루 미지원 → mock 개발 + PC 컨테이너의
      rosbridge(9090)에 원격 Foxglove 접속으로 시각화 확인하는 용도로 한정.
- **컨테이너 동작 검증 완료**:
  - `docker build` 성공.
  - 컨테이너 안에서 `--device /dev/ttyUSB1` 패스스루로 RPLIDAR GET_INFO 응답
    재확인 (호스트에서와 동일 결과) — USB 패스스루 정상 동작 확인.
  - `colcon build` 로 `lidar_mapper_mock`, `lidar_mapper_bringup` 두 패키지
    정상 빌드 확인.
- `README_ARCHITECTURE.md` 갱신: 개발 환경 항목에 Docker 명시, 로드맵 체크리스트
  갱신(Docker 환경 구축/라이다 확인 완료 표시).

## 막힌 문제 & 해결
| 증상 | 원인 | 해결 방법 |
|---|---|---|
| PC가 20.04라 ROS2 Humble 네이티브 설치 불가 | 아키텍처 문서가 22.04 전제로 작성됨, 실제 PC는 20.04 | Docker 컨테이너(`ros:humble-ros-base`, 내부는 22.04)로 통일. 호스트 OS 변경 없이 해결 |
| `docker compose` 명령 없음 | compose plugin 미설치, apt 저장소에도 없음(docker 설치 경로가 일반 apt repo 아님) | compose 없이 plain `docker run` 스크립트(`run_dev.sh`)로 대체 — 의존성 최소화 |
| scratchpad에 쓴 임시 진단 스크립트가 이후 permission denied로 안 써짐 | `docker run -v <미존재 host 경로>:...` 시 Docker가 root 권한으로 디렉터리를 자동 생성해서 소유권이 root로 바뀜 | 이후 호스트-컨테이너 파일 공유가 필요한 임시 테스트는 파일 마운트 대신 `python3 -c "..."` 인라인 스크립트로 우회 |

## 다음 단계
- `docker/run_dev.sh` 로 컨테이너 진입 → `lidar_mapper_mock` + slam_toolbox 로
  mock `/scan` → 지도 그려지는 흉내 확인 (Foxglove 또는 RViz2)
- 실제 C1로 `sllidar_ros2` 붙여서 `use_mock:=false` 실데이터 파이프라인 확인
- SQLite 스키마 설계 착수 (`lidar_mapper_db`, 아직 미착수)
- 텀블러 실측 → `hardware/tumbler_mount_design.md` 치수 확정
- Pi5 구매 시점은 여전히 미정 (가격 추이 관찰 중) — Pi5 도착 시 이 Docker 이미지를
  그대로 옮기는 것으로 이식 전략 확정

## 참고 (에러 로그/명령어 등)
```
# RPLIDAR GET_INFO 응답 (호스트/컨테이너 동일)
$ python3 -c "... GET_INFO 0xA5 0x50 ..."
bytes: 27 a55a140000000441020112857dfc8bc6e598d1b59598f906df5762
RPLIDAR DETECTED model=65 fw=1.2 hw=18

# Docker 빌드/실행
$ docker build -t lidar_mapper_dev:humble -f docker/Dockerfile docker
$ docker run --rm --device /dev/ttyUSB1 -v $PWD/src:/lidar_ws/src lidar_mapper_dev:humble \
    bash -c "source /opt/ros/humble/setup.bash && cd /lidar_ws && colcon build --symlink-install"
# Summary: 2 packages finished
```

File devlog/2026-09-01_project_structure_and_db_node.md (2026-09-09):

# 2026-09-01 개발 로그 — 프로젝트 구조 확정 & lidar_mapper_db 노드 버그 수정

## 오늘의 목표
- 사용 언어/플랫폼/프로그램 구성 확정
- `lidar_mapper_db`(SQLite 저장) 노드 구현 및 검증
- AI 에이전트 연동 "자리" 마련
- Flutter 앱 스캐폴딩

## 진행 내용
- **언어/플랫폼 결정**: 엣지·백엔드는 Python(ROS2 기존 스택 유지), 모바일 시각화 앱은
  Flutter(Dart)로 확정. 마켓플레이스/랭킹/게임화는 지금 범위에서 제외, 아이디어로만 기록.
- **AI 에이전트 자리 마련** (`ai/`): `AIProvider` 추상 인터페이스 + `NullProvider`
  기본 구현 + provider 레지스트리(`ai/providers/__init__.py`). config.yaml의 provider
  이름만 바꾸면 Anthropic/OpenAI/중국계(Qwen 등) 어떤 모델도 교체 가능하도록 설계.
  지금은 API 호출 없는 NullProvider만 존재.
- **`lidar_mapper_db` 패키지 신설**: `/session_event`, `/session_end` 토픽을 구독해서
  세션 이벤트를 모았다가 종료 시 AI provider로 요약 후 SQLite(`sessions` 테이블)에 저장.
  `rooms` 테이블 스키마도 함께 정의(방 이름/카테고리, 아직 채우는 로직은 없음 — 추후
  음성 태깅 등으로 채울 예정).
- **Flutter 앱 스캐폴딩**: `app/lidar_mapper_app` (Android 타겟) 생성, `flutter create`로
  기본 골격만 확보.
- **Docker 개발 환경 보완**: `ai/`, `data/` 디렉터리를 컨테이너에 마운트하도록
  `docker/run_dev.sh` 갱신.

## 막힌 문제 & 해결
| 증상 | 원인 | 해결 방법 |
|---|---|---|
| `ros2 run lidar_mapper_db session_logger_node` → "No executable found" (mock 패키지도 동일) | ROS2 ament_python 패키지에 **`setup.cfg`가 빠져 있어서** setuptools가 실행파일을 `install/<pkg>/lib/<pkg>/` 대신 `install/<pkg>/bin/`에 설치함. colcon(`colcon_core.task.python.build._get_install_scripts`)이 `setup.cfg`의 `[install] install-scripts` 값을 읽어서 `--install-scripts`를 setuptools에 넘기는 구조인데, 이 값이 없으면 기본 위치(`bin/`)로 감. Docker/setuptools 버전 문제로 오인해서 setuptools 58.2.0 다운그레이드도 시도했으나 무관했음(원인 아님, 되돌림) | `src/lidar_mapper_mock/setup.cfg`, `src/lidar_mapper_db/setup.cfg`에 `script_dir`/`install_scripts`를 `$base/lib/<pkg명>`으로 지정하는 표준 ROS2 ament_python 보일러플레이트 추가. 재빌드 후 `ros2 pkg executables`에 정상 노출 확인 |
| `docker/run_dev.sh`에 `--user "$(id -u):$(id -g)"` 추가 후 컨테이너에서 라이다 데이터 파일이 root 소유로 생성됨 → 이어서 `--user`로 고치자 이번엔 `rclpy_logging_configure: failed to initialize logging: Failed to create log directory: //.ros/log` 에러 발생 | 호스트 UID로 컨테이너를 실행하면 `/etc/passwd`에 해당 UID의 계정이 없어 `HOME`이 빈 문자열이 되고, ROS2가 `$HOME/.ros/log`를 만들려다 실패 | `docker run`에 `-e HOME=/lidar_ws` 명시. `Dockerfile`에도 `/lidar_ws`를 `chmod 777`로 미리 열어둬서 비루트 UID로도 build/install/log/data에 쓸 수 있게 함 |

## 추가 진행 (같은 날, mock 파이프라인 첫 실가동)
- `./docker/run_dev.sh` 방식으로 mock 파이프라인(`bringup.launch.py use_mock:=true`)을
  백그라운드 컨테이너로 실행해서 실제로 `/map`이 채워지는지 확인.
- **버그 1**: mock 데이터는 오도메트리가 없어서 slam_toolbox가 스캔을 map 좌표계로
  변환하지 못해 `/map`이 계속 빈 상태였음.
  → 원인: `laser` 프레임에서 `map`까지 이어지는 TF 체인이 아예 없었음.
  → 해결: `bringup.launch.py`에 mock 전용 고정(identity) TF 3개 추가
  (`map→odom→base_footprint→laser`, `use_mock` 조건에서만 켜짐). 이후 `/map`이
  122x122 격자(mock이 흉내내는 방 크기와 일치)로 정상 생성됨을 확인.
- **버그 2**: Foxglove로 `ws://localhost:9090` 접속은 성공했지만 rosbridge 로그에
  `call_service /rosapi/topics_and_raw_types` 가 계속 실패(`InvalidServiceException`).
  → 원인: `rosapi_node`를 launch에 포함하지 않아서, rosbridge 연결 자체는 되어도
  클라이언트가 토픽/타입 목록을 조회하는 서비스가 없었음.
  → 해결: 돌고 있던 컨테이너에는 `ros2 run rosapi rosapi_node`로 즉시 추가해서
  중단 없이 살리고, `bringup.launch.py`/`package.xml`에도 영구 반영(`use_rosbridge`
  조건에 같이 묶음).

## 추가 진행 (같은 날, 실제 RPLIDAR C1 첫 실가동)
- `docker/Dockerfile`에 `sllidar_ros2`(RPLIDAR 공식 드라이버)를 `/opt/sllidar_ws`
  오버레이로 빌드해 추가. 우리가 계속 수정하는 `src/`(볼륨 마운트)와 분리해서,
  외부 의존성은 이미지 안에 고정 빌드.
- `bringup.launch.py`에 `lidar_serial_port` 인자 추가, `use_mock:=false`일 때
  `sllidar_c1_launch.py`에 전달하도록 연결. 고정 TF 체인(map→odom→base_footprint→laser)은
  mock 전용이 아니라 실기에도 동일하게 필요해서 조건 없이 항상 켜지도록 변경
  (아직 오도메트리가 없어서 정지 가정은 mock/실기 공통 임시 방편).
- **버그**: `--user "$(id -u):$(id -g)"`로 컨테이너를 돌리면서 `/dev/ttyUSB1`
  접근이 `Error, unexpected error, code: 80008004`로 즉시 실패.
  → 원인: 호스트 UID만 넘기고 `dialout` 그룹(GID 20)을 안 넘겨서 문자 장치 권한 없음.
  → 해결: `docker run --group-add 20` 추가.
- **에피소드**: 권한 문제 해결 직후 `sllidar_node`가 `SL_RESULT_OPERATION_TIMEOUT`으로
  다시 죽었고, 이후 호스트에서 직접 pyserial로 찔러봐도 응답이 아예 없어짐(이전엔
  잘 응답했음). USB를 물리적으로 뽑았다 다시 꽂으니 재인식되고 정상 응답 복구됨.
  → 짐작되는 원인: 크래시 전에 모터/스캔이 시작된 상태로 프로세스가 죽으면서 장치가
  응답 불가 상태로 걸림. 소프트웨어 재시도로는 못 풀었고 물리적 재연결이 유일한 해결책이었음.
- **최종 확인**: `sllidar_node`가 실제 하드웨어 인식(S/N, 펌웨어 1.02, health OK,
  Standard 모드 5kHz/16m/10Hz) 하고, `/scan`(실측 각도 범위 ±π), `/map`(129x86,
  mock 때와 다른 비대칭 격자 — 실제 방 형태 반영)까지 정상 확인.

## 추가 진행 (같은 날, 오도메트리 부재로 인한 "지도 확장 안 됨" 버그 수정)
- **증상**: 라이다를 실제로 들고 새로운 공간 쪽으로 이동해도 `/map`이 넓어지지 않음.
- **원인**: 이전까지 쓰던 TF 체인이 `map→odom→base_footprint`를 전부 identity 고정값으로
  발행하고 있었음 — 즉 시스템 입장에서는 라이다가 "제자리에 정지"해 있다고 가정.
  slam_toolbox는 직전 위치 근처의 좁은 탐색 범위에서만 스캔 매칭을 시도하기 때문에,
  실제로 크게 이동하면 새 스캔을 기존 지도와 매칭 못 하고 무시함.
- **해결**: 바퀴 인코더가 없는 휴대용 기기 특성에 맞춰 **rf2o_laser_odometry**
  (연속된 라이다 스캔끼리 비교해서 이동을 추정하는 2D 레이저 오도메트리) 도입.
  - `docker/Dockerfile`에 `/opt/rf2o_ws` 오버레이로 빌드 추가 (GitHub `ros2` 브랜치,
    apt 패키지는 Humble용이 없어서 소스 빌드).
  - `bringup.launch.py` TF 구성 변경: `map→odom`은 slam_toolbox가 알아서 발행하도록
    맡기고(직접 발행 제거), `odom→base_footprint`는 rf2o가 스캔 기반으로 동적 발행,
    `base_footprint→laser`(센서 마운트 오프셋)만 계속 고정값 유지.
  - 실기로 재검증: rf2o 로그에 `Laser odom [x,y,yaw]=...` 값이 실시간으로 잡히고,
    `/map`도 정상 발행 계속됨 확인. (다만 실제로 걸어다니며 지도가 안 깨지는지는
    사용자가 직접 들고 이동해보며 추가 확인 필요 — 이 세션에서는 정적 검증까지만 완료)

## 추가 진행 (같은 날, 지도 갱신 속도 튜닝)
- **증상**: `/map`이 넓어지긴 하는데 체감상 너무 느리게 갱신됨.
- **원인**: slam_toolbox 기본 설정(`mapper_params_online_async.yaml`)의
  `map_update_interval: 5.0`(5초에 한 번만 지도 재계산/발행) — 로봇 기준 기본값이라
  사람이 걷는 속도엔 너무 느림. `config/slam_params_notes.md`에서 이미 예상했던
  `minimum_travel_distance`/`minimum_travel_heading` 튜닝 필요성과 같은 맥락.
- **해결**: `config/mapper_params_online_async.yaml` 신설 (기본값 복사 + 튜닝):
  `map_update_interval` 5.0→0.5, `minimum_travel_distance` 0.5→0.1,
  `minimum_travel_heading` 0.5→0.2. `bringup.launch.py`가 slam_toolbox의
  `online_async_launch.py`에 `slam_params_file:=/lidar_ws/config/mapper_params_online_async.yaml`
  로 전달하도록 연결(`docker/run_dev.sh`가 프로젝트 `config/`를 그 경로에 이미 마운트해둠).
  `ros2 topic hz /map`으로 실측: 0.5초 간격(초당 2회)으로 정상 갱신 확인.
- Foxglove의 점 크기는 SLAM/코드와 무관한 UI 설정(3D 패널 → `/scan` → Point size)이라
  코드 수정 없이 화면에서 바로 조절 가능하다고 안내.
- 휴대 불가 문제는 현재 설계상 당연한 상태(Pi5 미구매, PC에 라이다 USB 직결)임을 설명 —
  Pi5 구매 전까지는 파이프라인 검증 단계로 규정.

## 추가 진행 (같은 날, 로그 무한 적재 방지)
- 사용자 질문: "오래 돌리면 로그 너무 많이 쌓이는 거 아니냐" → 맞는 지적.
  ROS2 자체 로그(`.ros/log`)는 컨테이너 안에만 있다가 `--rm`으로 같이 삭제되지만,
  **Docker가 컨테이너 stdout을 호스트에 기록하는 기본 로그 드라이버는 크기 제한이
  없어서** slam_toolbox/rf2o처럼 초당 여러 줄 찍는 노드를 오래 돌리면 커질 수 있음.
- `docker/run_dev.sh`에 `--log-opt max-size=10m --log-opt max-file=3` 추가해서
  파일당 10MB, 최대 3개(총 30MB)로 자동 순환되게 함.

## 추가 진행 (2026-09-04, 손 흔들림으로 인한 지도 노이즈 진단)
- 사용자가 Foxglove 화면 캡처 공유: 방사형으로 뻗는 검은 줄무늬 패턴의 지저분한 점 구름.
  "AI/로직으로 아웃라인만 추출하는 알고리즘이 필요한 거 아니냐"는 질문.
- **진단**: 이 패턴은 원본 `/scan`을 여러 프레임 누적해서 볼 때 나오는 전형적인
  모양이라, `/map`(occupancy grid)과 별도로 봐야 정확한 판단이 됨. 또한 occupancy
  grid 자체가 이미 "광선이 처음 부딪힌 지점만 격자화"하는 방식이라 사용자가 원하는
  "아웃라인 추출"을 이미 하고 있음 — 부족한 건 알고리즘이 아니라 **입력 오도메트리의
  신뢰도**. 손으로 든 라이다는 바퀴 로봇보다 훨씬 빠르고 불규칙하게 방향이 바뀌어서
  rf2o 추정이 흔들리고, slam_toolbox의 스캔 매칭 탐색 범위(기본/기존 0.5m)를
  벗어나면 보정 실패한 나쁜 위치값을 그냥 받아들여 지도가 어긋남.
- **적용한 튜닝** (`config/mapper_params_online_async.yaml`):
  - `correlation_search_space_dimension` 0.5 → 1.0 (오도메트리 오차 허용 범위 확대)
  - `minimum_travel_heading` 0.2 → 0.35 (너무 낮춰서 손이 홱홱 돌아갈 때의 잡음까지
    다 스캔 처리 대상이 되던 부작용 완화, 응답성과 절충)
  - `bringup.launch.py`: rf2o `freq` 20.0 → 10.0 (실제 RPLIDAR C1 스캔 속도에 맞춤,
    불필요한 "Waiting for laser_scans" 루프 낭비 제거)
- **근본적 한계 재확인**: 2D 라이다 기반 스캔 매칭만으로는 빠른 회전/기울기에 완전히
  강건해지기 어려움. 진짜 robust하게 하려면 IMU를 붙여서 `robot_localization`(EKF)로
  rf2o 오도메트리와 융합하는 게 표준적인 해법이지만, 지금 하드웨어(IMU 없음)로는
  적용 불가 — 이전 질문(높낮이/기울기 커버 여부)에서 답변한 "짐벌/평탄화 마운트
  필요성"과 같은 근본 원인. IMU는 향후 하드웨어 확장 항목으로 별도 기록.
- **다음 검증 필요**: 튜닝 반영 후 실제로 걸어다니며 `/map`(scan 누적 아님)이
  이전보다 덜 어긋나는지 사용자가 직접 재검증 필요 (이 세션에서는 파라미터만 적용,
  라이다 재연결 실측 테스트는 아직 안 함).

## 추가 진행 (2026-09-04, "찌꺼기 데이터 필터링" 요청 → occupancy grid 확정 기준 튜닝)
- 사용자 질문: 정지 상태로 테스트해도 중복/찌꺼기 데이터를 걸러내는 기능이 없어
  보인다, 최종 목표가 "사용자가 깔끔하게 볼 지도 데이터"인데 그게 안 됨.
- **설명**: 이 "걸러내는 기능"은 이미 존재 — `/map`(occupancy grid)이 원본 점을
  그대로 쌓는 게 아니라 격자 칸마다 "몇 번 부딪혔는지"를 누적해서 일정 기준을
  넘어야 벽으로 확정하는 방식(`min_pass_through`, `occupancy_threshold`). 다만
  기본값(2번, 10%)이 너무 낮아서 튀는 반사 노이즈 한두 번도 벽으로 오인될 여지가 있었음.
- **적용한 튜닝**: `min_pass_through` 2→4, `occupancy_threshold` 0.1→0.35로 상향
  (확정 기준을 높여서 노이즈가 최종 지도에 덜 남게 함).
- **사용자에게 안내한 검증 방법**: `/scan`(원본, 항상 지저분함이 정상)과 `/map`
  (정제된 최종 결과)을 구분해서 봐야 한다 — Foxglove에서 `/scan`의 point
  decay/history를 줄이거나 레이어를 끄고 `/map`만 보고 판단할 것. 정지 테스트부터
  `/map` 기준으로 깔끔한지 재확인 필요.

## 다음 단계
- `./docker/run_dev.sh --with-lidar`로 실제 라이다 mock/실기 파이프라인(`bringup.launch.py`) 실행
- Foxglove(`studio.foxglove.dev` 또는 데스크톱 앱)로 `ws://localhost:9090` 접속해서
  `/scan` 시각화 확인 — 사용자가 요청했던 "라이다 작동 확인"의 마지막 단계
- Flutter 앱에서 rosbridge(9090) 붙는 최소 화면 (연결 상태 표시 정도부터)
- `lidar_mapper_bringup`에도 `lidar_mapper_db`의 `session_logger_node`를 launch에 포함

## 참고 (에러 로그/명령어 등)
```
# 실행파일 위치 문제 재현/확인
$ ros2 pkg executables lidar_mapper_db   # (수정 전) 빈 결과
$ find install/lidar_mapper_db -maxdepth 3   # bin/session_logger_node 로 잘못 설치됨

# setup.cfg 추가 후
$ ros2 pkg executables lidar_mapper_db
lidar_mapper_db session_logger_node

# 세션 저장 검증
$ ros2 topic pub --once /session_event std_msgs/String '{data: "거실 스캔 완료"}'
$ ros2 topic pub --once /session_end std_msgs/String '{data: "/lidar_ws/maps/test.pgm"}'
# sqlite: (1, '2026-09-01T03:52:23...', ..., '/lidar_ws/maps/test.pgm', '거실 스캔 완료 / 주방 스캔 완료')
```

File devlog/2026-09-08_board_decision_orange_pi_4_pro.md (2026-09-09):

# 2026-09-08 개발 로그 — 보드 결정: Raspberry Pi 5 → Orange Pi 4 Pro

## 오늘의 목표
- Pi5 가격 급등 문제를 해결할 대안 보드 조사 및 결정

## 진행 내용
- Pi5 실구매가가 LPDDR4 메모리 품귀로 정가 대비 크게 뛴 상태라 대안 SBC를
  사용자와 함께 하나씩 검토함 (AliExpress 실제 매물 스크린샷 기반):
  1. **Orange Pi Zero 3** (Allwinner H618, 쿼드코어 A53) — CPU가 slam_toolbox
     실시간 연산엔 너무 약함. 게다가 4GB 모델은 91,800원으로 더 강한 대안보다 비쌈 → 기각
  2. **Orange Pi 5 / 5 Max** (RK3588S/RK3588) — 스펙은 원래 추천이었지만,
     실제 매물이 상위 모델(Max, 8GB부터 시작)과 혼동되거나(26만원), 판매 이력이
     의심스러운 리스팅(1개 판매, 가짜 할인 패턴 "원가 511,500→60%할인")만 걸림
  3. **Orange Pi 4 Pro** (Allwinner A733, **2x Cortex-A76 + 6x Cortex-A55**,
     4GB LPDDR5, ₩74,800, 600+ 판매/4.6점) — 상세 스펙 확인 결과 빅코어(A76) 2개
     포함된 실제 쓸만한 구성. GPIO 40핀에 I2C/SPI/UART 지원(향후 IMU 확장에 유리),
     M.2 NVMe, USB-C 5V/3A 입력(보조배터리 구동 적합) 등 프로젝트에 필요한 확장성도 갖춤.
- **최종 결정: Orange Pi 4 Pro 4GB.** RK3588S(Orange Pi 5)보다 빅코어 2개
  적어(2 vs 4) 이론상 약간 아래지만, 검증된 판매 이력과 확장 포트, 그리고 지금
  가격이 비정상인 Pi5보다 훨씬 합리적인 가격이라는 점에서 실용적 최선책으로 판단.
- `README_ARCHITECTURE.md` 갱신: 0번 확정사항 표, 5.4 로드맵, 6번 리스크 섹션에
  보드 변경 사유 기록. `hardware/tumbler_mount_design.md`의 "Pi5" 언급도
  "보드(Orange Pi 4 Pro)"로 갱신(치수 자체는 아직 실측 전이라 변경 없음).

## 막힌 문제 & 해결
| 증상 | 원인 | 해결 방법 |
|---|---|---|
| 같은 "Orange Pi 4 Pro" 상품인데 리스팅마다 정보가 달라 보임 | 같은 보드를 여러 판매자가 각각 다른 스펙 배너(Wi-Fi5 vs Wi-Fi6)로 광고, 판매량/평점만 다름 | 판매량·평점 높은 리스팅을 신뢰 기준으로 선택 |
| "Orange Pi 5" 검색 결과에 상위 모델(5 Max, 5 Plus)이 섞여 나와 가격이 이상하게 비쌈 | Orange Pi는 같은 세대 안에 여러 등급(5/5 Plus/5 Max)이 있고 Max는 4GB 옵션이 아예 없음 | 모델명 뒤의 Plus/Max 여부를 반드시 확인하도록 정리 |

## 다음 단계
- Orange Pi 4 Pro 4GB 실제 구매
- 도착 후: `docker/` 이미지를 arm64로 빌드해서 그대로 이식되는지 검증 (Docker
  기반 아키텍처의 핵심 전제 — 보드가 바뀌어도 이 부분은 원래 설계 그대로 유효)
- 그 전까지는 Phase 1(고정 공간, PC+RViz2)로 SLAM 파라미터 품질 계속 검증

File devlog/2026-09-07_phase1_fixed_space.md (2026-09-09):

# 2026-09-07 개발 로그 — Phase 1(고정 공간 검증) 정의 & RViz2 도입

## 오늘의 목표
- Pi5 도착 전까지의 개발 단계를 명확히 정의하고 문서/도구에 반영
- 정지 테스트 중 발견된 방사형 노이즈 문제의 진짜 원인 파악

## 진행 내용
- **긴 진단 세션**: 화면 캡처로 방사형(별 모양) 노이즈 패턴을 여러 차례 재현/분석.
  - 원본 `/scan`은 실제로 깨끗함(720개 중 620개 유효, 큰 튐 거의 없음) → 문제는
    지도 합성(occupancy grid) 과정에 있다고 판단.
  - `correlation_search_space_dimension`을 0.5→1.0으로 넓혔더니 `Message Filter
    dropping message ... queue is full` 경고가 2.6초마다 반복 → 계산량 증가로
    처리가 밀려서 스캔이 버려지는 부작용으로 추정, 되돌림(0.5 유지) +
    `transform_timeout` 0.2→0.5로 여유 확보.
  - **결정적 함정 발견**: 컨테이너가 대화 세션 사이(2026-09-04~07, 실제 3일)
    계속 켜진 채 방치되어 있었음. 이후 관찰한 "점점 커지고 촘촘해지는 별 모양"은
    그 3일 동안 쌓인 로그/맵이었을 뿐, 방금 바꾼 설정을 반영한 결과가 아니었음.
    컨테이너를 완전히 새로 띄워서 재검증하니 rf2o yaw가 -0.007~-0.009 rad로
    안정적이고 `queue is full` 경고도 재발하지 않음 → 최소한 그 세션 시점 설정으로는
    정상 동작 확인. (진짜 "정지 상태 지도 품질"은 다음 세션에서 Phase 1 절차대로
    재검증 필요.)
- **RViz2 도입 결정**: Foxglove는 색상 모드를 임의로 커스텀할 수 있어(노랑/파랑 등)
  점유/빈공간 판단을 헷갈리게 만들 수 있음을 확인. RViz2는 기본 흑백이라 더
  정확한 디버깅 도구. 다만 로컬 GUI라 폰 원격 접속이 안 되므로, 휴대 단계(Phase 2)의
  Foxglove를 대체하지 않고 지금 단계 전용 도구로 도입.
  - Claude가 X11 화면을 직접 캡처할 수 있는지 확인(`gnome-screenshot`, DISPLAY=:0
    접근 가능) → 실제로 캡처 성공, 앞으로 RViz2 화면도 직접 보고 판단 가능.
- **개발 단계(Phase) 정의**: Phase 1(현재, PC+고정 공간, RViz2 위주) vs
  Phase 2(Pi5 도착 후, 휴대 이동, Foxglove 위주)로 명확히 구분해서
  `README_ARCHITECTURE.md` 5.3에 표로 정리.

## 변경한 파일
- `docker/Dockerfile`: `ros-humble-rviz2` 추가
- `docker/run_dev.sh`: `--rviz` 옵션 추가 (X11 전달), 컨테이너 방치 경고 주석 추가
- `docker/README.md`: RViz2 사용법 섹션 추가
- `config/rviz_default.rviz` 신규: Map/LaserScan/TF/Grid 기본 세팅
- `README_ARCHITECTURE.md`: 5.3 Phase 정의, 5.4 로드맵/리스크 갱신

## 막힌 문제 & 해결
| 증상 | 원인 | 해결 방법 |
|---|---|---|
| 튜닝해도 지도가 계속 지저분해 보임 | 컨테이너를 3일간 방치, 관찰 중인 화면이 최신 설정 반영이 아니라 3일치 누적 데이터였음 | 테스트 전 항상 컨테이너 재시작하는 규칙을 문서(`README_ARCHITECTURE.md` 6번, `docker/run_dev.sh` 주석)에 명시 |
| correlation_search_space 확대가 오히려 역효과 | 계산량 증가 → 처리 지연 → tf2 MessageFilter 큐 초과로 스캔 유실 | 0.5로 원복, `transform_timeout` 0.5로 확대해 여유 확보 |

## 다음 단계
- Phase 1 절차대로 **깨끗하게 재시작한 컨테이너**에서 RViz2로 정지 상태 지도 품질
  재검증 (지금까지의 진단은 방치된 컨테이너로 오염되어 있었으므로 원점에서 재확인 필요)
- `min_pass_through`/`occupancy_threshold` 튜닝(4, 0.35)이 실제로 효과 있는지도
  이번 재검증에서 같이 확인
- 이후 Phase 2(Pi5 도착) 전까지는 Flutter 앱, 텀블러 마운트 등은 우선순위 낮음

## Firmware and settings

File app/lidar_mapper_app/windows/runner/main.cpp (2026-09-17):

#include <flutter/dart_project.h>
#include <flutter/flutter_view_controller.h>
#include <windows.h>

#include "flutter_window.h"
#include "utils.h"

int APIENTRY wWinMain(_In_ HINSTANCE instance, _In_opt_ HINSTANCE prev,
                      _In_ wchar_t *command_line, _In_ int show_command) {
  // Attach to console when present (e.g., 'flutter run') or create a
  // new console when running with a debugger.
  if (!::AttachConsole(ATTACH_PARENT_PROCESS) && ::IsDebuggerPresent()) {
    CreateAndAttachConsole();
  }

  // Initialize COM, so that it is available for use in the library and/or
  // plugins.
  ::CoInitializeEx(nullptr, COINIT_APARTMENTTHREADED);

  flutter::DartProject project(L"data");

  std::vector<std::string> command_line_arguments =
      GetCommandLineArguments();

  project.set_dart_entrypoint_arguments(std::move(command_line_arguments));

  FlutterWindow window(project);
  Win32Window::Point origin(10, 10);
  Win32Window::Size size(1280, 720);
  if (!window.Create(L"lidar_mapper_app", origin, size)) {
    return EXIT_FAILURE;
  }
  window.SetQuitOnClose(true);

  ::MSG msg;
  while (::GetMessage(&msg, nullptr, 0, 0)) {
    ::TranslateMessage(&msg);
    ::DispatchMessage(&msg);
  }

  ::CoUninitialize();
  return EXIT_SUCCESS;
}

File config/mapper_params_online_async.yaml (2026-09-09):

slam_toolbox:
  ros__parameters:

    # Plugin params
    solver_plugin: solver_plugins::CeresSolver
    ceres_linear_solver: SPARSE_NORMAL_CHOLESKY
    ceres_preconditioner: SCHUR_JACOBI
    ceres_trust_strategy: LEVENBERG_MARQUARDT
    ceres_dogleg_type: TRADITIONAL_DOGLEG
    ceres_loss_function: None

    # ROS Parameters
    odom_frame: odom
    map_frame: map
    base_frame: base_footprint
    scan_topic: /scan
    use_map_saver: true
    mode: mapping #localization

    debug_logging: false
    throttle_scans: 1
    transform_publish_period: 0.02 #if 0 never publishes odometry
    # 기본값 5.0초 -> 0.5초. 휴대용 기기는 사람이 걷는 속도라 5초 대기는 너무 느려서
    # 새 공간으로 이동해도 화면(Foxglove /map)이 한참 뒤에야 갱신되는 것처럼 보였음.
    map_update_interval: 0.5
    resolution: 0.05
    min_laser_range: 0.0 #for rastering images
    max_laser_range: 20.0 #for rastering images
    minimum_time_interval: 0.5
    # 0.2초는 너무 빠듯해서 처리가 살짝 밀리면 "Message Filter dropping message ...
    # queue is full" 경고와 함께 그 스캔이 통째로 버려짐(원인: 2026-09-04 진단).
    # 여유를 줘서 스캔 유실을 줄임.
    transform_timeout: 0.5
    tf_buffer_duration: 30.
    stack_size_to_use: 40000000 #// program needs a larger stack size to serialize large maps
    enable_interactive_mode: true

    # General Parameters
    use_scan_matching: true
    use_scan_barycenter: true
    # 기본값(0.5m, 0.5rad)은 바퀴 로봇 기준. 사람 도보 속도/회전이 더 빠르고 급격해서
    # config/slam_params_notes.md에서 이미 예상했던 대로 낮춤 (config/slam_params_notes.md 참고).
    # 단, 0.2rad까지 낮췄더니 손으로 빠르게 홱홱 돌릴 때의 순간적인(잡음 섞인) 회전까지
    # 다 스캔 처리 대상이 되어 지도가 지저분해지는 부작용이 있어 0.35로 살짝 올림 —
    # 응답성과 잡음 내성 사이의 절충.
    minimum_travel_distance: 0.1
    minimum_travel_heading: 0.35
    scan_buffer_size: 10
    scan_buffer_maximum_scan_distance: 10.0
    link_match_minimum_response_fine: 0.1
    link_scan_maximum_distance: 1.5
    loop_search_maximum_distance: 3.0
    do_loop_closing: true
    loop_match_minimum_chain_size: 10
    loop_match_maximum_variance_coarse: 3.0
    loop_match_minimum_response_coarse: 0.35
    loop_match_minimum_response_fine: 0.45

    # Correlation Parameters - Correlation Parameters
    # 한 번 1.0m로 넓혀봤다가 되돌림(2026-09-04): 넓힐수록 스캔 1개당 계산량이
    # 늘어서 처리가 밀리고, 그 결과 "Message Filter dropping message ... queue is
    # full"로 스캔이 버려지면서 오히려 지도가 방사형으로 지저분해지는 부작용을
    # 직접 확인함. 기본값(0.5m) 유지.
    correlation_search_space_dimension: 0.5
    correlation_search_space_resolution: 0.01
    correlation_search_space_smear_deviation: 0.1

    # Correlation Parameters - Loop Closure Parameters
    loop_search_space_dimension: 8.0
    loop_search_space_resolution: 0.05
    loop_search_space_smear_deviation: 0.03

    # Scan Matcher Parameters
    distance_variance_penalty: 0.5
    angle_variance_penalty: 1.0

    fine_search_angle_offset: 0.00349
    coarse_search_angle_offset: 0.349
    coarse_angle_resolution: 0.0349
    minimum_angle_penalty: 0.9
    minimum_distance_penalty: 0.5
    use_response_expansion: true
    # 격자 한 칸을 "벽"으로 확정하기 전에 몇 번 부딪혀야 하는지(min_pass_through)와
    # 몇 %나 부딪혀야 하는지(occupancy_threshold). 기본값(2번, 10%)은 너무 낮아서
    # 튀는 반사/노이즈 한두 번에도 벽으로 오인됨 -> 확정 기준을 높여서 "찌꺼기"
    # 데이터가 최종 지도에 남지 않도록 함. map_update_interval을 0.5초로 낮춰둬서
    # 확정이 늦어지는 체감은 크지 않음.
    # 2026-09-08: 4/0.35는 너무 느리게 느껴진다는 피드백으로 3/0.25로 완화
    # (노이즈 억제와 반응 속도 사이 절충, 필요하면 다시 조정).
    min_pass_through: 3
    occupancy_threshold: 0.25

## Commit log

2026-09-09 docs: write project README with architecture overview and data-flow diagram
    First-screen guide for the repo: current dev phase, Mermaid data-flow
    diagram, quick-start Docker commands, hardware summary, and repo structure
    table. Complements the detailed README_ARCHITECTURE.md.
2026-09-09 feat: ROS2 workspace - mock, bringup, and DB logging packages
    - lidar_mapper_mock: fake /scan publisher for hardware-free development
    - lidar_mapper_bringup: integrated launch (mock/real lidar, rf2o odometry,
    slam_toolbox with tuned params, rosbridge+rosapi)
    - lidar_mapper_db: session_logger_node, subscribes to manual
    /session_event and /session_end topics, summarizes via ai/ provider and
    persists to SQLite
2026-09-09 feat: Docker development environment (ROS2 Humble, arch-independent)
    Dockerfile builds ROS2 Humble + slam_toolbox + rosbridge + rviz2, with
    sllidar_ros2 and rf2o_laser_odometry compiled from source as fixed
    overlays. run_dev.sh wraps docker run for mock/real-lidar/RViz2 modes with
    proper USB (dialout) and X11 passthrough, log rotation, and host-UID
    execution. README documents PC/WSL2/Mac usage differences and known
    gotchas (lidar reconnect after driver crash, stale-container pitfall).
2026-09-09 feat: tuned slam_toolbox params and RViz2 default layout
    mapper_params_online_async.yaml tunes map_update_interval, travel
    thresholds, correlation search space, and occupancy confirmation
    (min_pass_through/occupancy_threshold) for handheld walking-pace mapping
    instead of the wheeled-robot defaults. rviz_default.rviz preloads
    Map/LaserScan/TF/Grid so Phase 1 debugging doesn't need manual setup.
    [mapper_params_online_async.yaml]
2026-09-09 feat: scaffold Flutter mobile viewer app
    lidar_mapper_app (Android target) via 'flutter create'. Not yet wired to
    rosbridge - planned for Phase 2 once portable hardware arrives.
2026-09-09 docs: hardware notes - tumbler mount design and board price tracking
    Tumbler mount design draft (unmeasured), plus board selection research:
    spec comparison, price observation log (Raspberry Pi vs Orange Pi, incl.
    the 2026 AI-driven DRAM shortage affecting both), and Orange Pi 4 Pro
    bring-up risk predictions (thermal, OS/community maturity, USB, power).
2026-09-09 docs: development session logs (2026-08-19 through 2026-09-08)
    Chronological record of the project from architecture kickoff through
    Docker setup, first hardware bring-up, SLAM/odometry debugging, and the
    Orange Pi 4 Pro board decision. See devlog/TEMPLATE.md for the format.
2026-09-10 docs: fix stale Raspberry Pi 5 references after Orange Pi 4 Pro decision
    The board-decision commit only updated the summary table; the ASCII
    diagrams, parts list, roadmap step 6, and Phase definitions further down
    still said "Raspberry Pi 5" / "Pi5". Swept the whole file for remaining
    references.
2026-09-10 docs: fix remaining Raspberry Pi 5 references, sync roadmap with recent decisions
    Sweeps the whole file this time (not just the summary table) for stale
    board references. Also records the manual map-correction app feature
    design and the new "session state/reset panel" app feature idea.
2026-09-10 docs: IMU mounting plan, dimension-based fit check, and camera idea
    - 1.5: IMU mount plan (co-locate with lidar on the flattening disk,
    shared cable channel, I2C wiring)
    - 1.7: scale check using real component dimensions (RPLIDAR C1, Orange Pi
    4 Pro 89x56mm, IMU) - a full custom hard case isn't needed, but an
    internal bracket to stand the board upright still is
    - 7: camera add-on idea recorded as a post-Phase-2 nice-to-have
    (semantic labeling only, not a fix for occlusion/fast-rotation
    accuracy - IMU remains the right tool for those)
2026-09-10 docs: detailed Orange Pi bring-up procedure and session devlogs
    Adds an anticipated step-by-step setup procedure (OS image, network/SSH,
    Docker install, project bring-up, GPIO/I2C activation, thermal
    monitoring) to the bring-up risks doc, based on Armbian conventions -
    to be overwritten with real commands once the board arrives.
    Devlogs cover: fixing stale README references, architecture/hardware
    documentation pass, and today's camera-idea + map-storage clarification
    (map lives in RAM, not disk; also caught another stale-container
    oversight, this time my own).
2026-09-15 docs: Flutter 앱 + 데이터 동기화 + 라이다 한계 극복 확장 아키텍처 반영
    온디맨드 연결, Store-and-Forward, 관계형 DB 스키마, 진화형 지도 축적,
    laser_filters+robot_localization(EKF) 기반 라이다 한계 극복 전략을
    README_ARCHITECTURE.md 3.5번으로 추가. Phase 2를 하드웨어 도착 순서
    기준 페이지 0~3으로 세분화(5.5번)하고 부품 체크리스트 정리.
    Claude-Session: https://claude.ai/code/session_01DeUxyVHUrbr4B8zvSap3XM
2026-09-15 docs: README 첫화면 요약 갱신 + 2026-09-15 devlog 기록
    확장 설계(온디맨드 연결/Store-and-Forward/DB스키마/진화형 지도/라이다
    한계 극복) 요약과 다이어그램 링크를 README.md에 반영, Phase 2 세부
    페이지(0~3) 안내 추가. 오늘 세션 논의/결정 사항을 devlog로 기록.
    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
2026-09-17 docs: 부속품 구매기록/데이터시트/CAD 초안 + 브링업 체크리스트 정리
    RPLIDAR C1, BNO055, Orange Pi 4 Pro 공식 데이터시트 확보 및 GPIO
    핀맵/부팅매체/발열모니터링 등 브링업 미확인 사항 해소. 마운트
    평판+케이스 OpenSCAD 초안과 부속품 구매 내역을 기록.
    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
    [frame_harness_v0.scad, mount_plate_and_case_v1.scad, tumbler_shell_v1.scad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]
2026-09-17 feat: Flutter 앱 Tier1 착수 — 연결 화면 + 데스크탑 플랫폼 추가
    rosbridge WebSocket 연결 화면(Riverpod MVVM) 구현, Linux/Windows
    데스크탑 빌드 타겟 추가(android만 있던 상태에서 확장). 스캔/노이즈필터/
    누적지도 UI 데모(CustomPainter 구현 전 컨셉 검증)도 백업 보관.
    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
2026-09-17 docs: README에 폼팩터 히스토리(텀블러→어깨끈 마운트) + 참고사진 반영
    텀블러형 초기 개념부터 GoPro 커넥터 방식 확정까지의 폼팩터 변경
    과정을 collapse 섹션으로 정리. 사용자 스케치, 개념도 SVG, 실제
    구매한 마운트 제품 사진, Shapr3D 렌더링, 최종 목업 렌더링 추가.
    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
2026-09-17 docs: 목업 렌더를 하드웨어 섹션 상단에 노출 + 스케치 썸네일 축소
    가방 장착 목업(sample-bag1,2)을 collapse 밖으로 꺼내 대표 이미지로
    나란히 배치. 스케치/개념도는 원본 링크 대신 작은 썸네일로 임베드해서
    클릭 시 큰 원본이 바로 열리던 문제 해결.
    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
2026-09-17 feat: 게이트→4탭 셸 네비게이션 뼈대 구현 + 구조 문서 Artifact 게시
    go_router의 StatefulShellRoute로 연결화면→홈/트래킹/목록/설정 4탭 셸을
    구성하고, 연결 성공 시 자동으로 홈 탭 이동하도록 연결. 각 탭은 다음
    단계에서 채울 placeholder 상태. ARCHITECTURE.md에 구조를 시각화한
    Claude Artifact 링크도 추가.
    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
